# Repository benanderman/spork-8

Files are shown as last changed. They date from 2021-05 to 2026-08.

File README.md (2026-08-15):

# Spork-8

This is an 8-bit computer project, inspired by [Ben Eater's 8-bit breadboard computer](https://eater.net/8bit). It's made out of modular PCBs that plug into each other, and contain mostly 74HC-series chips (original 74LS). It runs code from an EEPROM (so it's only programmable from a computer), and has separate memory. It's meant to display what's happening, when running on a 555-timer or manually stepping, but also be capable enough to implement some sort of game, when using an oscillator as a clock.

## Status of project

The project was originally completed in 2021 and mostly worked with 74LS-series chips, but it had some issues (see [RevisionLog](RevisionLog.md)), and used way too much power.

In 2025, it was rebuilt with 74HC-series chips, and several improvements, an emulator, and peripheral boards. It had some issues, but mostly worked well.

In 2026, reliability was improved by adding ground planes to the bus boards and control board, the instruction set was improved, and much more complex programs were made.

## Modules
 * **Control module**: Coordinates everything else. Contains the micro-code EEPROMs, instruction register, micro-instruction counter, power input, reset button, and logic to interface with modules through bus boards.
 * **Bus**: Four of these interface between the control module and up to 16 other modules. These demux three signal lines each for in/out enable signals to the four modules connected to each bus board. One bus board plugs into the top of the control module, and one into the bottom. Two more bus boards plug into the first two. The first in/out signal line selects between the two boards on top / bottom, and the one connected to the control module inverts the signal before passing it onto the other bus board.
 * **Register**: Stores 8 bits, and can connect directly to an adjacent board above or below to expose its value (for use by the ALU and shift / rotate module). Has output headers, to interface with peripherals.
 * **ALU**: Performes calculations on values from register modules above and below it. Can output: add, subtract, bit-wise AND, or the carry-bit and zero-flag for any of those operations. Must be placed in the 1111 position (bottom right of top-most bus board), because the control module is hard-wired to input to the flags register when the read signal to that module position is enabled, which also enables flag output on the ALU.
 * **Clock**: Provides the clock pulse for the computer. Has three modes: manual with button to pulse, 555-timer with potentiometer to adjust timing, or crystal oscillator (2MHz seems to work).
 * **Counter**: Stores and counts 16-bit values. Uses two global signal lines to select which byte to read / write, and whether to enable counting. Used for both the RAM address register and program counter / program memory address register.
 * **RAM**: RAM or EEPROM (they have the same pinout). Used for the program memory EEPROM (not intended to be written to), and the static memory used for storing data. Up to 15-bits of address are taken from an adjacent counter module. Also has a cartridge slot, and switches between it and the EEPROM on the board using the 16th address bit. This allows swapping out programs much easier
 * **Input / Output**: Like a register module, except when outputting to the bus, outputs the value from input headers instead of the registers. The 8-bit value stored in the registers is accessible on output headers as well. The two headers are in parallel, making it sturdy to plug in a peripheral that uses both.
 * **Battery**: Has a battery, charging capability with USB-C, and a switch to output power to the CPU.

## Layout

In general, any of the 16 module slots can input from or output to the bus, so most modules could go in any position. However, some of them have to go in specific slots, because:

1. The 0th slot on the top and bottom aren't usable for in/out selection, because it's ambiguous whether that slot is selected or if no module on that side is selected. The battery and clock go in those slots, since they only output power and a clock signal, and don't use the bus.
1. The 8 "custom" signals (that mean something different for different modules) are split up into 4 for top, 4 for bottom. Those 4 are split into pairs; the top 2 modules on each bus board get one pair, and the bottom two get the second pair. The second pair of signals on the bottom is actually used by the control board.
1. Some modules (RAM / ROM, ALU, and Shift) get inputs from other modules, so their inputs have to be next to them.

**Top left**: The program counter goes in the top to use the first pair of custom signals (for count and byte select), plugging into the program memory below it. Below that is the clock (in the 0th position), and Register C.

**Top right**: The ALU goes one slot down from the top, to use the second pair of custom signals (for add/subtract and bit-wise AND), with register A and B as its operands above and below. Then the shift / rotate module goes at the bottom plugging into register B. These need to be on the right side to avoid the 0th position. The shift module shares custom signals with the ALU, which is okay because only one is used at a time, and the signals don't have an effect if that module isn't outputting.

**Bottom left**: The battery takes the top 0th slot, and then the stack and swap registers, and input / output A module after that. Other than the battery, the positions are arbitrary.

**Bottom right**: The output A register goes at the top and the RAM goes below it. The memory address register goes in the next position to get the first pair of custom signals (for count and byte select), and plugs into the RAM above it. The input / output B module goes at the bottom. The memory address could instead go where output A is, and RAM just needs to be next to it. The other two could go anywhere.

## Peripherals
* **Controller Connector**: Plugs into IO module, and has two RJ12 plugs on it, to connect to parallel-to-serial shift register-based controllers.
* **Screen**: An 10x20 595-shift register-based monochrome display. Plugs into output module (vertically), or IO module (horizontally).
* **Cartridge**: A small board with a surface-mount version of the same 28C256 EEPROM used as in the program memory module. Plugs into the program memory module with the smallest PCIe board edge connector.
* **Programmer**: Arduino-based board used to program and test the CPU in 3 ways:
    1. Separate from the CPU, read / write to EEPROMs (big ones, or cartridges).
    2. Plug into bus boards, to test all the modules plugged in (doesn't work, because the bus is needed to set the signals, but that could cause bus contention).
    3. Replace the program memory and clock, to have a very fast development cycle to write program code (not necessary now that there's an emulator), or to test the CPU.
 
## Layout, signals, and parts list
These images show the layout of the modules in the 16 slots, the functions of each of the signals, and a parts list.
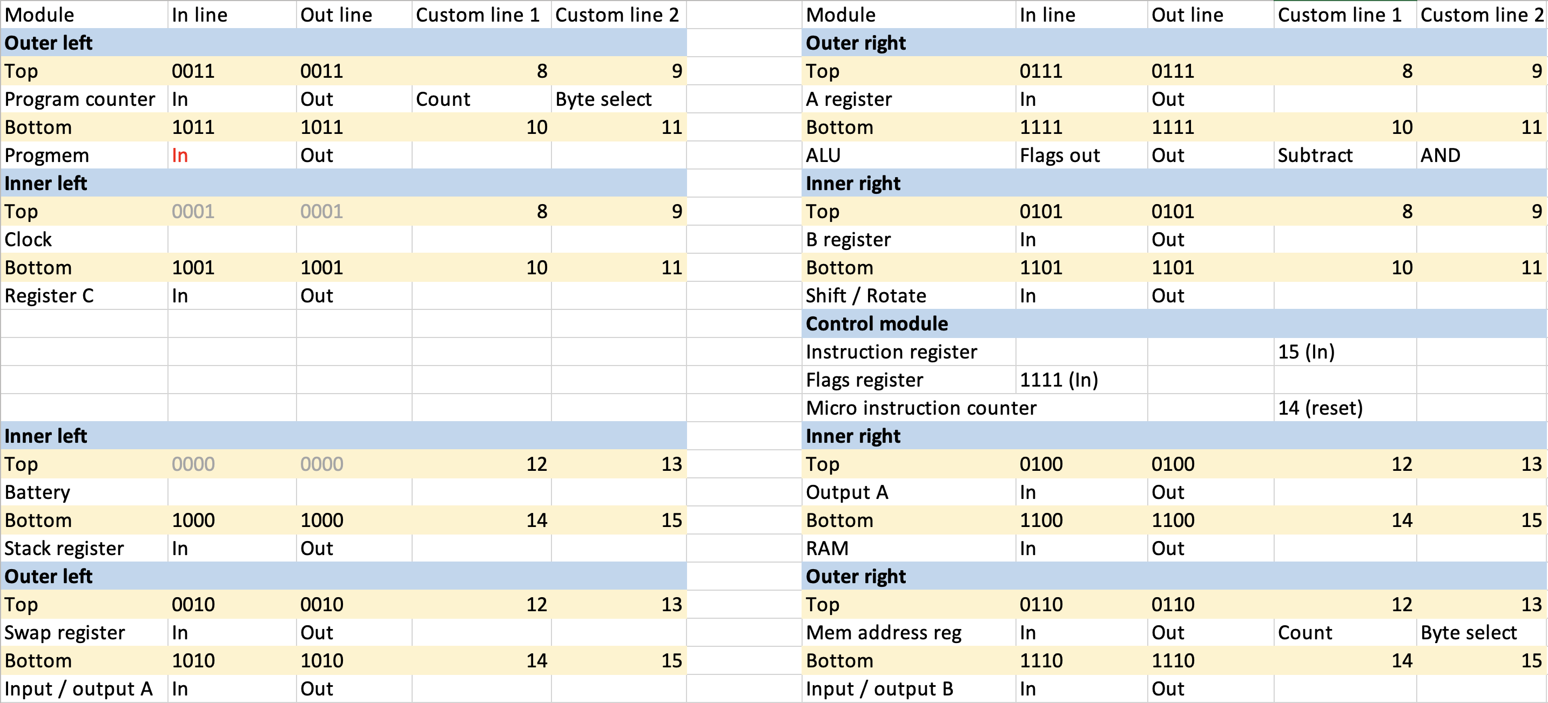
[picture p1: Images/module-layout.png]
Module layout

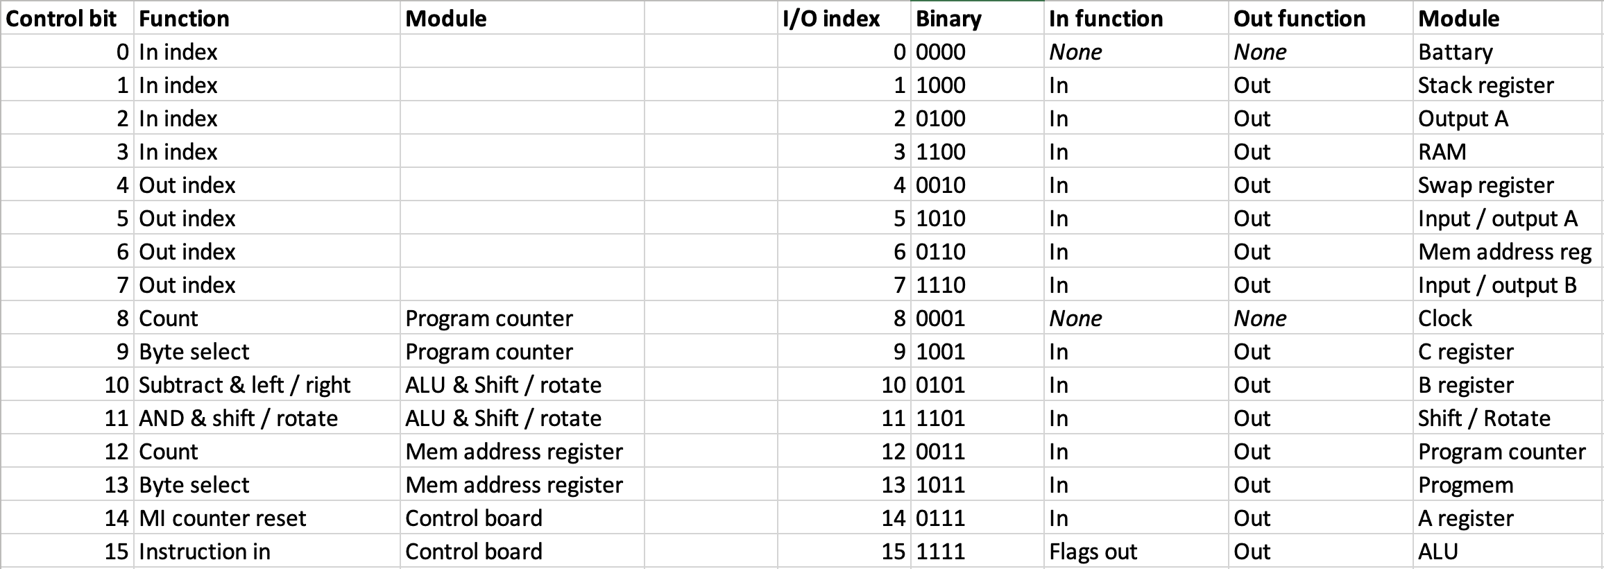
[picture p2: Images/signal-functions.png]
Signal functions

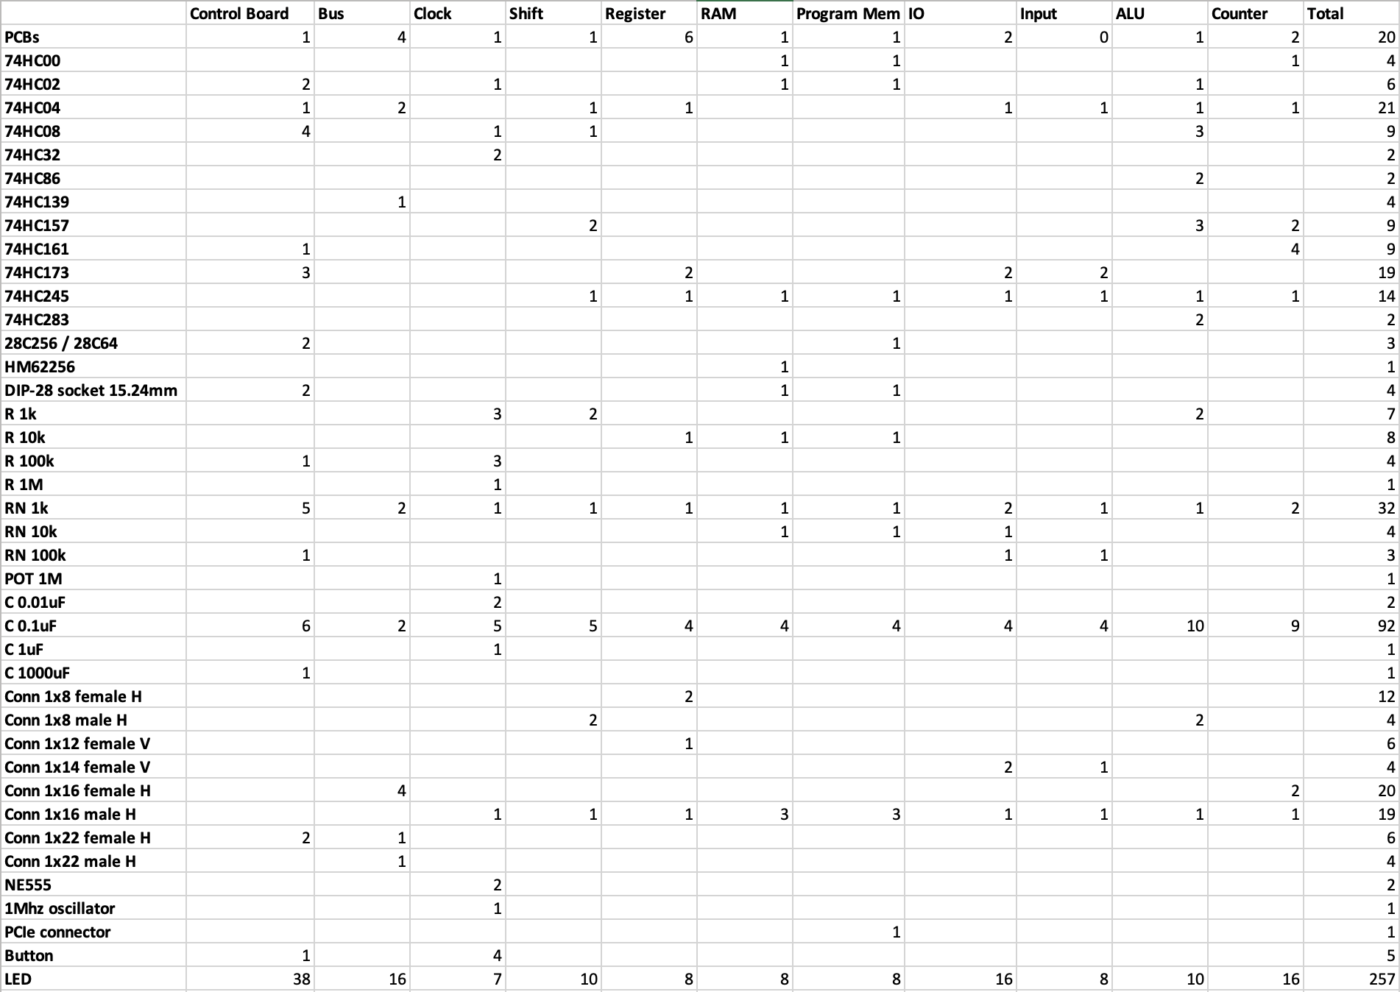
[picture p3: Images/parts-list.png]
Parts list


## Design images
### Overall layout
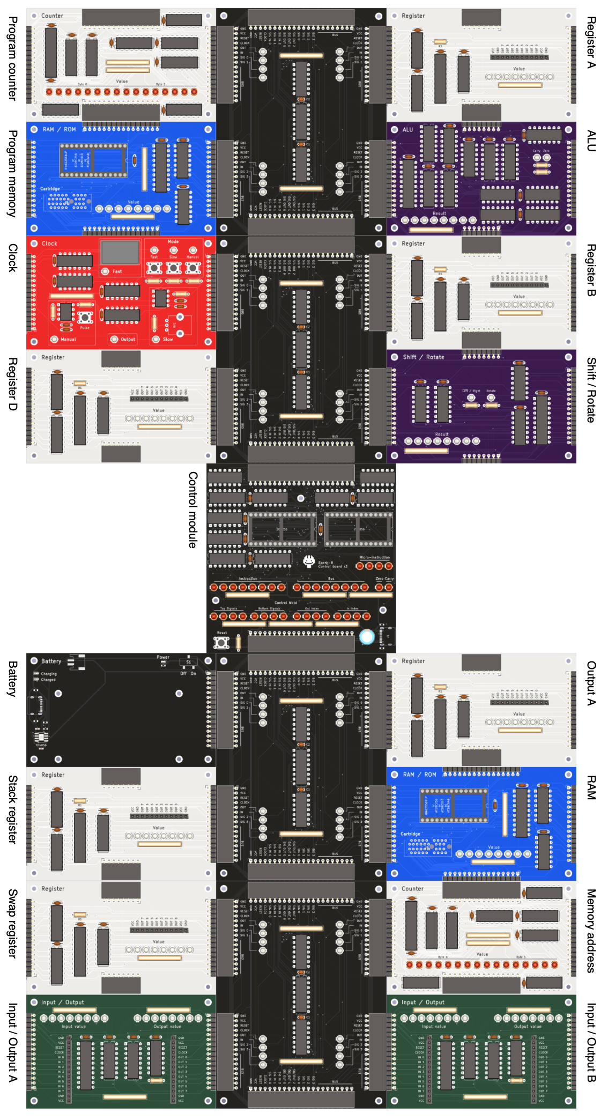
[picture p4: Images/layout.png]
Layout of the CPU


### Mounting board (laser cut acrylic)
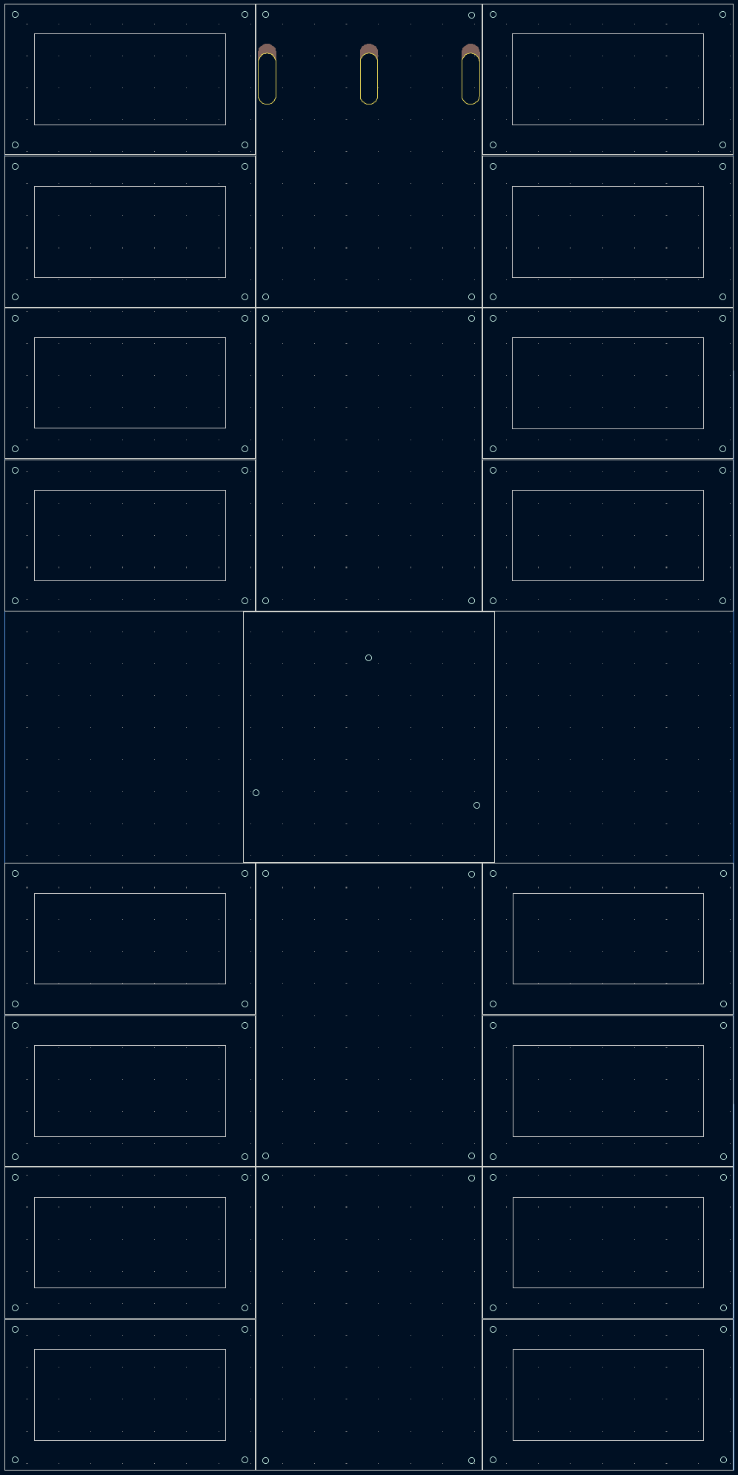
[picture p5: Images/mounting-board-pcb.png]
Mounting board design


### Schematics
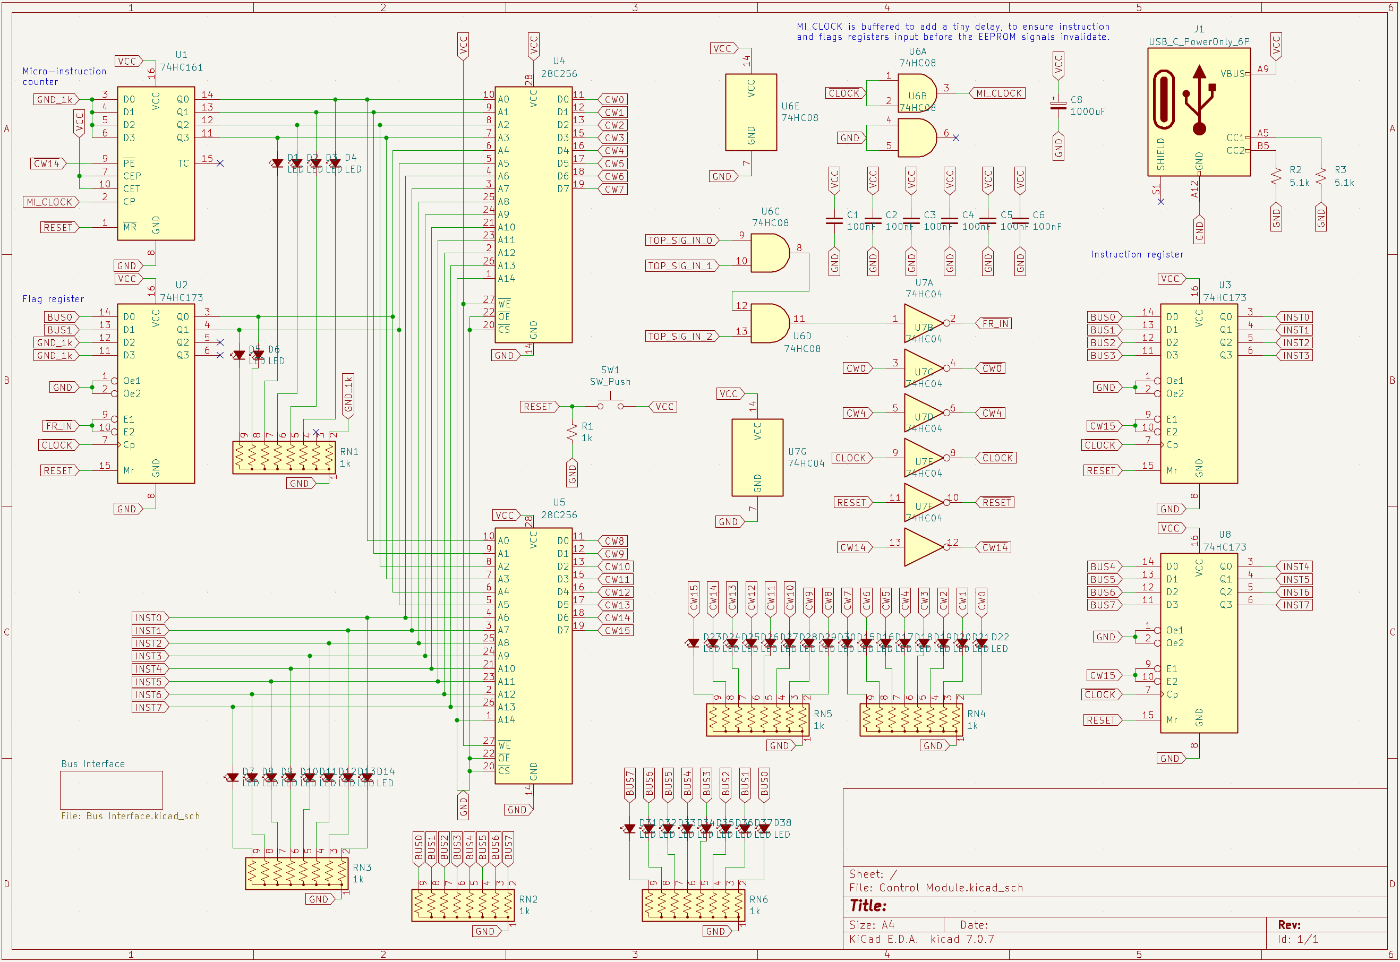
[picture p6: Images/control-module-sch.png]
Control Module schematic

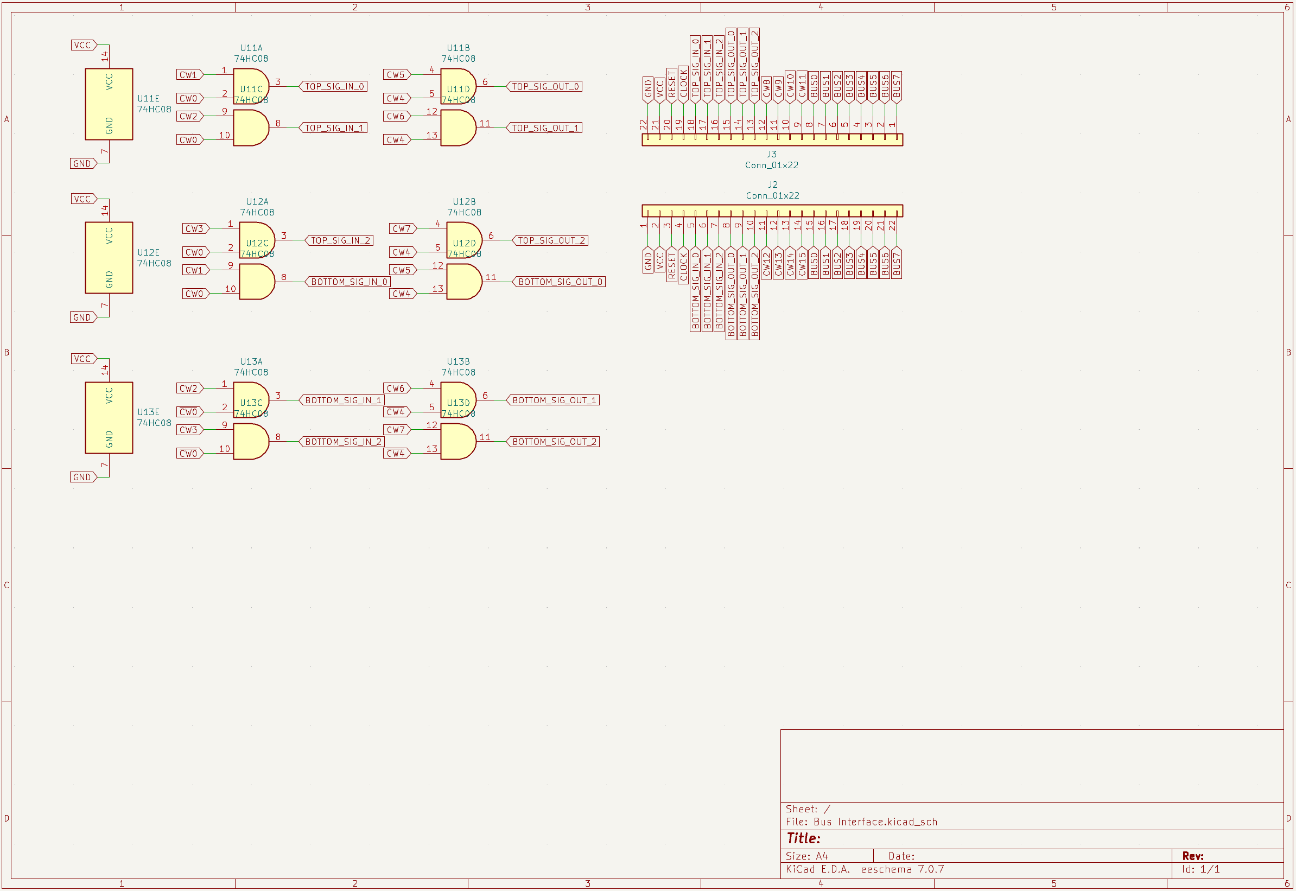
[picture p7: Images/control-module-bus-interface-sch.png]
Control Module bus interface schematic

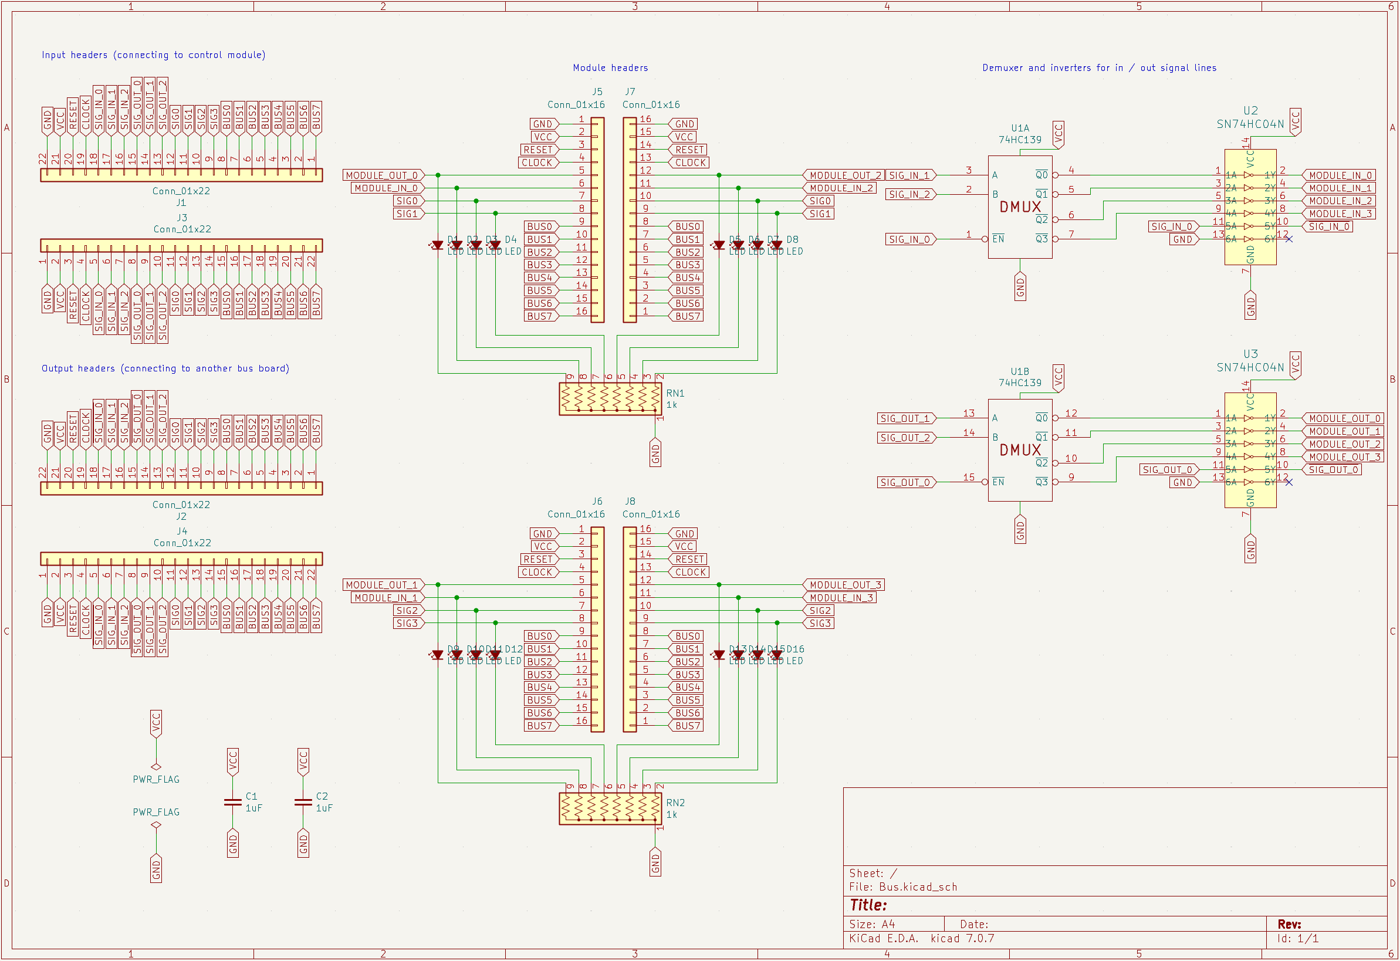
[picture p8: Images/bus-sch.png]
Bus schematic

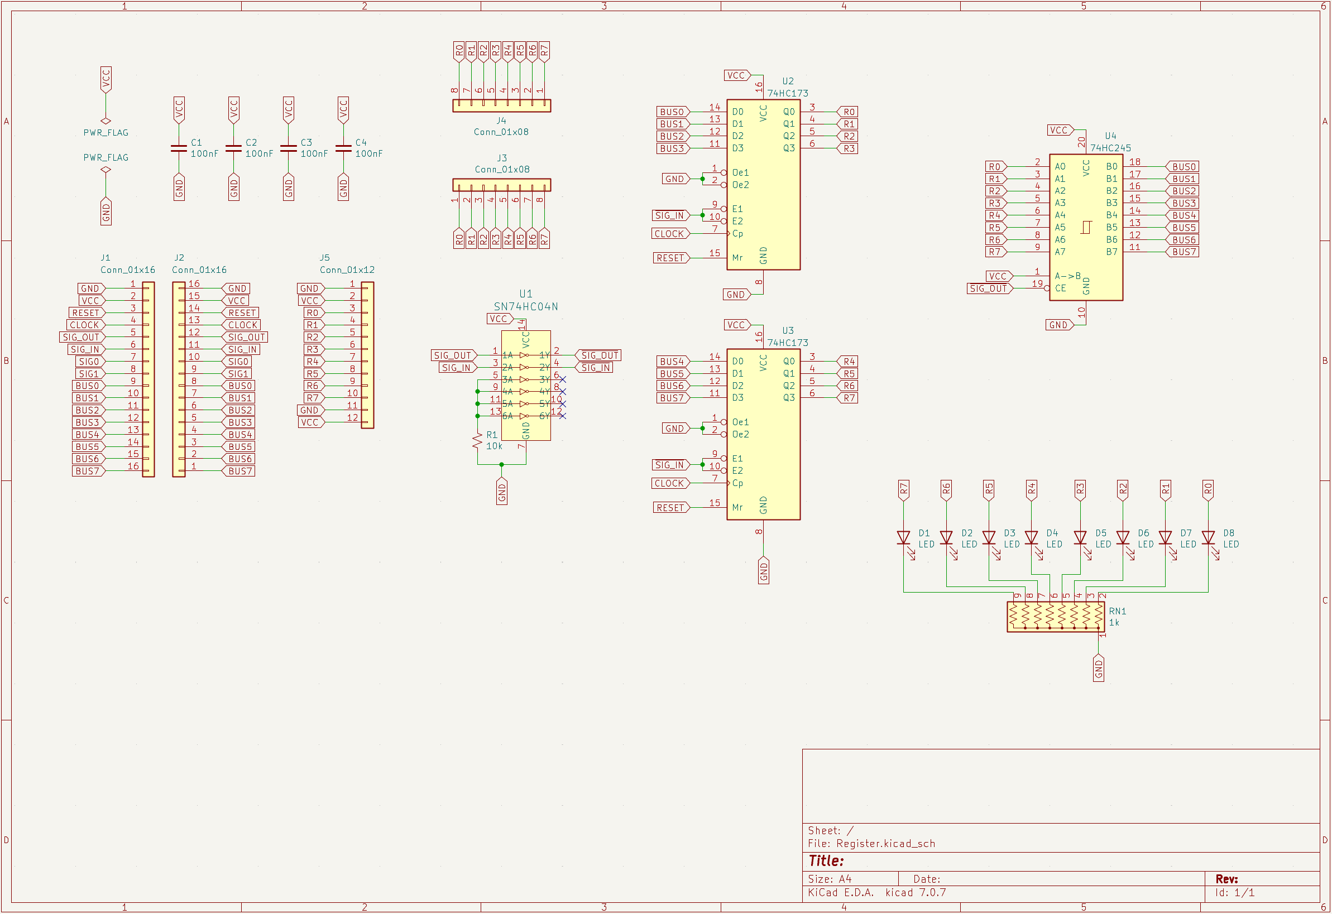
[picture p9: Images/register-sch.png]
Register schematic

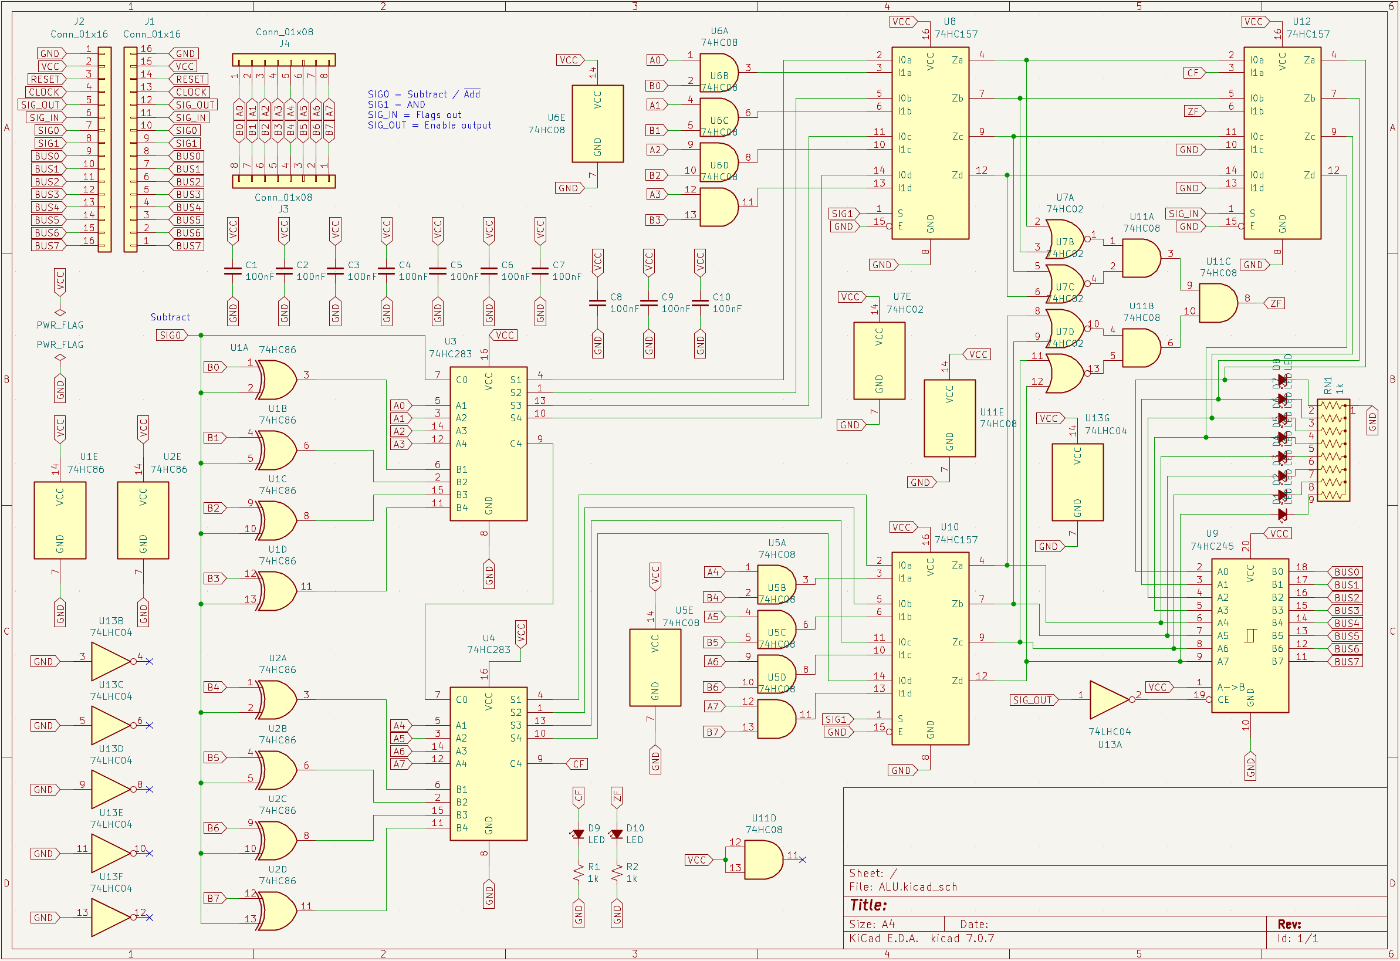
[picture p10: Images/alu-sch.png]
ALU schematic

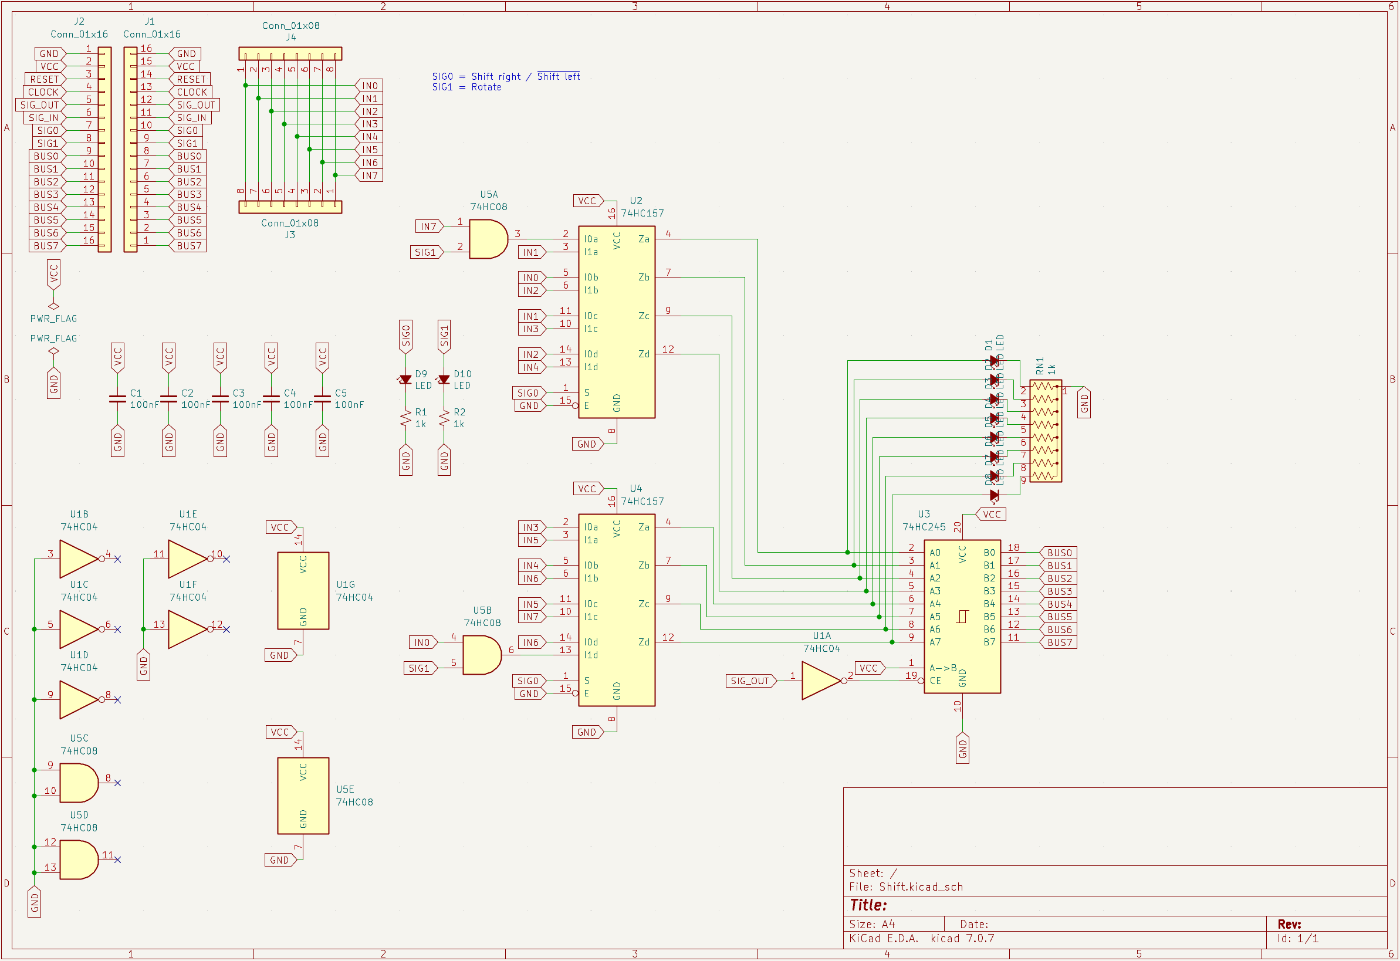
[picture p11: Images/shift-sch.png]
Shift / Rotate schematic

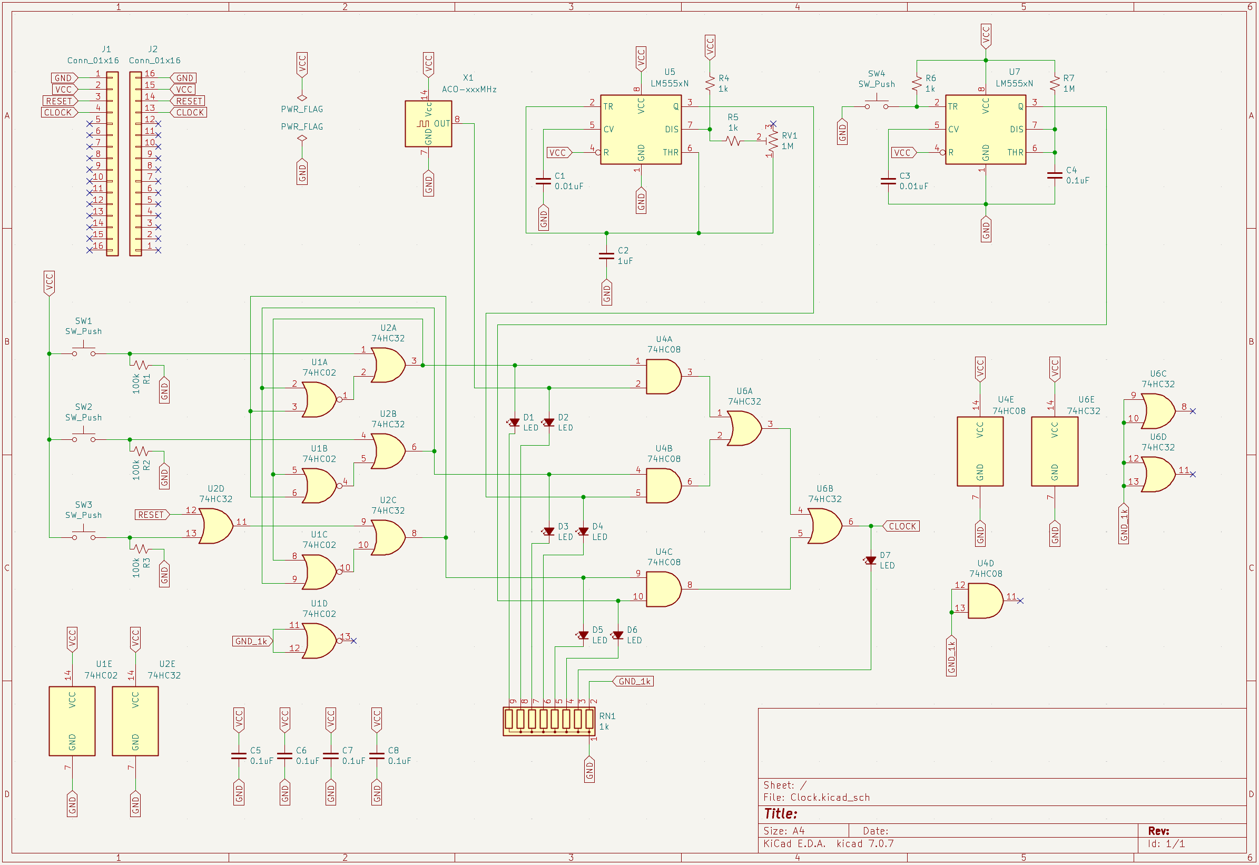
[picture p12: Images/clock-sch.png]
Clock schematic

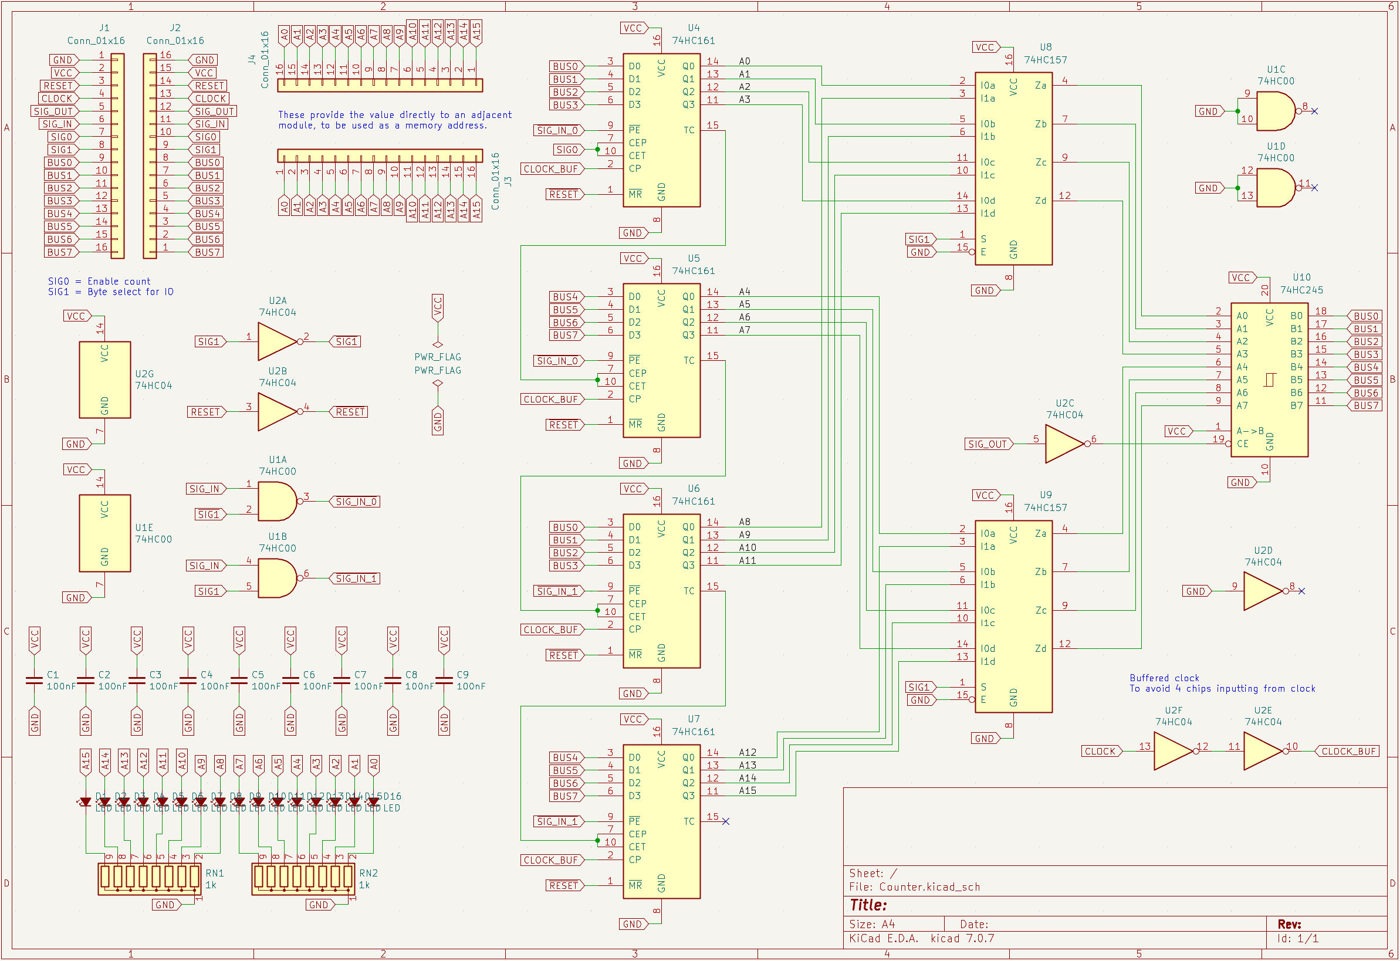
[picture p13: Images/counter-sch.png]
Counter schematic

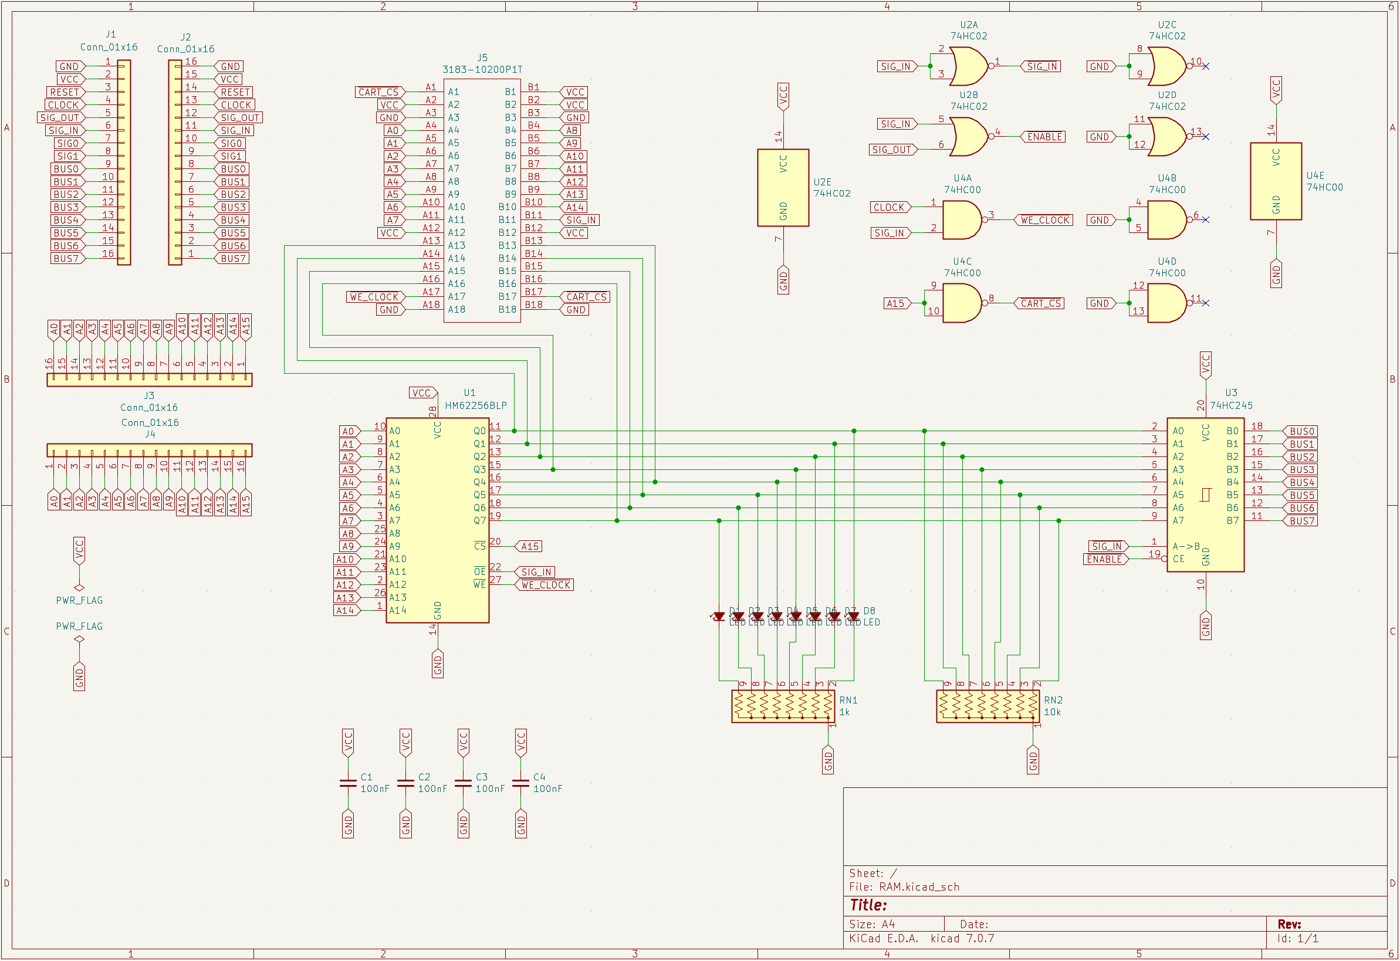
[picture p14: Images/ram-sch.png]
RAM schematic

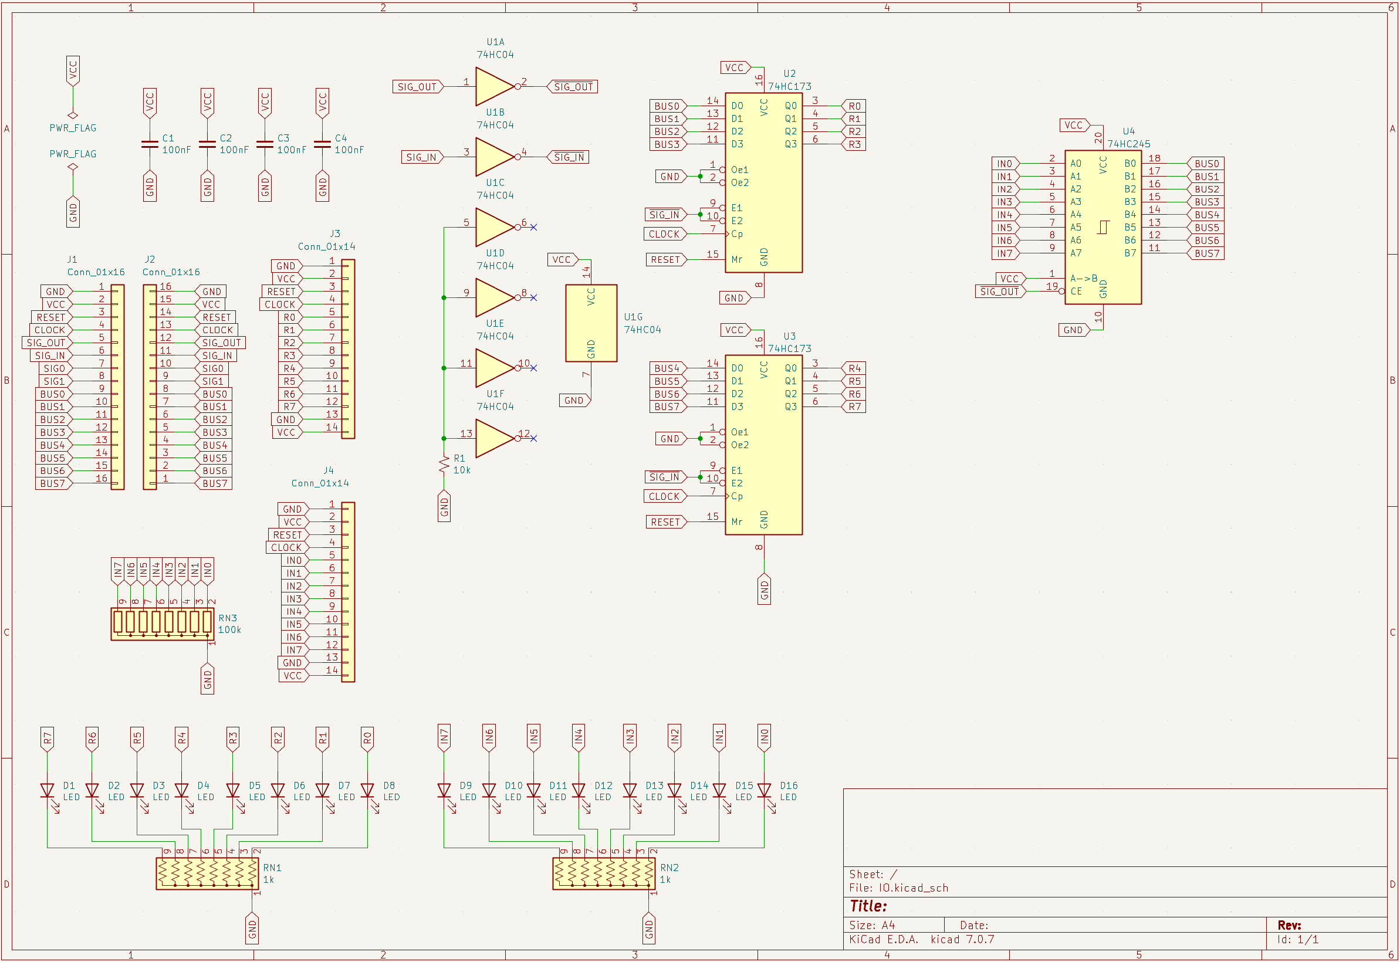
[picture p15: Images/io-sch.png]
Input / Output schematic

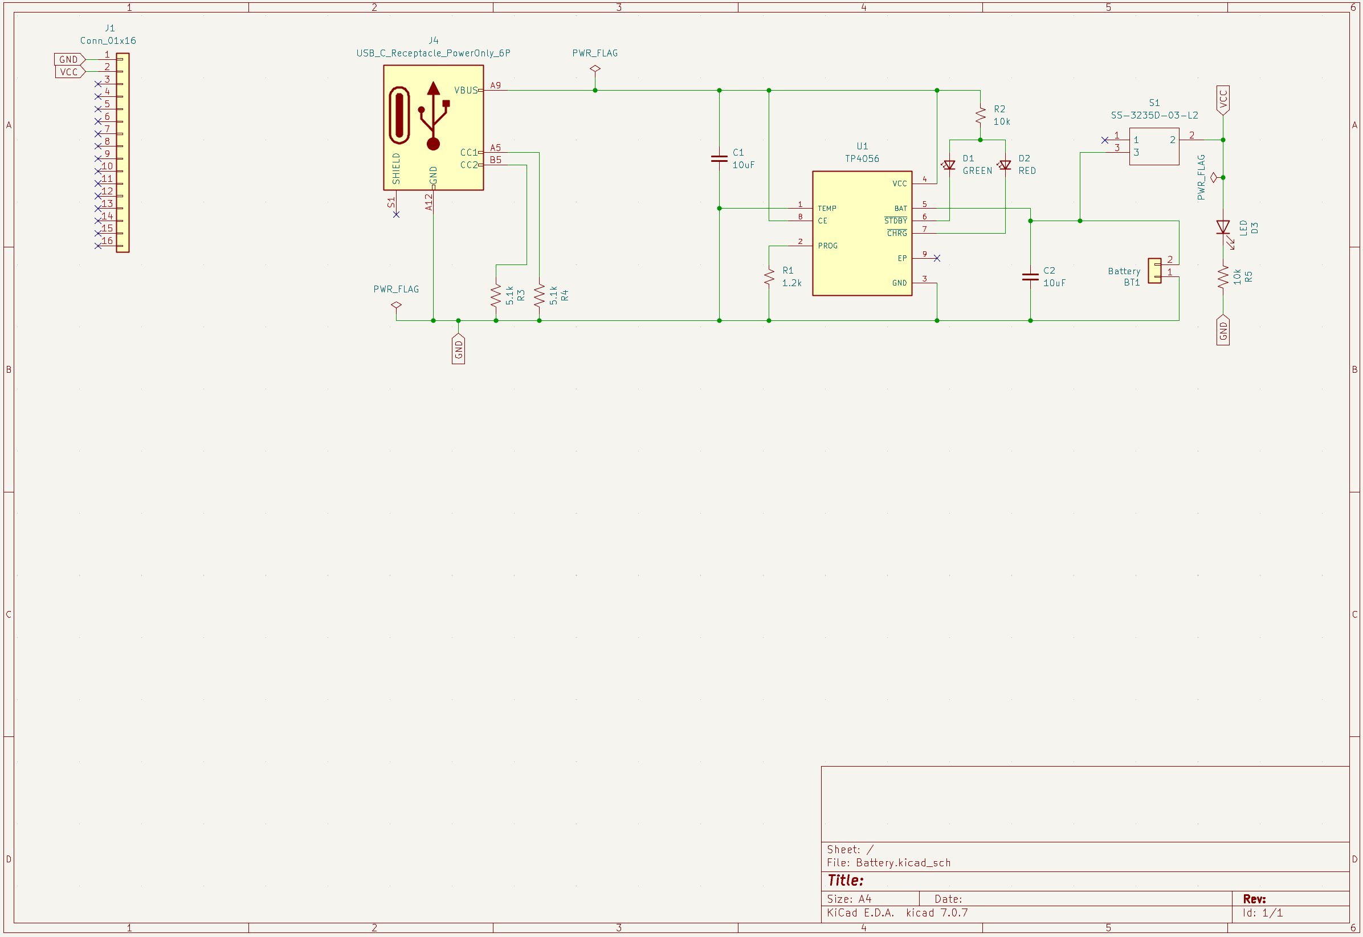
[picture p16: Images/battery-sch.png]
Battery schematic

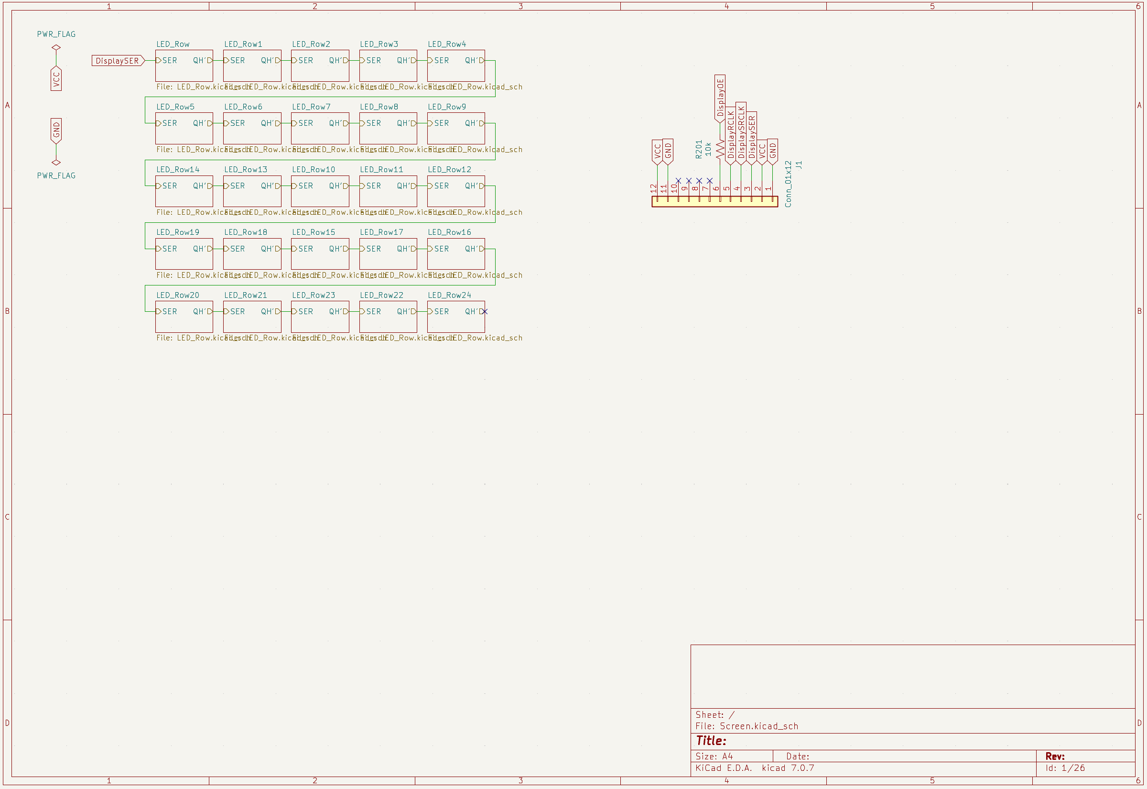
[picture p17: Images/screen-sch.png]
Screen schematic

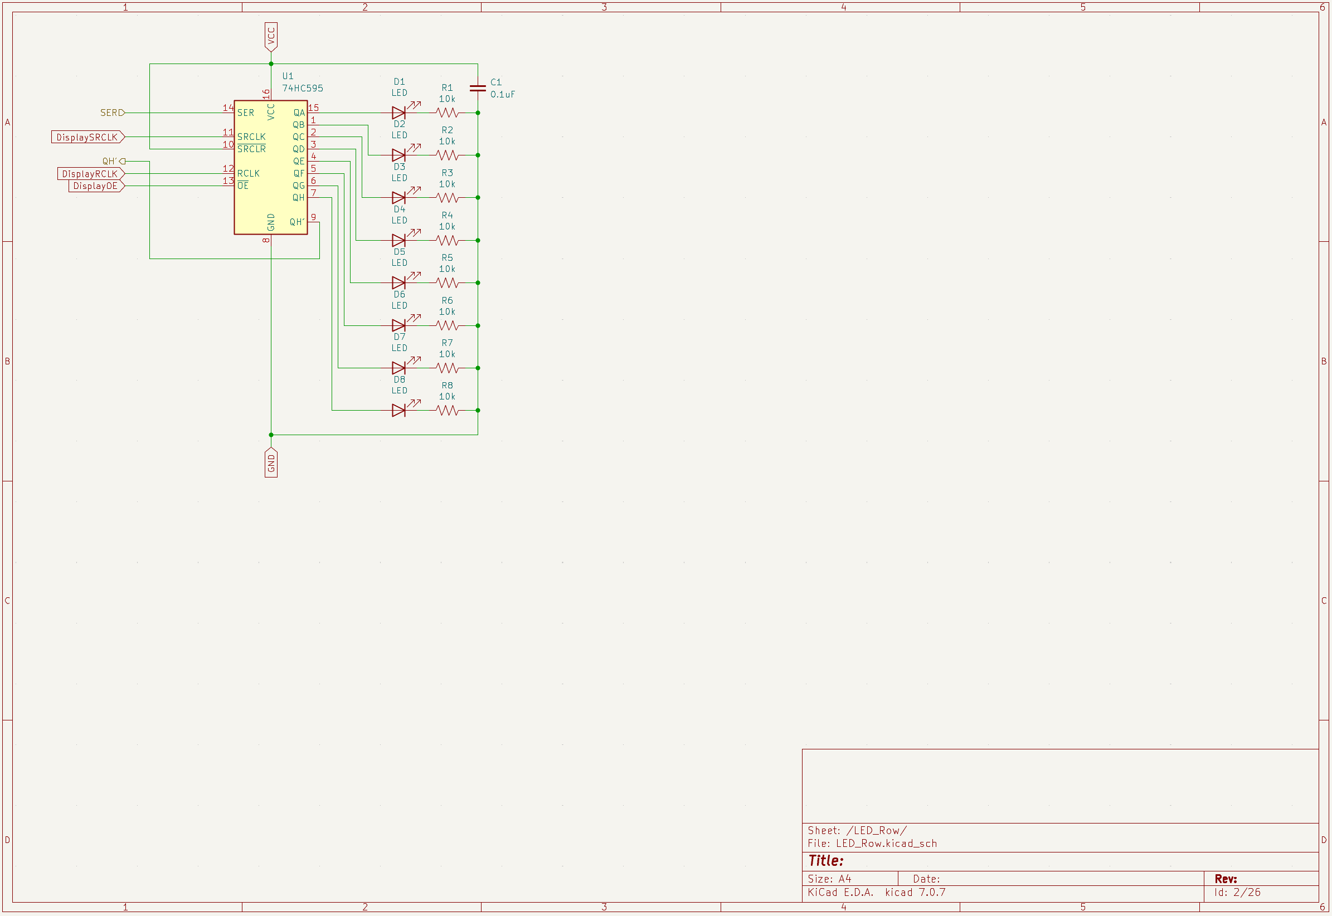
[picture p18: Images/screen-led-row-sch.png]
Screen schematic

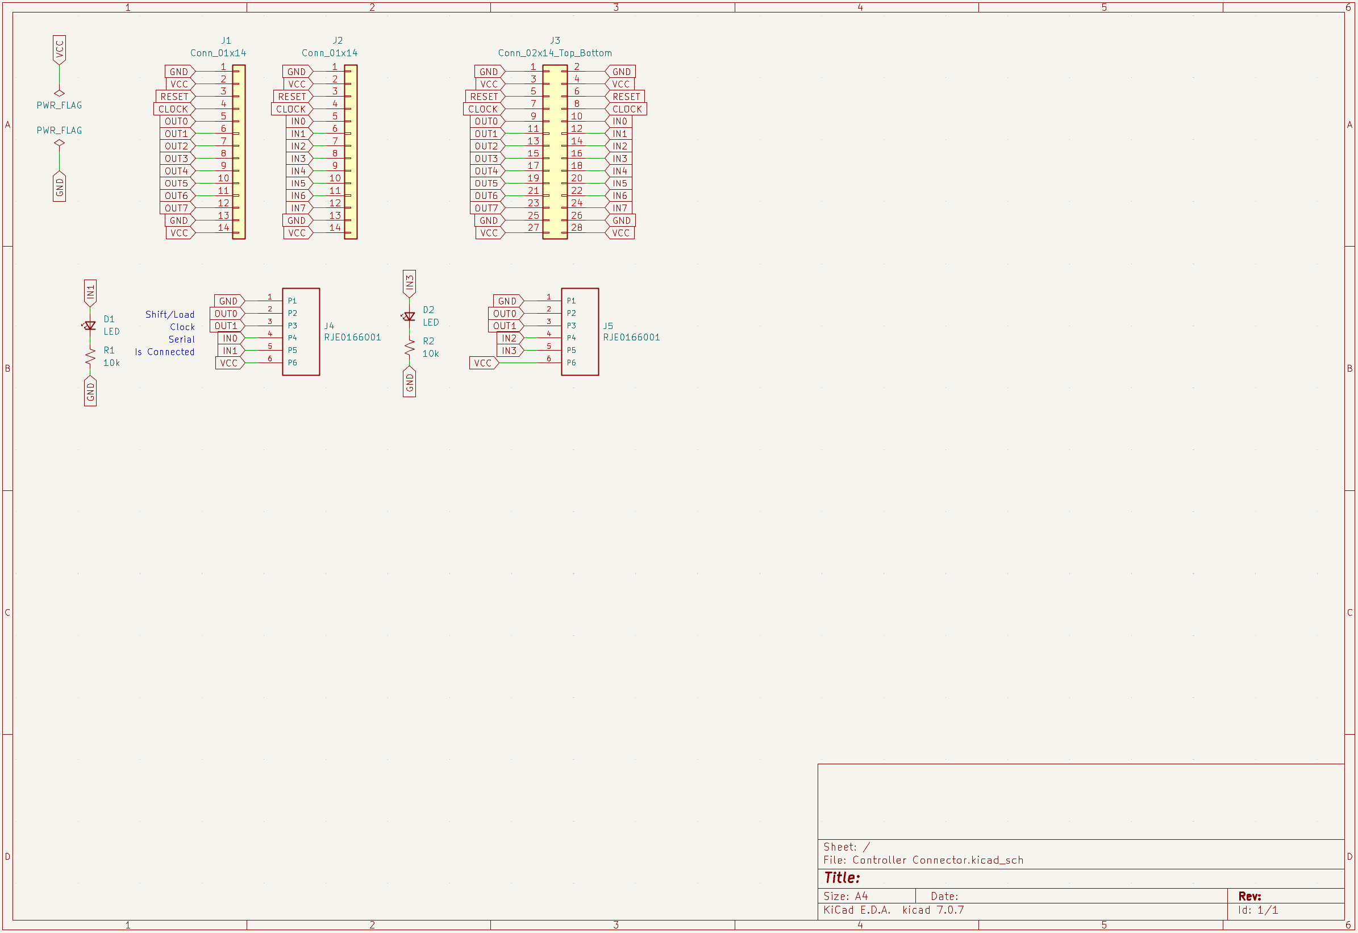
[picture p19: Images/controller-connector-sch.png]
Controller Connector schematic

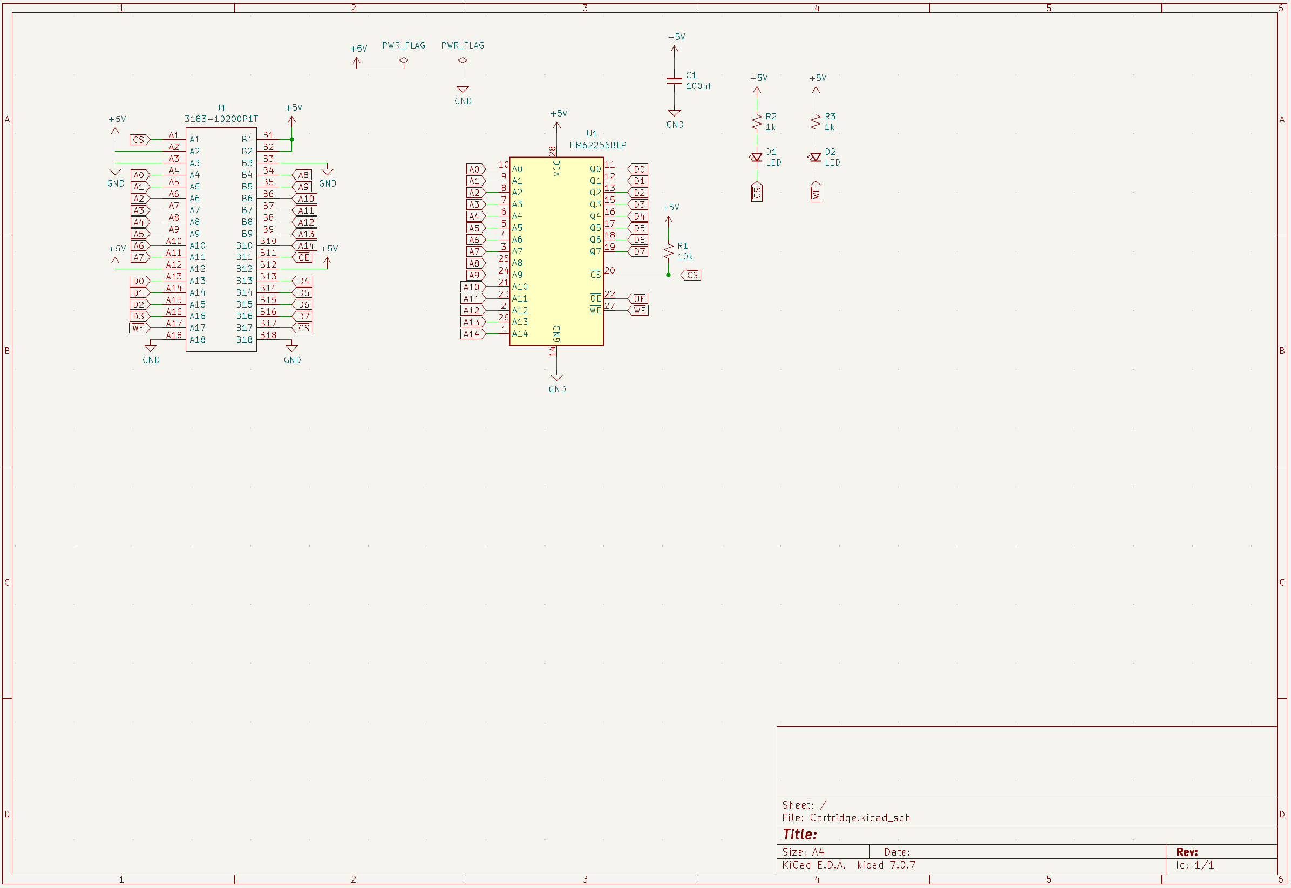
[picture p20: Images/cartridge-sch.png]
Cartridge schematic

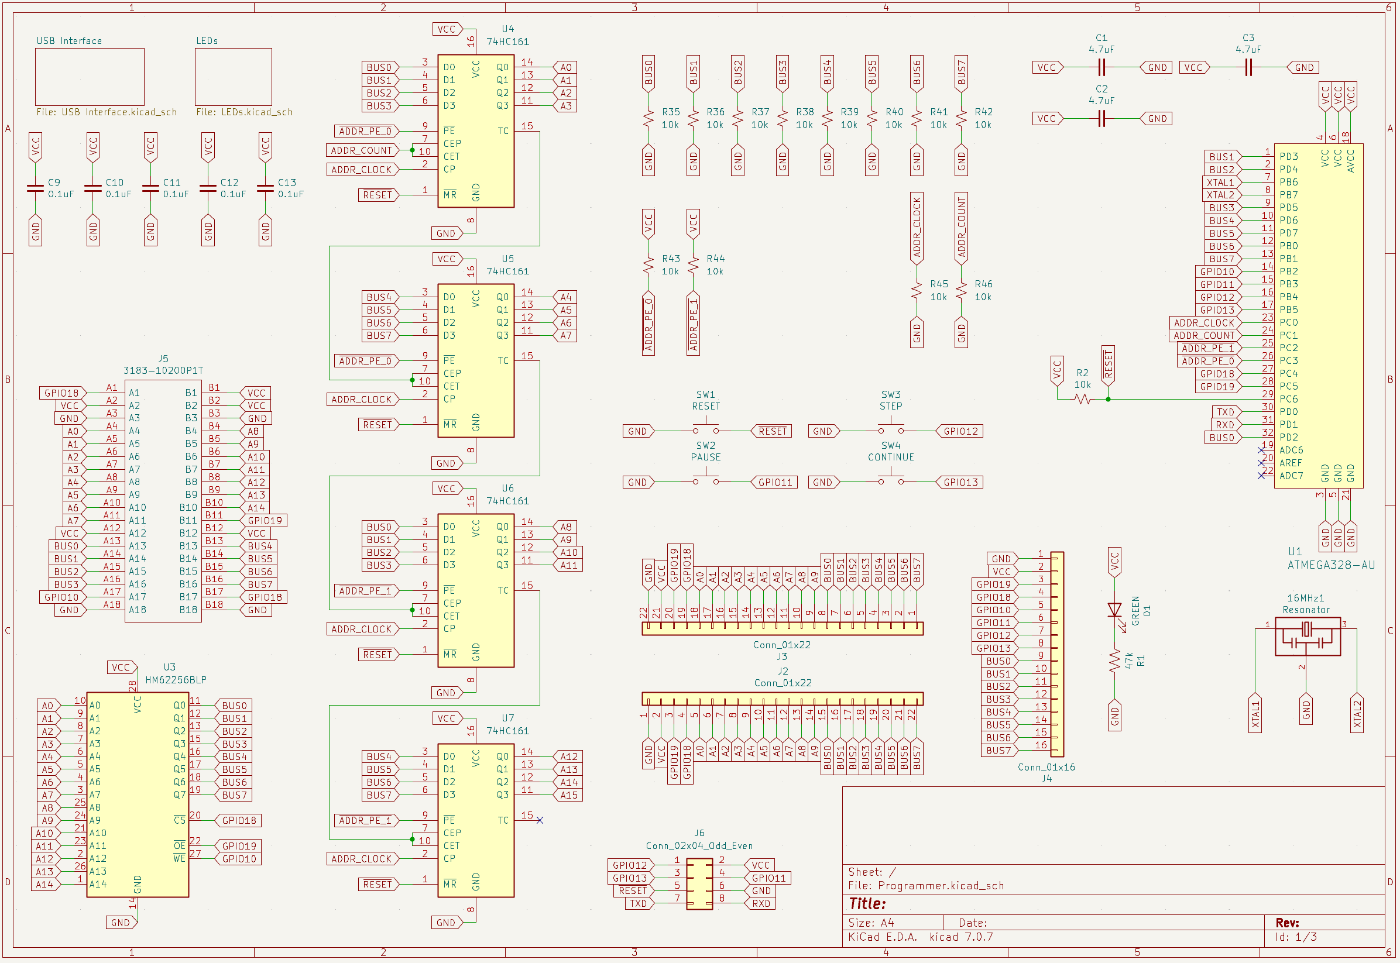
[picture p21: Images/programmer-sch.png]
Programmer schematic

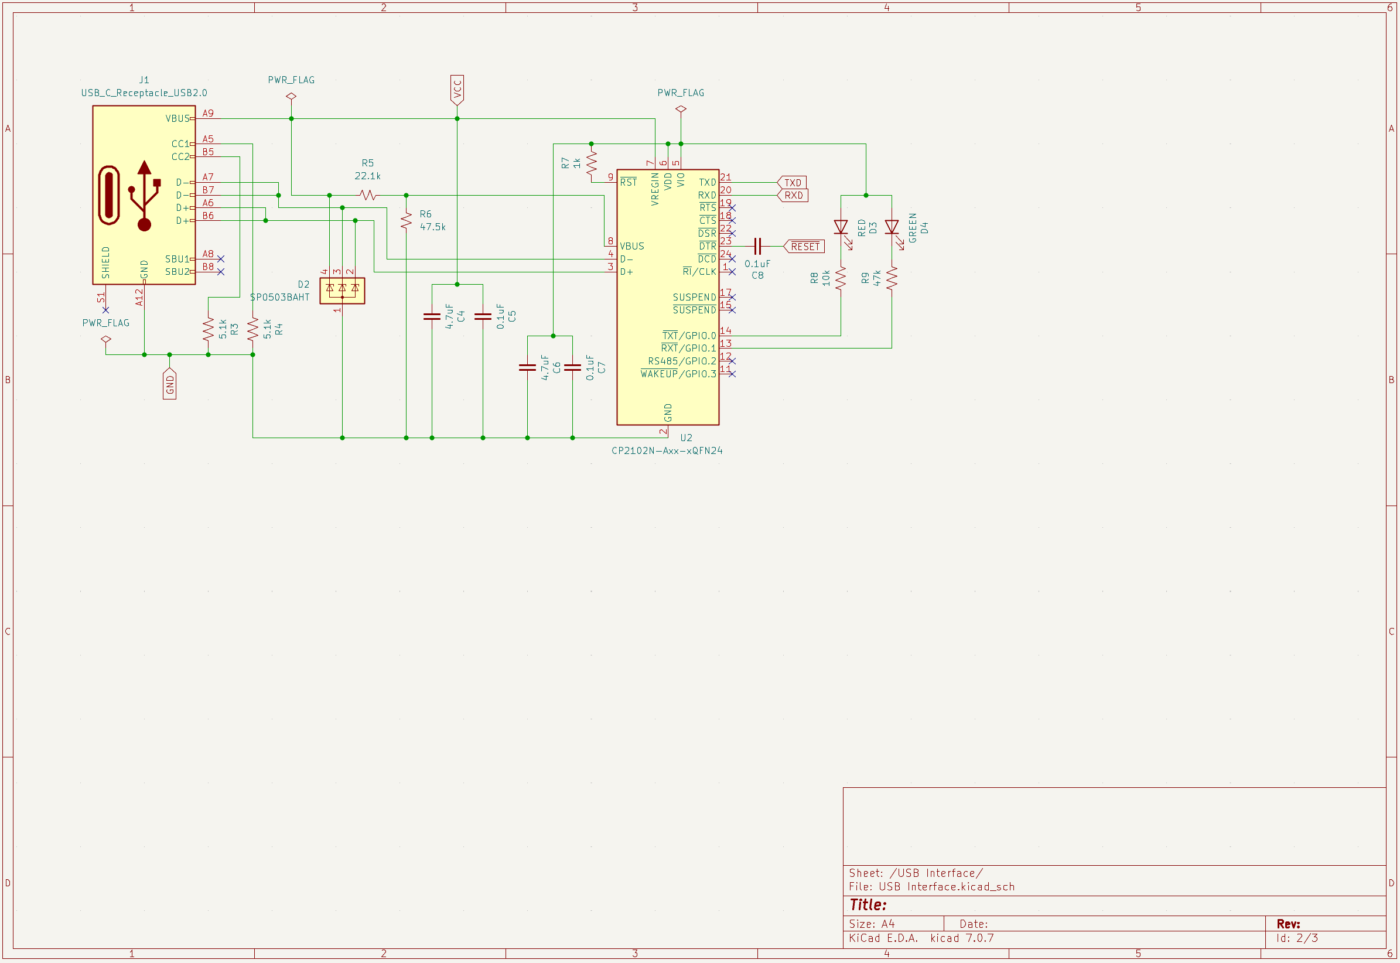
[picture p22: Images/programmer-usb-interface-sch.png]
Programmer USB Interface schematic

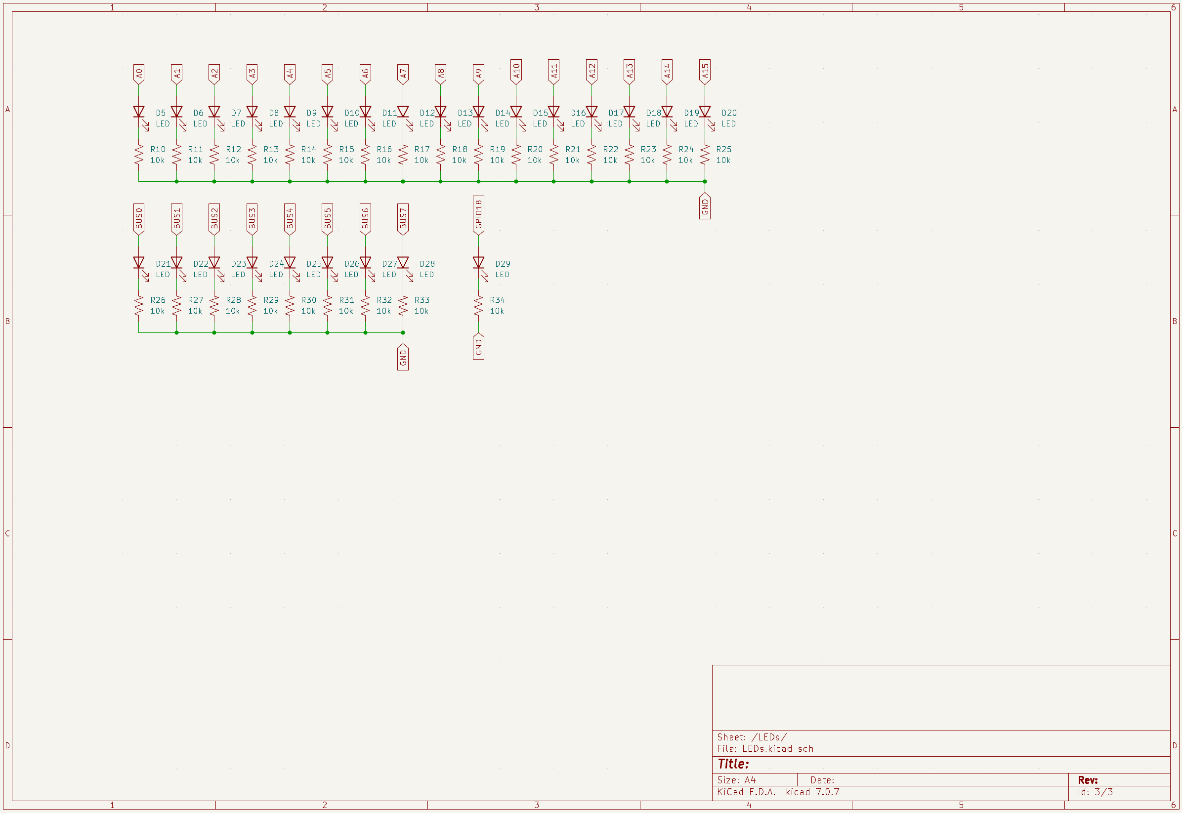
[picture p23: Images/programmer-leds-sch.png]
Programmer LEDs schematic


### PCB Layouts
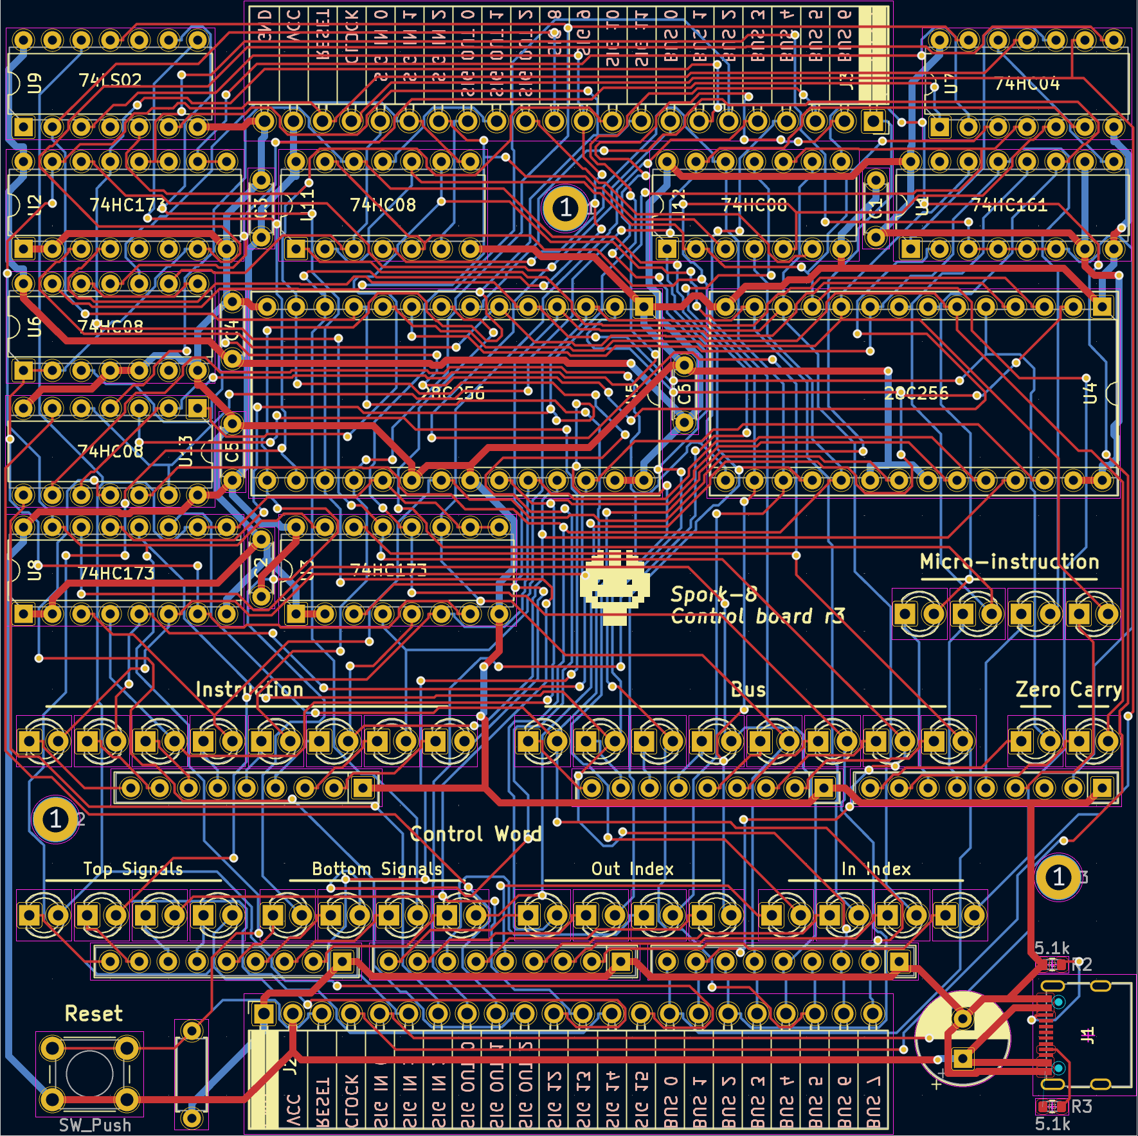
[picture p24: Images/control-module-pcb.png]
Control Module PCB layout

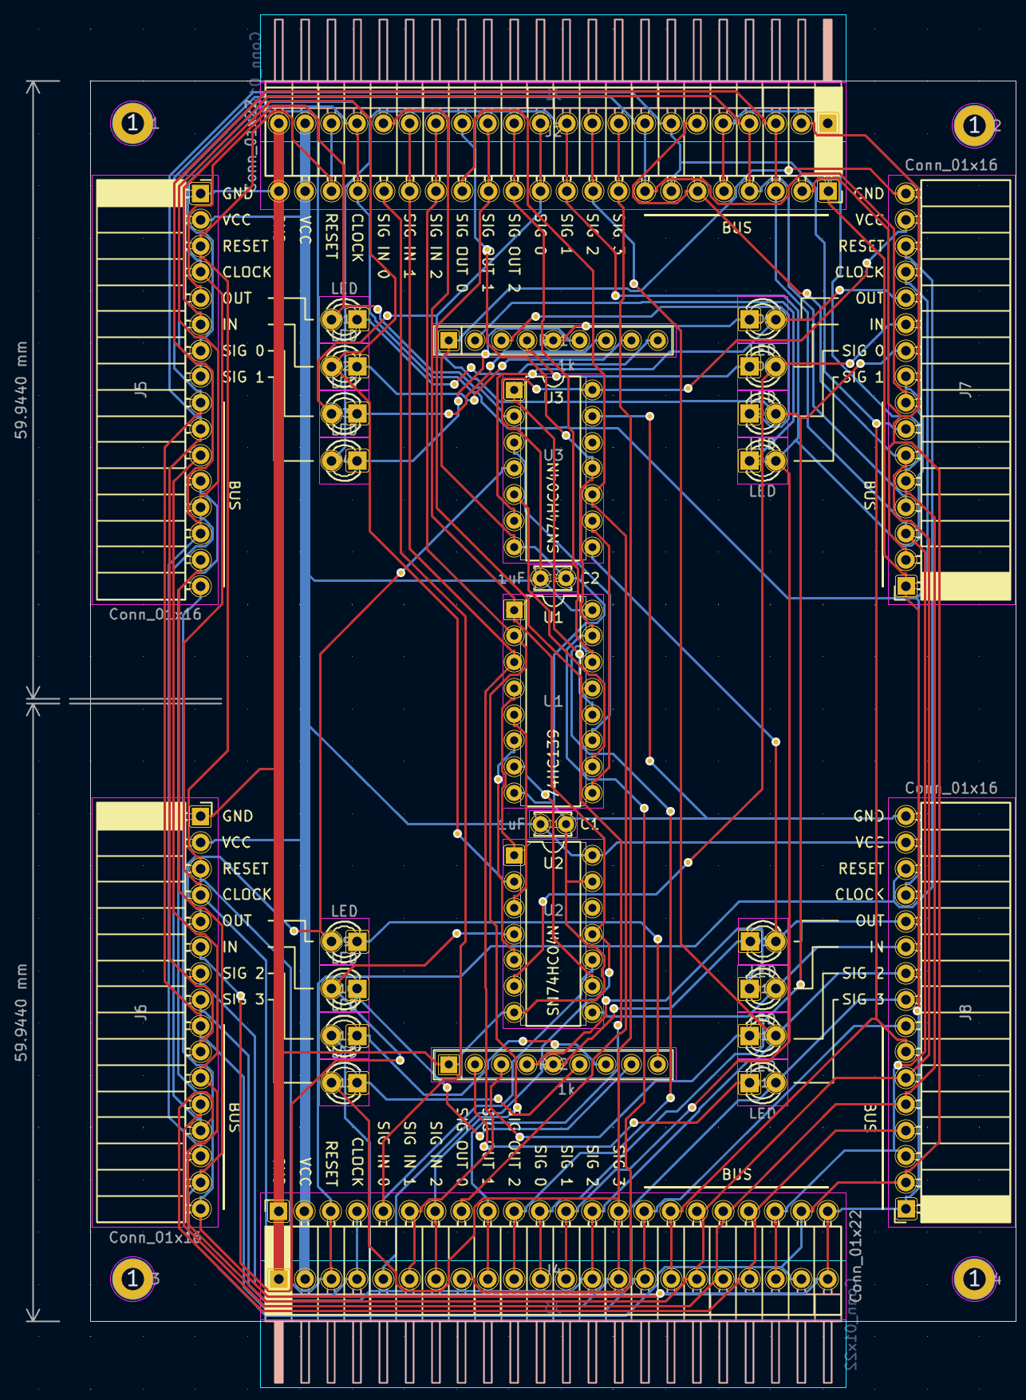
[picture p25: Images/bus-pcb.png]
Bus PCB layout

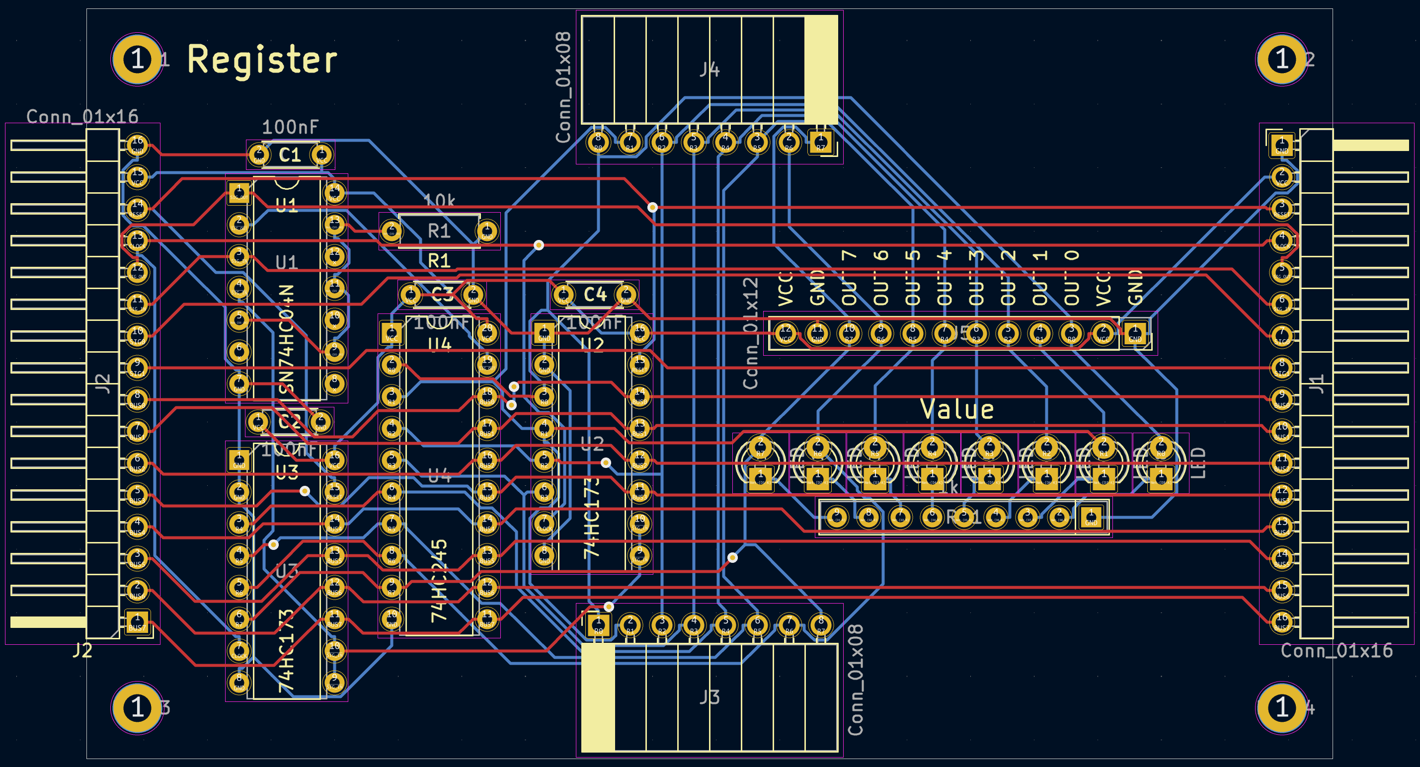
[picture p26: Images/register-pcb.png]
Register PCB layout

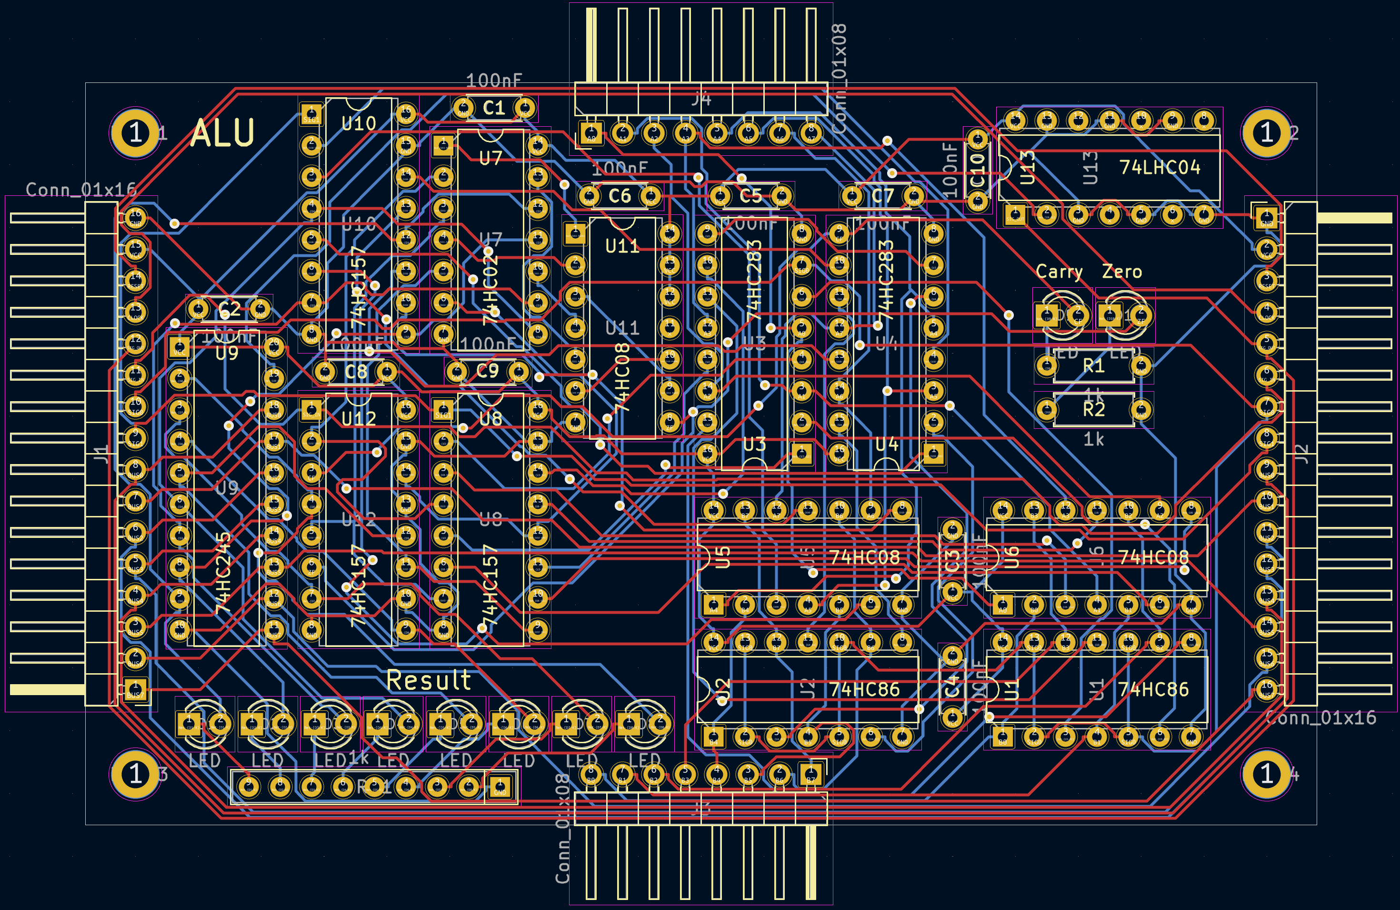
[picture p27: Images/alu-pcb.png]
ALU PCB layout

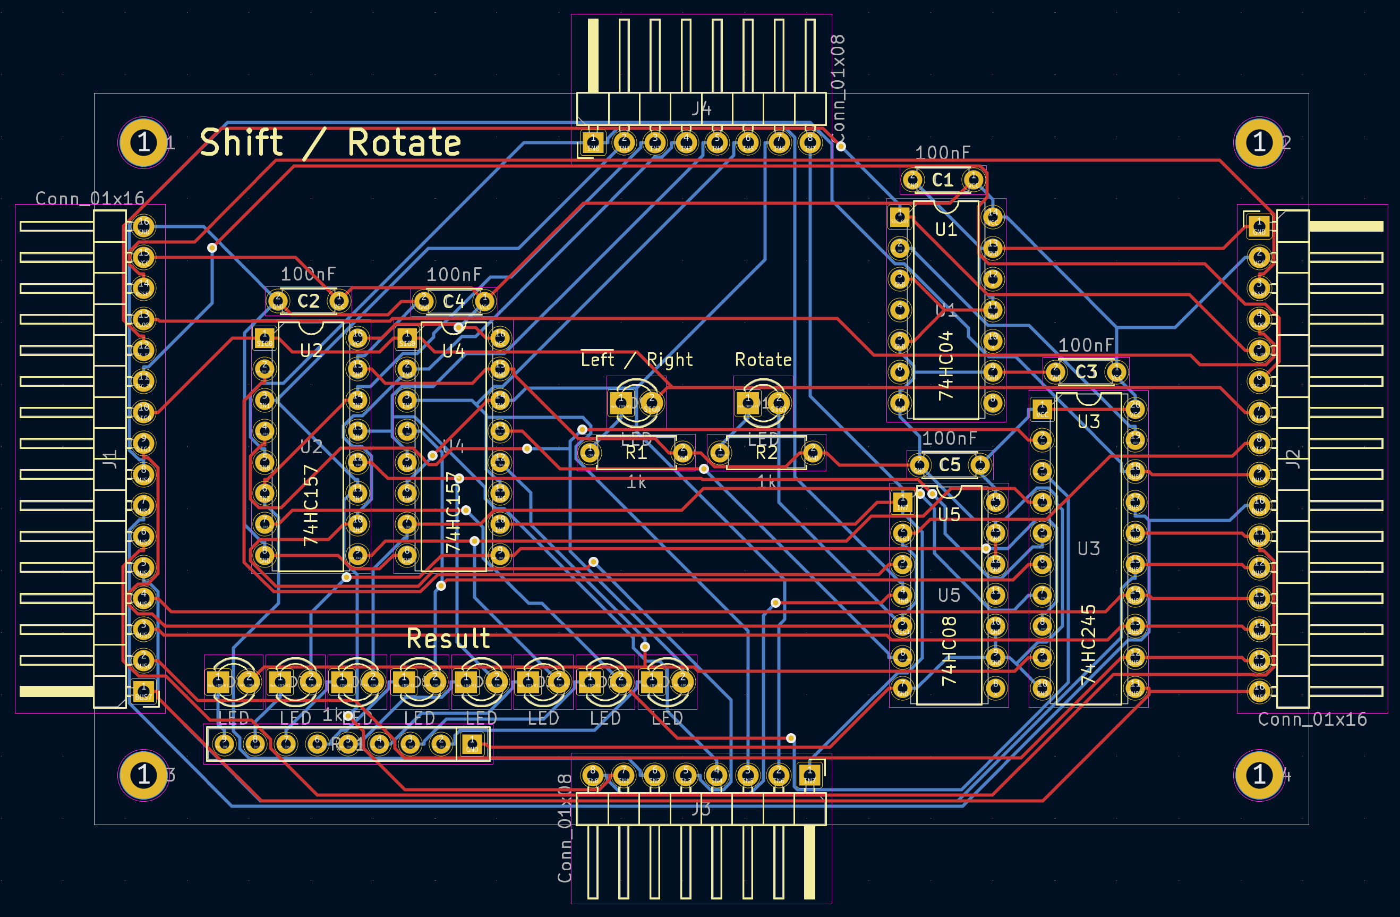
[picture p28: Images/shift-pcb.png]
Shift / Rotate PCB layout

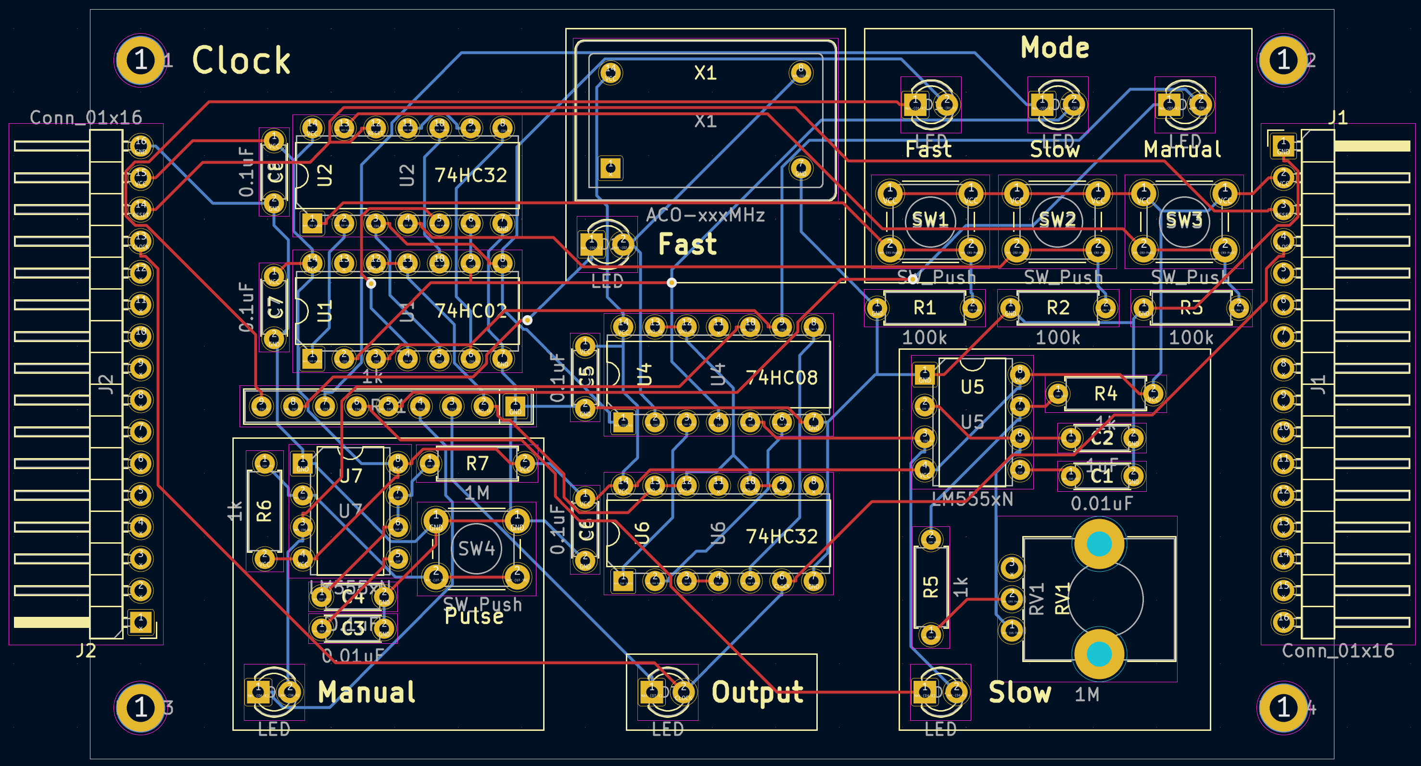
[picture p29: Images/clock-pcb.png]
Clock PCB layout

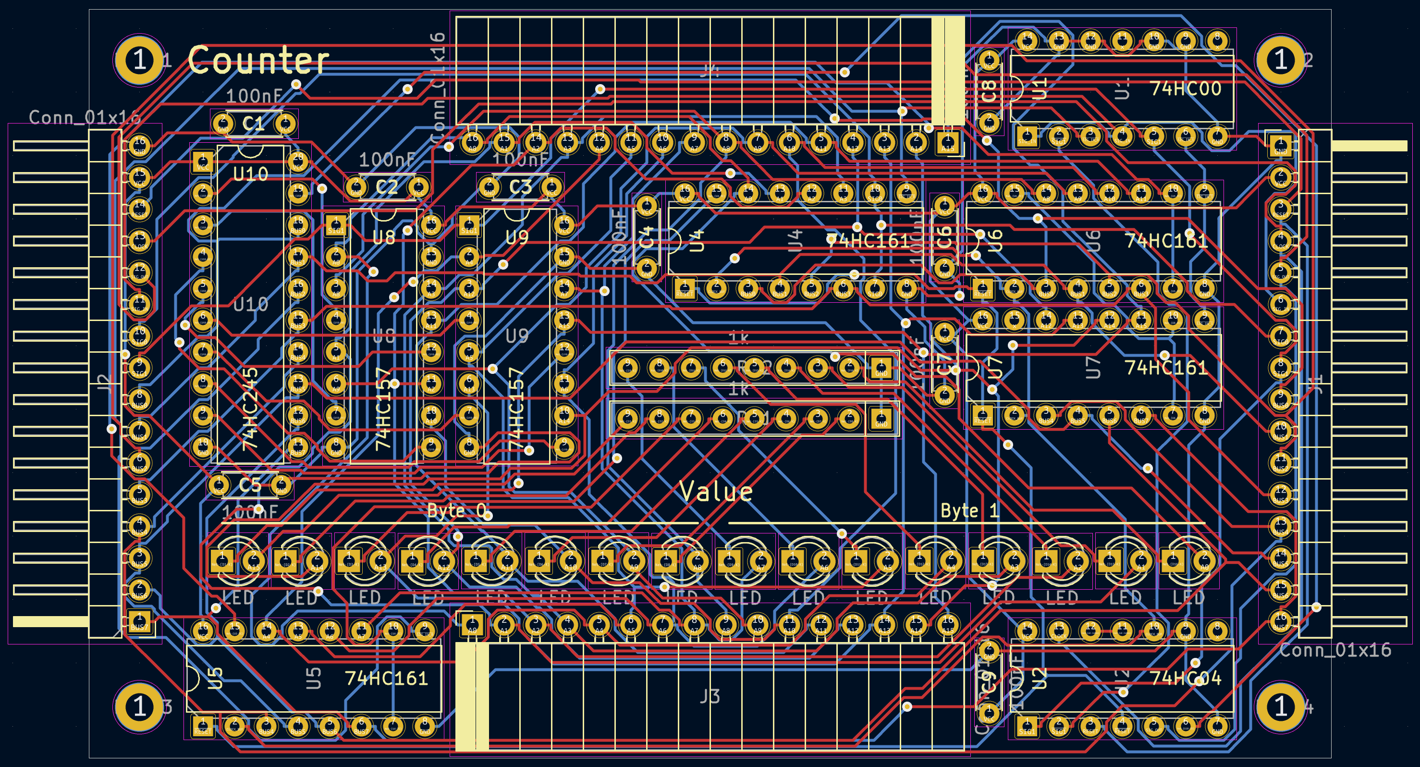
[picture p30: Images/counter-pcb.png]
Counter PCB layout

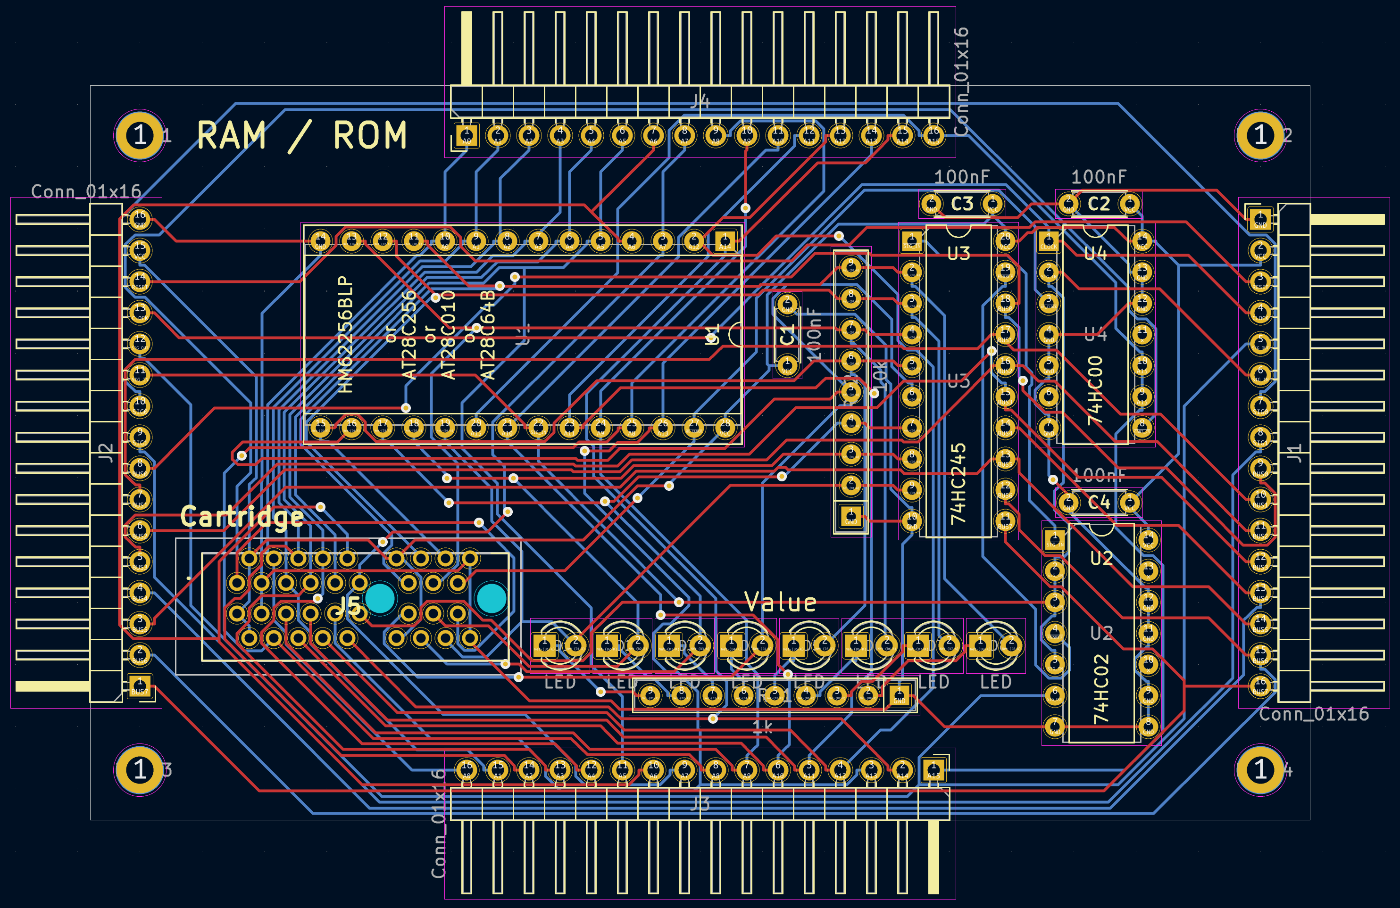
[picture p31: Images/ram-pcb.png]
RAM PCB layout

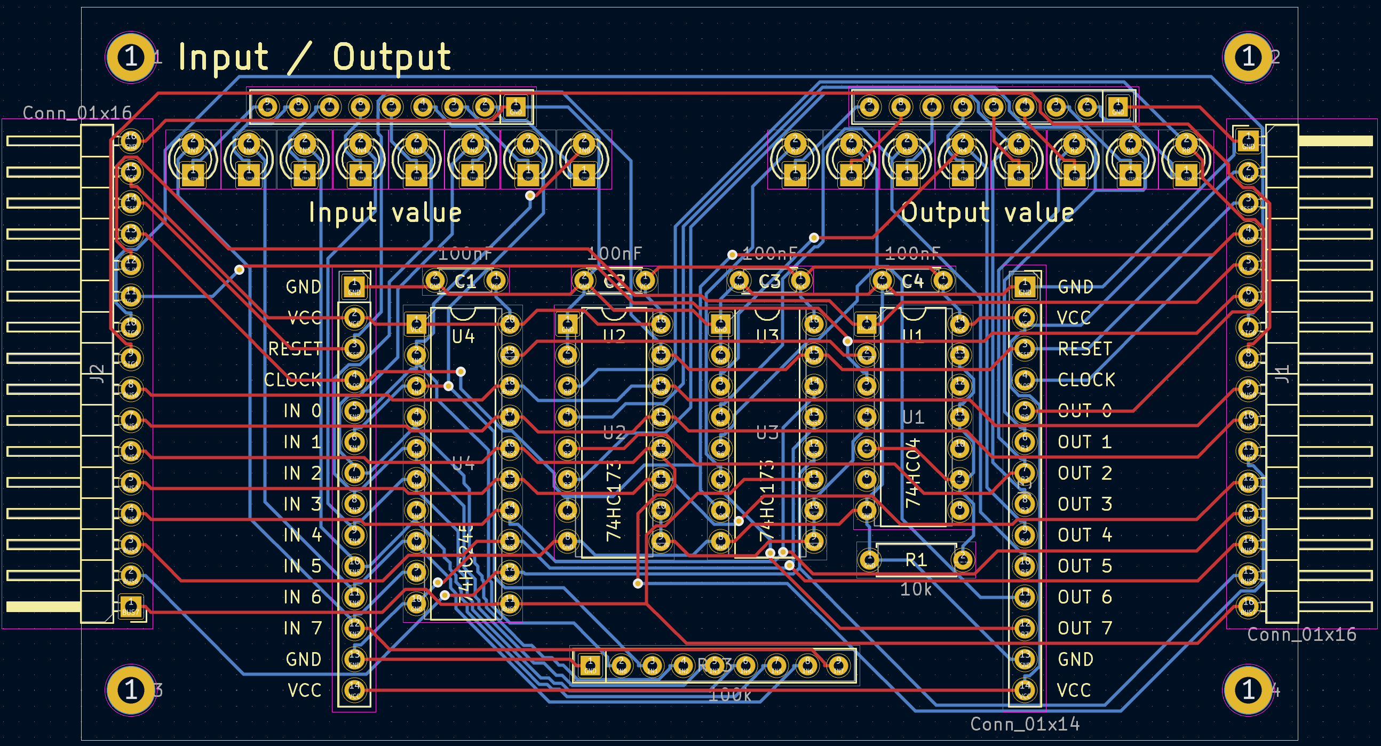
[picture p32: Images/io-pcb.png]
Input / Output PCB layout

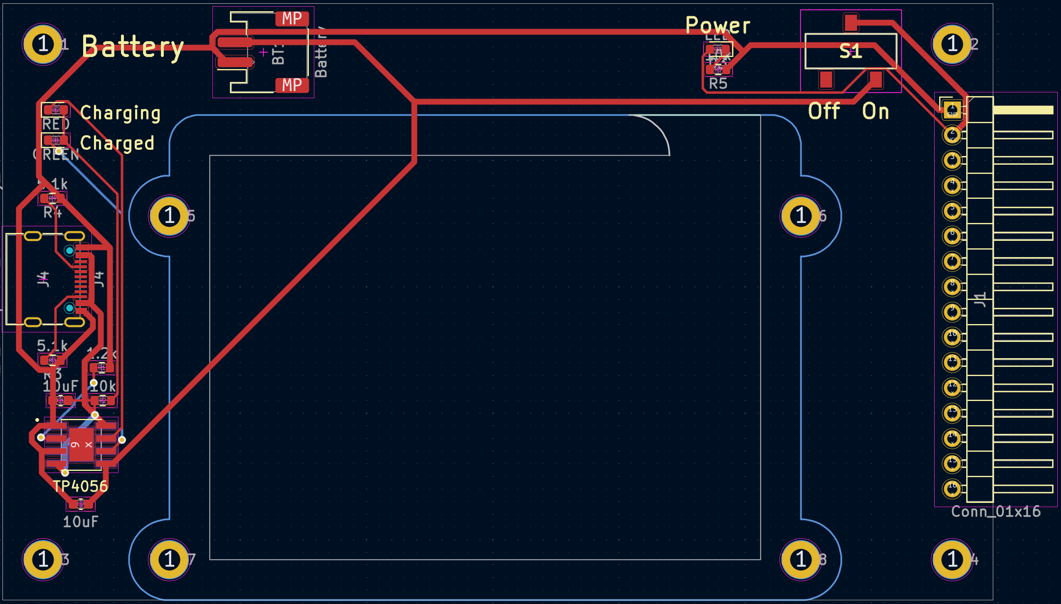
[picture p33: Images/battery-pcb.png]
Battery PCB layout

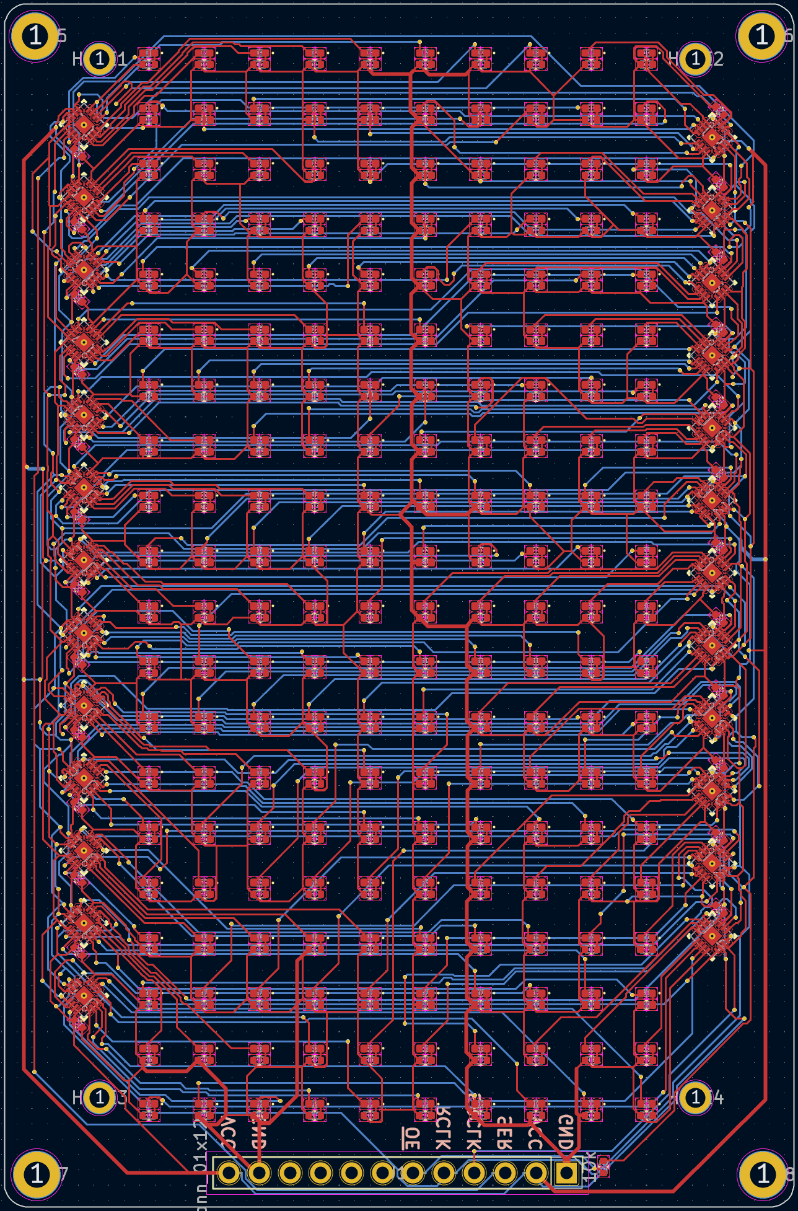
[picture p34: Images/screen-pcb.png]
Screen PCB layout

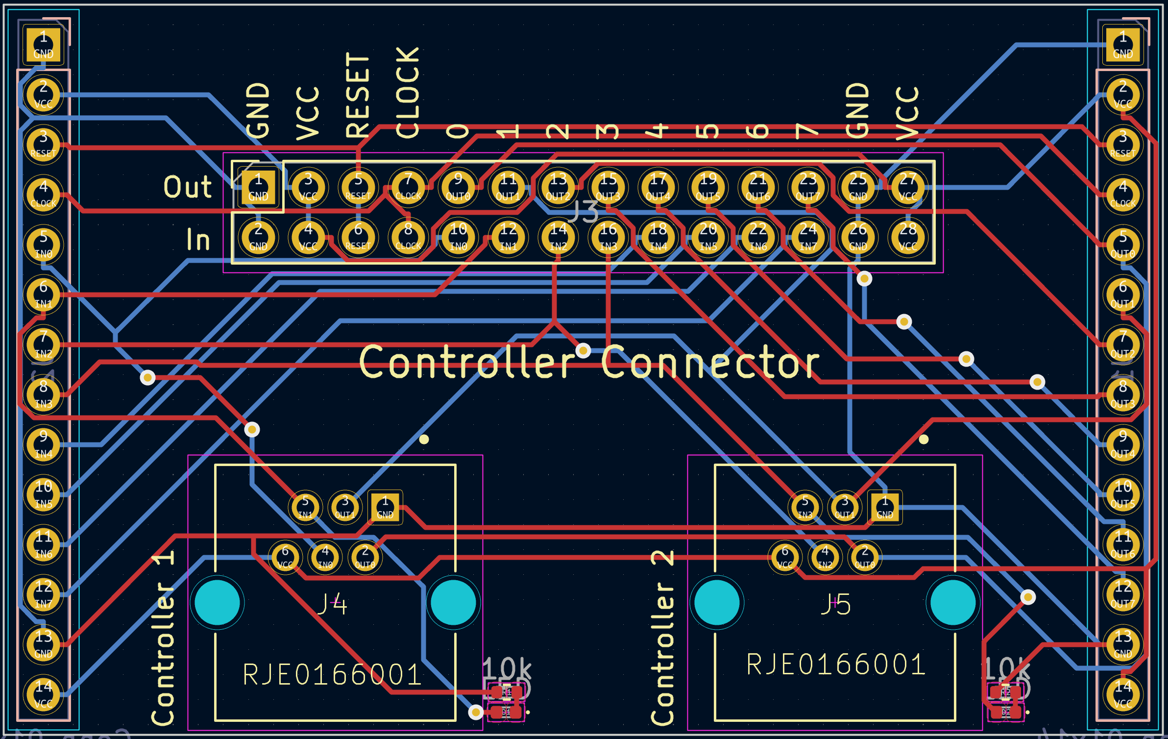
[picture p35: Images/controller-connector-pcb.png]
Controller Connector PCB layout

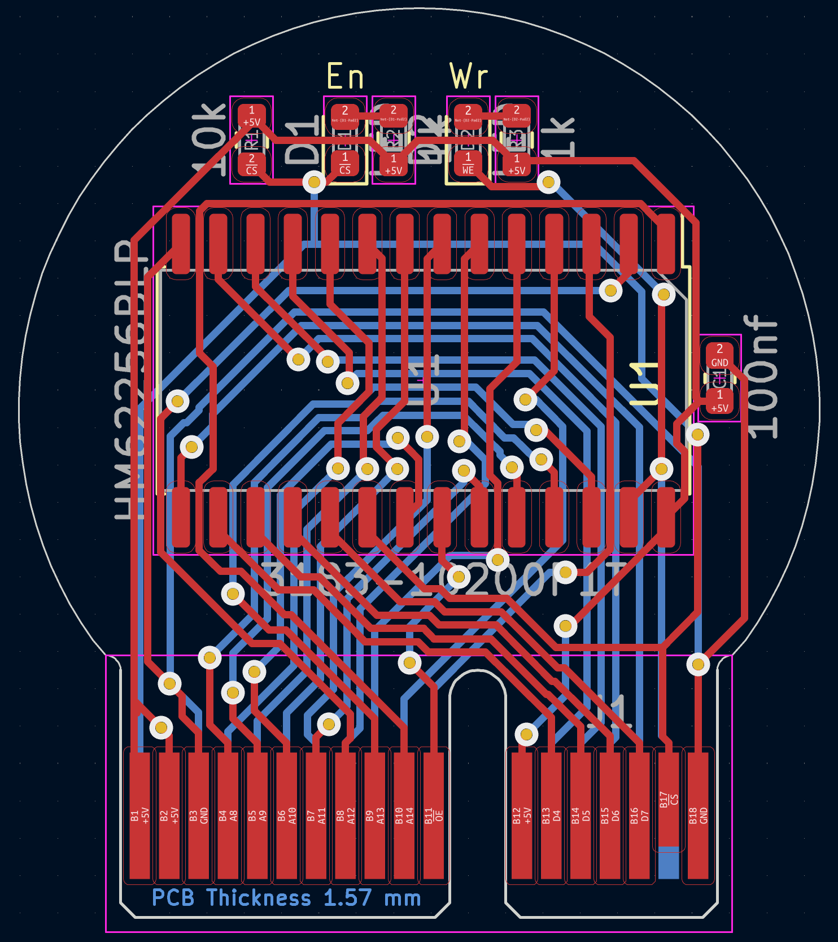
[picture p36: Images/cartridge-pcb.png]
Cartridge PCB layout

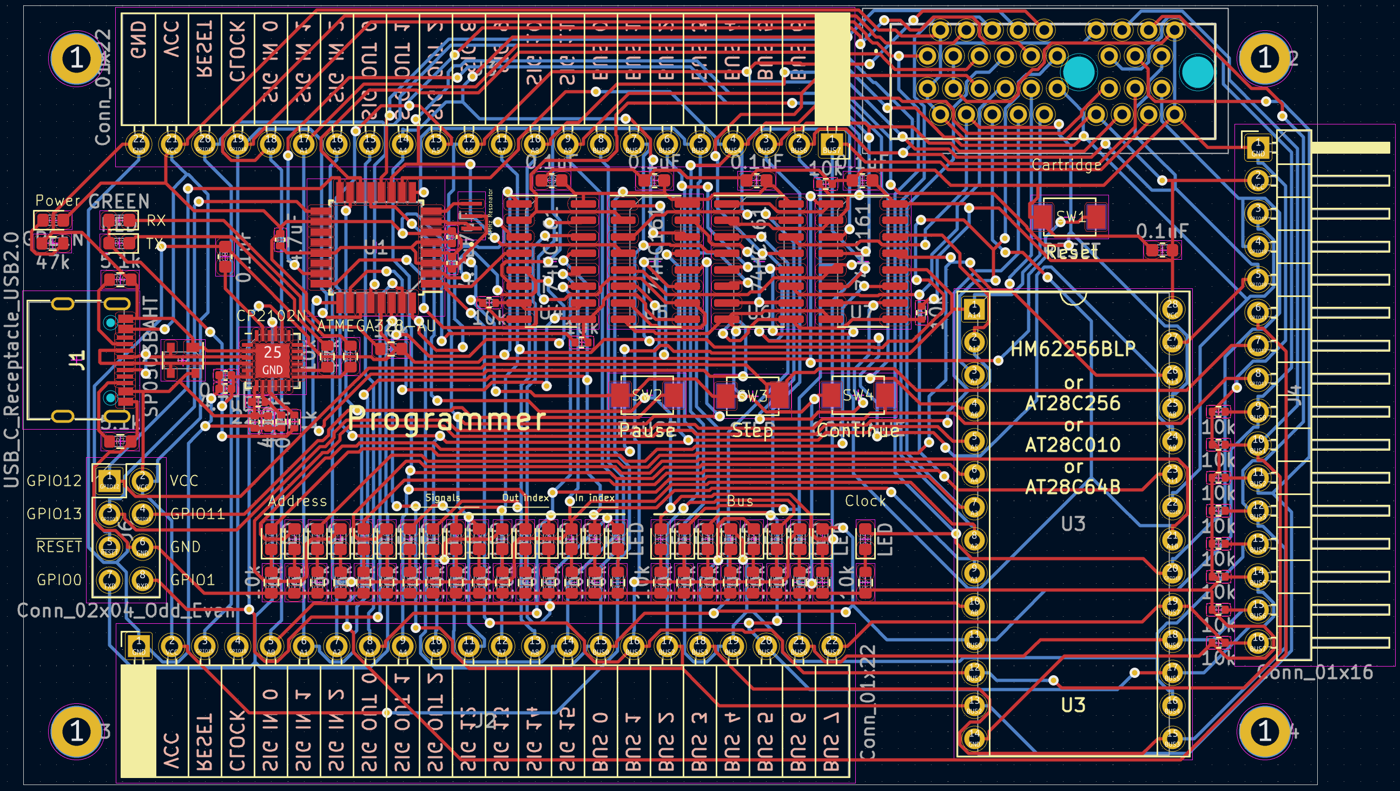
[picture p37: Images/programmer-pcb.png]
Programmer PCB layout


### 3D Renderings
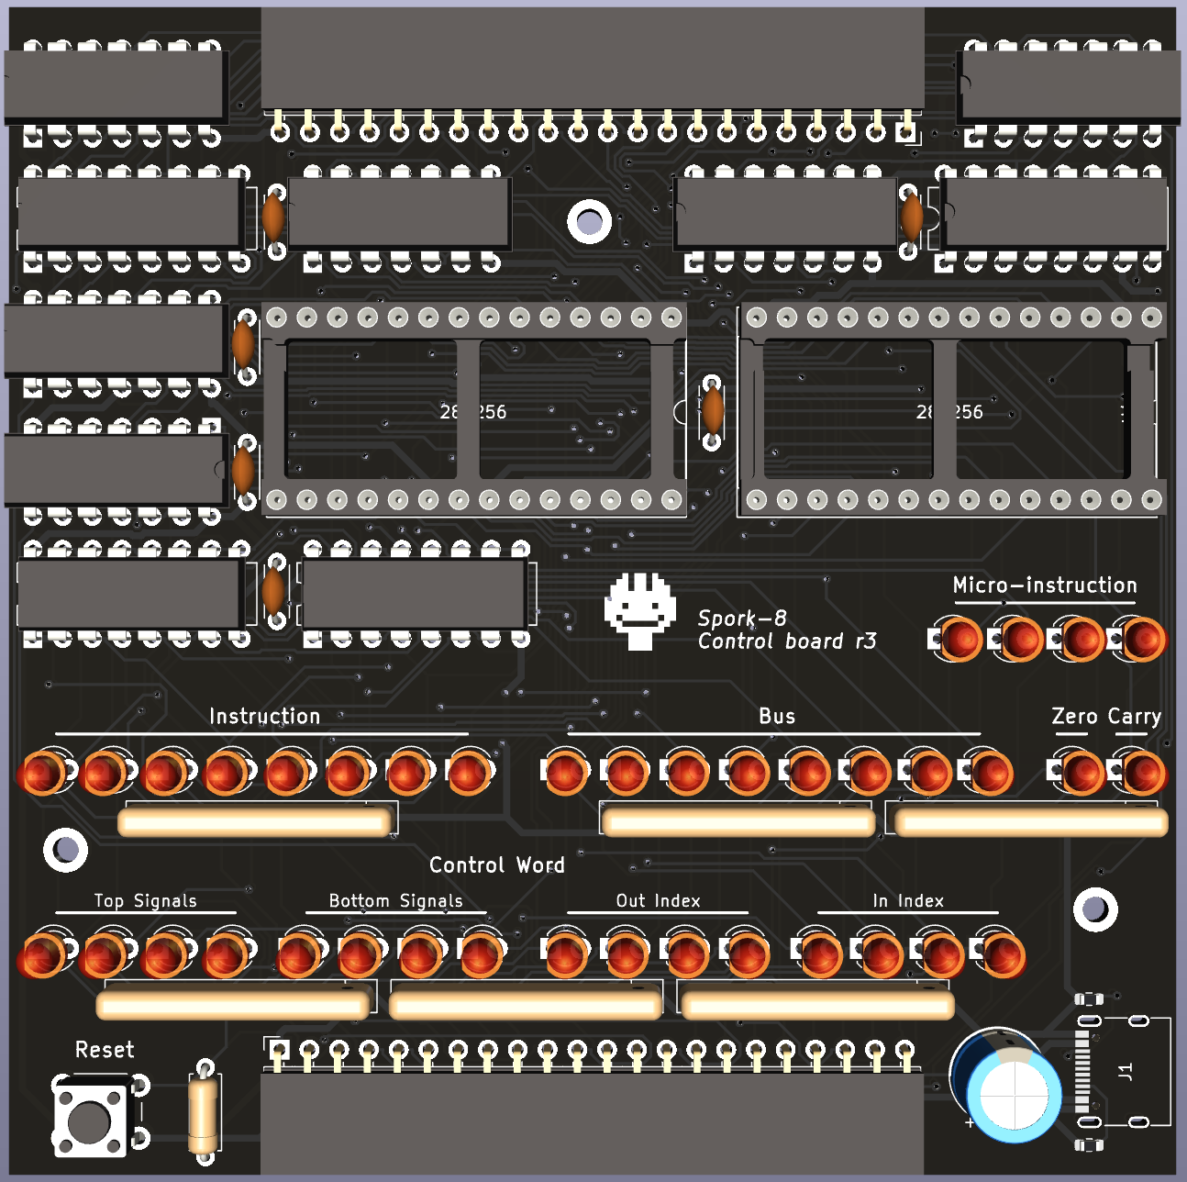
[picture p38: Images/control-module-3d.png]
Control Module 3D render

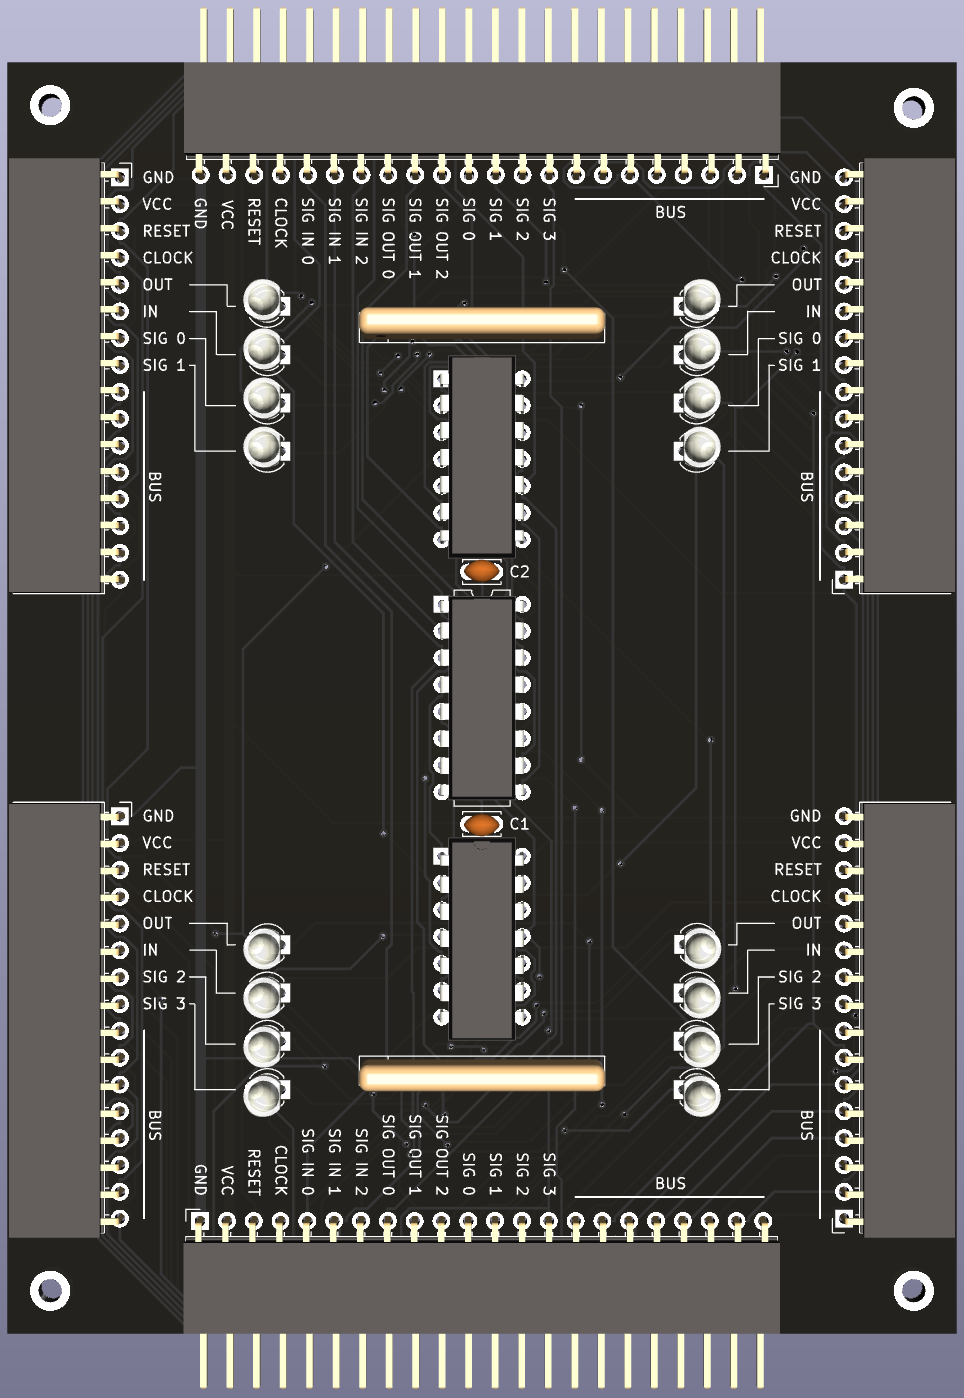
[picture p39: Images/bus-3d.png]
Bus 3D render

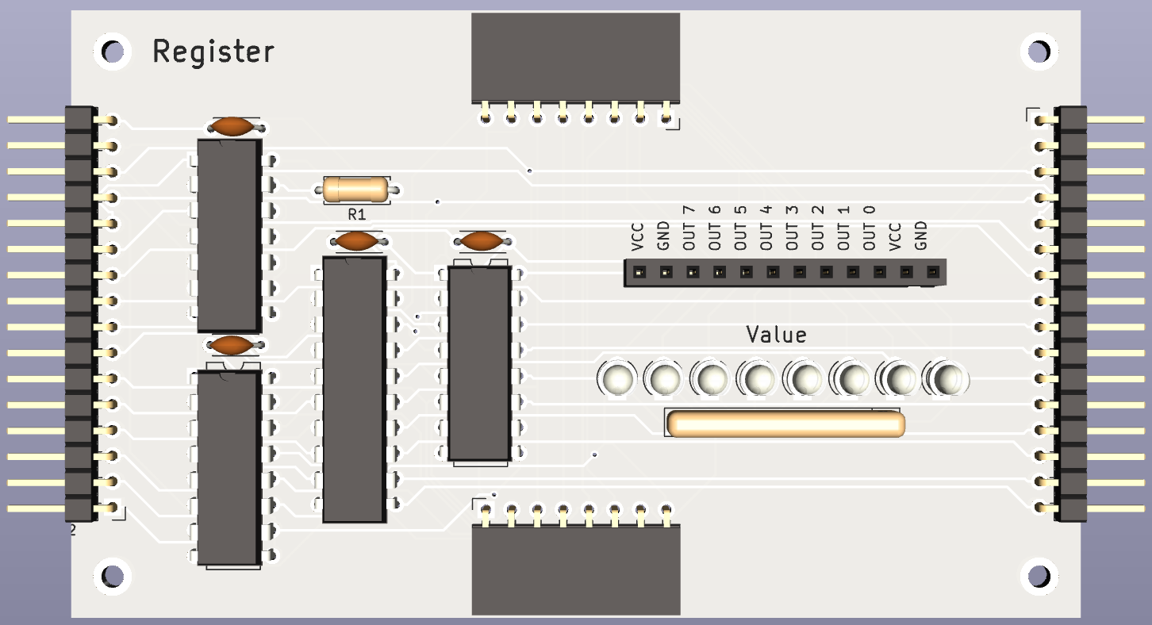
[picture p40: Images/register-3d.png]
Register 3D render

ALU 3D render
Shift / Rotate 3D render
Clock 3D render
Counter 3D render
RAM 3D render
Input / Output 3D render
Battery 3D render
Screen 3D render
Controller Connector 3D render
Cartridge 3D render
Programmer 3D render

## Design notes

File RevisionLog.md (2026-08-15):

# Revision Log

This is to document all the issues (and fixes to them) of each revision of boards.

## Revision 3.1
* **Control Module & Bus boards**:
  * Convert to 4 layer boards, with the middle 2 layers used as ground planes.
  * Add an extra ground pin on each side of the board connectors.
* **General fixes**:
  * The purpose of this update was to generally improve reliability. Some instructions (like Call and Return) didn't work reliably, and it was unclear exactly what was going on. This update may not have made it 100% reliable, but it helped a lot. The 2 player snake game that wouldn't run before, now does run reliably.
  * Fixed the labeling of top / bottom signals.

## Revision 3
* **Clock**:
  * Switched to a vertical potentiometer, to be more ergnomic. It's probably higher Ohms as well.
* **ALU** fully works.
* **Control Module**:
  * Switched instruction register to use 2x 173 4-bit registers, rather than 1x 273 8-bit register, which allows removing a gate chip. The 4-bit registers support separate clock-pulse and enable signals, which solves the random loading issue in revision 2.
  * Switched to using signal 14 for `reset micro-instruction counter`, since it was unused, and this enables getting rid of the only 30 chip (8-input AND).
  * The net removal of 1 chip also fixes the issue of the crowding of U11/U12, and U6/U7.
  * Switched to USB-C from USB-B.
  * Remove pull-down resistors for control lines, since the outputs from the EEPROMs never float.
  * Removed the inaccurate line over the Zero flag on the silk screen.
  * Signal 15 (`instruction register in`) is inverted accidentally. Easily worked around in the microcode. Seemingly impossible to fix in hardware without adding another chip.
* **Counter** fully works.
* **RAM / ROM**:
  * Added a cartridge slot, using the most significant bit of the address to select between the cartridge and on-board EEPROM.
* **General fixes, improvements, and issues**:
  * Binary display on all boards is corrected.
  * Switched to HC chips, which use MUCH less power (~3A vs. ~0.1A).
  * Added screw holes to all boards to be able to mount it.
  * While it generally works reliably at 2MHz, it only does so on battery at ~3.7V, and the Call / Return instructions don't work (but they work at slower speeds). It's still unclear what isn't working or why.
  * When assembled with 10kOhm pull down resistors on the bus, the voltage doesn't dissipate fast enough to read a constant 0 without outputting anything it at faster speeds. This is presumably because the bus wires are very long, and therefore have a high capacitance. The above issue could be related to this.
  * There's now an emulator, written in Zig, which supports controller input and screen display.
* **New boards**:
  * IO module: replaces Input, to have output and input next to each other. The trade-off is that for inputting, it doesn't hold the input value in a register, it just directly connects it to the bus, and for outputting, the outputted value (which is stored in a register) is write-only (it can't be copied back out). But it makes it much more convenient to interface with a shift register.
  * Battery module: holds a battery, can charge it, and has a switch to output power to the CPU. Plugs into the non-addressable module slot on the bottom bus boards.
  * Controller Connector peripheral board: plugs into IO module, and has two RJ12 plugs on it, to connect to parallel-to-serial shift register-based controllers.
  * Screen peripheral board: 10x20 595-shift register-based monochrome display. Plugs into output module.
  * Programming board: Arduino-based board used to program and test the CPU in 3 ways:
    1. Separate from the CPU, read / write to EEPROMs (big ones, or cartridges).
    2. Plug into bus boards, to test all the modules plugged in (doesn't work, because the bus is needed to set the signals, but that could cause bus contention).
    3. Replace the program memory and clock, to have a very fast development cycle to write program code (not necessary now that there's an emulator), or to test the CPU.

## Revision 2

* **RAM / ROM** fully works.
* **Control Module**:
  * Loads instructions from the bus randomly. It turns out that EEPROMs do not have floating outputs while new data is loaded after an address change, they have asserted random values, so pull-down resistors don't help. Since the instruction register inputs on `inverted clock & control word 15`, if `control word 15` fluctuates while the clock is low, it will trigger an erroneous read.
  * Has a (silkscreen) line above Zero flag, but it's not inverted.
  * Reset seems to be pulled high, despite the 1k resistor pulling it low; particularly register modules will reset when they shouldn't, and it gets worse the more there are (that is, a second 1k resistor fixes it with some modules, but if more are added it's not enough).
  * Two pairs of chips don't fully fit next to each other: U11/U12, and U6/U7. They're close enough that they could still be soldered though, and the Xinluda chips fit much better than the (I think) Texas Instruments chips.
* **General issues**:
  * All binary values are represented in reverse, since pins 0-8 are displayed left to right, which puts the least significant bit on the left. This is done consistently, so it all works, but is confusing, especially for programming.
  * Power: the whole thing uses around 3A or more of current, which is beyond the USB spec, and too much for even fast chargers. It works to connect a second power supply (2.4A + 1A), but obviously isn't ideal.

## Revision 1

* **Input** fully works.
* **Register** fully works.
* **Clock** mostly works, but:
    * Initial mode is either random, or continuously cycles.
    * Manual pulse sometimes double-pulses.
    * "Slow" mode doesn't go very slow (100k Ohm isn't a big enough range), and the variable resistor UX isn't ideal.
* **ALU** works, but has connections on all headers backwards, meaning it must be installed rotated 180º.
* **Control Module** was not assembled, because I realized issues before assembly:
    * Instruction register, and flags register would change while clock was high, causing control lines to float. Fixed by changing them to use inverted clock.
    * Micro-instruction counter would reset on clock going high rather than low. Fixed by using Parallel Load on inverted clock instead. Also buffered the inverted clock, to try to synchronize it with the instruction and flag register loading.
    * Control lines could be floating while EEPROMs load after address change. Fixed with 1k pull-down resistors. (Or so I thought; turns out they don't float, they assert random values).
* **Counter**:
  * Didn't count correctly past 8 bits, but was fixable by cutting 4 traces, and adding 4 connections. It turns out CEP and CET are different, and for my purposes, I need them both to be connected to the previous counter's TC.
  * Uses the clock as an input for 4 chips; this hasn't caused an issue, but could hit the fan-out limit. Easy to fix by buffering the clock through an unused gate.
* **RAM / ROM** was not assembled, because I realized issues before assembly:
    * It would write even while the clock was low. This would mean if control lines randomly selected it for writing while floating, it would write when not desired (hopefully also fixed by Control Module changes). It also means it may start a write cycle before the correct data was on the bus. Fixed by `AND`ing the clock with the write signal, and turning off output and switching bus transceiver to input mode when write signal is high (even while clock is low). The latter should ensure the EEPROM or RAM chip has valid data inputs before the write cycle is started.

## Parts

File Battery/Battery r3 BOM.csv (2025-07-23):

Designator | Comment | Footprint | LCSC Part Number
BT1 | Battery | JST_PH_S2B-PH-SM4-TB_1x02-1MP_P2.00mm_Horizontal | C295747
C1, C2 | 10uF | 0603 | C19702
D1 | GREEN | 0603 | C965804
D2 | RED | 0603 | C2286
D3 | LED | 0603 | C72041
J1 | Conn_01x16 | PinHeader_1x16_P2.54mm_Horizontal
J4 | USB_C_Receptacle_PowerOnly_6P | USB_C_Receptacle_G-Switch_GT-USB-7010ASV | C2988369
R1 | 1.2k | 0603 | C22765
R2 | 10k | 0603 | C25804
R3, R4 | 5.1k | 0603 | C23186
R5 | 10k | 0603 | C25804
S1 | SS-3235D-03-L2 | SS3235D03L2 | C381097
U1 | TP4056 | SOP127P600X175-9N | C16581

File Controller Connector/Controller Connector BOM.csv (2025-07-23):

Designator | Comment | Footprint | LCSC Part Number
D1, D2 | LED | LED_0402_1005Metric | C965793
J1, J2 | Conn_01x14 | Connector_Generic:Conn_01x14
J3 | Conn_02x14_Top_Bottom | Connector_Generic:Conn_02x14_Odd_Even
J4, J5 | RJE0166001 | RJE0166001-RJE0166001 | C77859
R1, R2 | 10k | R_0402_1005Metric | C25744

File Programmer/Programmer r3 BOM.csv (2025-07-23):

Designator | Comment | Footprint | LCSC Part Number
16MHz1 | Resonator | OSC_CSTCE16M0V53-R0 | C32180
C1, C2, C3, C4, C6 | 4.7uF | 402 | C23733
C5, C7 | 0.1uF | 402 | C307331
C8, C9, C10, C11, C12, C13 | 0.1uF | 603 | C14663
D1, D4 | GREEN | 603 | C965804
D2 | SP0503BAHT | SOT-143 | C3040626
D3 | RED | 603 | C2286
D5, D6, D7, D8, D9, D10, D11, D12, D13, D14, D15, D16, D17, D18, D19, D20, D21, D22, D23, D24, D25, D26, D27, D28, D29 | LED | 603 | C2290
J1 | USB_C_Receptacle_USB2.0 | USB_C_Receptacle_G-Switch_GT-USB-7010ASV | C2988369
J2, J3 | Conn_01x22 | PinSocket_1x22_P2.54mm_Horizontal
J4 | Conn_01x16 | PinHeader_1x16_P2.54mm_Horizontal
J5 | 3183-10200P1T | 318310200P1T
J6 | Conn_02x04_Odd_Even | PinHeader_2x04_P2.54mm_Vertical
R1, R9 | 47k | 603 | C25819
R2 | 10k | 603 | C25804
R3, R4 | 5.1k | 603 | C23186
R5 | 22.1k | 402 | C25768
R6 | 47.5k | 402 | C25792
R7 | 1k | 402 | C11702
R8, R10, R11, R12, R13, R14, R15, R16, R17, R18, R19, R20, R21, R22, R23, R24, R25, R26, R27, R28, R29, R30, R31, R32, R33, R34 | 10k | 603 | C25804
R35, R36, R37, R38, R39, R40, R41, R42, R43, R44, R45, R46 | 10k | 402 | C25744
SW1 | RESET | SW_TS-1088-AR02016 | C720477
SW2 | PAUSE | SW_TS-1088-AR02016 | C720477
SW3 | STEP | SW_TS-1088-AR02016 | C720477
SW4 | CONTINUE | SW_TS-1088-AR02016 | C720477
U1 | ATMEGA328-AU | TQFP-32_7x7mm_P0.8mm | C14877
U2 | CP2102N-Axx-xQFN24 | QFN-24-1EP_4x4mm_P0.5mm_EP2.6x2.6mm | C969151
U3 | HM62256BLP | DIP-28_W15.24mm_Socket
U4, U5, U6, U7 | 74HC161 | SOIC-16_3.9x9.9mm_P1.27mm | C5310798

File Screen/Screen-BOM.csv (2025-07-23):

Comment | Designator | Footprint | LCSC Part Number
0.1uF | C1, C2, C3, C4, C5, C6, C7, C8, C9, C10, C11, C12, C13, C14, C15, C16, C17, C18, C19, C20, C21, C22, C23, C24, C25 | C_0402_1005Metric | C307331
LED | D1, D2, D3, D4, D5, D6, D7, D8, D9, D10, D11, D12, D13, D14, D15, D16, D17, D18, D19, D20, D21, D22, D23, D24, D25, D26, D27, D28, D29, D30, D31, D32, D33, D34, D35, D36, D37, D38, D39, D40, D41, D42, D43, D44, D45, D46, D47, D48, D49, D50, D51, D52, D53, D54, D55, D56, D57, D58, D59, D60, D61, D62, D63, D64, D65, D66, D67, D68, D69, D70, D71, D72, D73, D74, D75, D76, D77, D78, D79, D80, D81, D82, D83, D84, D85, D86, D87, D88, D89, D90, D91, D92, D93, D94, D95, D96, D97, D98, D99, D100, D101, D102, D103, D104, D105, D106, D107, D108, D109, D110, D111, D112, D113, D114, D115, D116, D117, D118, D119, D120, D121, D122, D123, D124, D125, D126, D127, D128, D129, D130, D131, D132, D133, D134, D135, D136, D137, D138, D139, D140, D141, D142, D143, D144, D145, D146, D147, D148, D149, D150, D151, D152, D153, D154, D155, D156, D157, D158, D159, D160, D161, D162, D163, D164, D165, D166, D167, D168, D169, D170, D171, D172, D173, D174, D175, D176, D177, D178, D179, D180, D181, D182, D183, D184, D185, D186, D187, D188, D189, D190, D191, D192, D193, D194, D195, D196, D197, D198, D199, D200 | LED_0402_1005Metric | C965793
Conn_01x12 | J1 | PinHeader_1x12_P2.54mm_Vertical
10k | R1, R2, R3, R4, R5, R6, R7, R8, R9, R10, R11, R12, R13, R14, R15, R16, R17, R18, R19, R20, R21, R22, R23, R24, R25, R26, R27, R28, R29, R30, R31, R32, R33, R34, R35, R36, R37, R38, R39, R40, R41, R42, R43, R44, R45, R46, R47, R48, R49, R50, R51, R52, R53, R54, R55, R56, R57, R58, R59, R60, R61, R62, R63, R64, R65, R66, R67, R68, R69, R70, R71, R72, R73, R74, R75, R76, R77, R78, R79, R80, R81, R82, R83, R84, R85, R86, R87, R88, R89, R90, R91, R92, R93, R94, R95, R96, R97, R98, R99, R100, R101, R102, R103, R104, R105, R106, R107, R108, R109, R110, R111, R112, R113, R114, R115, R116, R117, R118, R119, R120, R121, R122, R123, R124, R125, R126, R127, R128, R129, R130, R131, R132, R133, R134, R135, R136, R137, R138, R139, R140, R141, R142, R143, R144, R145, R146, R147, R148, R149, R150, R151, R152, R153, R154, R155, R156, R157, R158, R159, R160, R161, R162, R163, R164, R165, R166, R167, R168, R169, R170, R171, R172, R173, R174, R175, R176, R177, R178, R179, R180, R181, R182, R183, R184, R185, R186, R187, R188, R189, R190, R191, R192, R193, R194, R195, R196, R197, R198, R199, R200, R201 | R_0402_1005Metric | C25744
74HC595 | U1, U2, U3, U4, U5, U6, U7, U8, U9, U10, U11, U12, U13, U14, U15, U16, U17, U18, U19, U20, U21, U22, U23, U24, U25 | RWN0016A | C2682068

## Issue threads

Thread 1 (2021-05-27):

Can't find the potentiometer for Clock Module

brandonbronisz, 2021-05-27:
Looking at the BOM, Potentiometer Alps RK09Y11 is hard to find. I've looked at various providers and can't find it. Do you have a link to where I could find that or an alternative that would work?

benanderman, 2025-01-03:
Sorry, I never saw this! I got mine here: https://www.lcsc.com/product-detail/Variable-Resistors-Potentiometers_ALPSALPINE-RK09Y11L0001_C470717.html

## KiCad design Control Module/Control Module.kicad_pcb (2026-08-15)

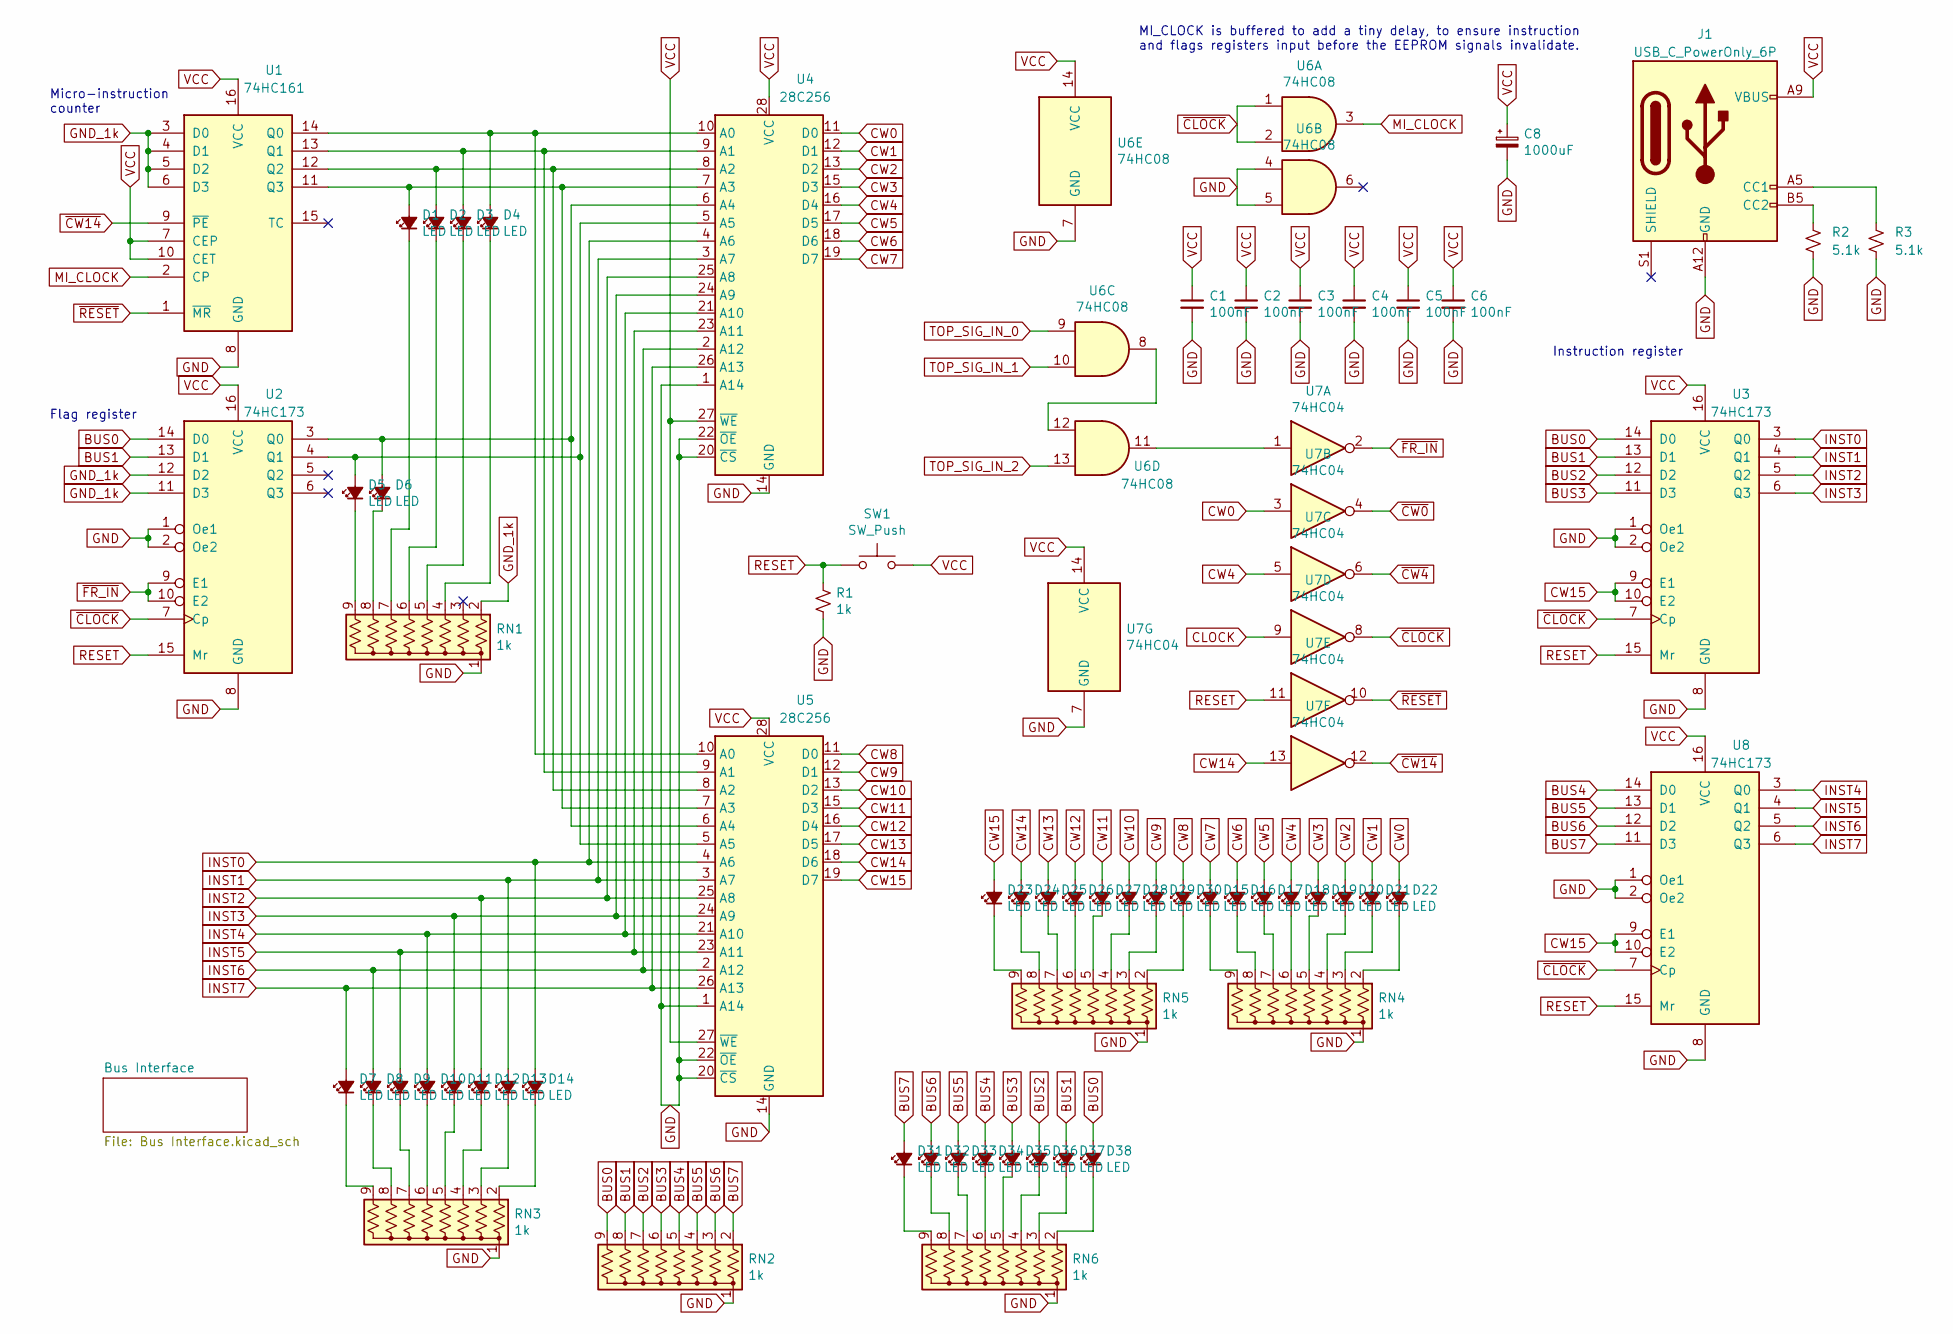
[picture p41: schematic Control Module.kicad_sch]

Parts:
C1, C2, C3, C4, C5, C6: 100nF; C_Disc_D4.3mm_W1.9mm_P5.00mm
C8: 1000uF; CP_Radial_D8.0mm_P3.50mm
D1, D2, D3, D4, D5, D6, D7, D8, D9, D10, D11, D12, D13, D14, D15, D16, D17, D18, D19, D20, D21, D22, D23, D24, D25, D26, D27, D28, D29, D30, D31, D32, D33, D34, D35, D36, D37, D38: LED; LED_D3.0mm
J1: USB_C_PowerOnly_6P; USB_C_Receptacle_G-Switch_GT-USB-7010ASV; LCSC C2988369
R1: 1k; R_Axial_DIN0207_L6.3mm_D2.5mm_P7.62mm_Horizontal
R2, R3: 5.1k; R_0603_1608Metric
RN1, RN2, RN3, RN4, RN5, RN6: 1k; R_Array_SIP9
SW1: SW_Push; SW_PUSH_6mm
U1: 74HC161; DIP-16_W7.62mm
U2, U3, U8: 74HC173; DIP-16_W7.62mm
U4, U5: 28C256; DIP-28_W15.24mm_Socket
U6: 74HC08; DIP-14_W7.62mm
U7: 74HC04; DIP-14_W7.62mm

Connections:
BUS0: D38.2 (A), RN2.9 (R8), U2.14 (D0), U3.14 (D0); also elsewhere on the board
BUS1: D37.2 (A), RN2.8 (R7), U2.13 (D1), U3.13 (D1); also elsewhere on the board
BUS2: D36.2 (A), RN2.7 (R6), U3.12 (D2); also elsewhere on the board
BUS3: D35.2 (A), RN2.6 (R5), U3.11 (D3); also elsewhere on the board
BUS4: D34.2 (A), RN2.5 (R4), U8.14 (D0); also elsewhere on the board
BUS5: D33.2 (A), RN2.4 (R3), U8.13 (D1); also elsewhere on the board
BUS6: D32.2 (A), RN2.3 (R2), U8.12 (D2); also elsewhere on the board
BUS7: D31.2 (A), RN2.2 (R1), U8.11 (D3); also elsewhere on the board
CLOCK: U7.9; also elsewhere on the board
CW0: D22.2 (A), U4.11 (D0), U7.3; also elsewhere on the board
CW1: D21.2 (A), U4.12 (D1); also elsewhere on the board
CW2: D20.2 (A), U4.13 (D2); also elsewhere on the board
CW3: D19.2 (A), U4.15 (D3); also elsewhere on the board
CW4: D18.2 (A), U4.16 (D4), U7.5; also elsewhere on the board
CW5: D17.2 (A), U4.17 (D5); also elsewhere on the board
CW6: D16.2 (A), U4.18 (D6); also elsewhere on the board
CW7: D15.2 (A), U4.19 (D7); also elsewhere on the board
CW8: D30.2 (A), U5.11 (D0); also elsewhere on the board
CW9: D29.2 (A), U5.12 (D1); also elsewhere on the board
CW10: D28.2 (A), U5.13 (D2); also elsewhere on the board
CW11: D27.2 (A), U5.15 (D3); also elsewhere on the board
CW12: D26.2 (A), U5.16 (D4); also elsewhere on the board
CW13: D25.2 (A), U5.17 (D5); also elsewhere on the board
CW14: D24.2 (A), U5.18 (D6), U7.13; also elsewhere on the board
CW15: D23.2 (A), U3.9 (E1), U3.10 (E2), U5.19 (D7), U8.9 (E1), U8.10 (E2); also elsewhere on the board
GND: C1.2, C2.2, C3.2, C4.2, C5.2, C6.2, C8.2, J1.A12 (GND), J1.B12 (GND), R1.2, R2.2, R3.2, RN1.1 (common), RN2.1 (common), RN3.1 (common), RN4.1 (common), RN5.1 (common), RN6.1 (common), U1.8 (GND), U2.1 (Oe1), U2.2 (Oe2), U2.8 (GND), U3.1 (Oe1), U3.2 (Oe2), U3.8 (GND), U4.1 (A14), U4.14 (GND), U4.20 (~CS), U4.22 (~OE), U5.1 (A14), U5.14 (GND), U5.20 (~CS), U5.22 (~OE), U6.4, U6.5, U6.7 (GND), U7.7 (GND), U8.1 (Oe1), U8.2 (Oe2), U8.8 (GND); also elsewhere on the board
GND_1k: RN1.2 (R1), U1.3 (D0), U1.4 (D1), U1.5 (D2), U1.6 (D3), U2.11 (D3), U2.12 (D2)
INST0: D14.2 (A), U3.3 (Q0), U4.4 (A6), U5.4 (A6)
INST1: D13.2 (A), U3.4 (Q1), U4.3 (A7), U5.3 (A7)
INST2: D12.2 (A), U3.5 (Q2), U4.25 (A8), U5.25 (A8)
INST3: D11.2 (A), U3.6 (Q3), U4.24 (A9), U5.24 (A9)
INST4: D10.2 (A), U4.21 (A10), U5.21 (A10), U8.3 (Q0)
INST5: D9.2 (A), U4.23 (A11), U5.23 (A11), U8.4 (Q1)
INST6: D8.2 (A), U4.2 (A12), U5.2 (A12), U8.5 (Q2)
INST7: D7.2 (A), U4.26 (A13), U5.26 (A13), U8.6 (Q3)
MI_CLOCK: U1.2 (CP), U6.3
unnamed: D1.2 (A), U1.11 (Q3), U4.7 (A3), U5.7 (A3)
unnamed: D1.1 (K), RN1.7 (R6)
unnamed: D2.2 (A), U1.12 (Q2), U4.8 (A2), U5.8 (A2)
unnamed: D2.1 (K), RN1.6 (R5)
unnamed: D3.2 (A), U1.13 (Q1), U4.9 (A1), U5.9 (A1)
unnamed: D3.1 (K), RN1.5 (R4)
unnamed: D4.2 (A), U1.14 (Q0), U4.10 (A0), U5.10 (A0)
unnamed: D4.1 (K), RN1.4 (R3)
unnamed: D5.2 (A), U2.4 (Q1), U4.5 (A5), U5.5 (A5)
unnamed: D5.1 (K), RN1.9 (R8)
unnamed: D6.2 (A), U2.3 (Q0), U4.6 (A4), U5.6 (A4)
unnamed: D6.1 (K), RN1.8 (R7)
unnamed: D7.1 (K), RN3.9 (R8)
unnamed: D8.1 (K), RN3.8 (R7)
unnamed: D9.1 (K), RN3.7 (R6)
unnamed: D10.1 (K), RN3.6 (R5)
unnamed: D11.1 (K), RN3.5 (R4)
unnamed: D12.1 (K), RN3.4 (R3)
unnamed: D13.1 (K), RN3.3 (R2)
unnamed: D14.1 (K), RN3.2 (R1)
unnamed: D15.1 (K), RN4.9 (R8)
unnamed: D16.1 (K), RN4.8 (R7)
unnamed: D17.1 (K), RN4.7 (R6)
unnamed: D18.1 (K), RN4.6 (R5)
unnamed: D19.1 (K), RN4.5 (R4)
unnamed: D20.1 (K), RN4.4 (R3)
unnamed: D21.1 (K), RN4.3 (R2)
unnamed: D22.1 (K), RN4.2 (R1)
unnamed: D23.1 (K), RN5.9 (R8)
unnamed: D24.1 (K), RN5.8 (R7)
unnamed: D25.1 (K), RN5.7 (R6)
unnamed: D26.1 (K), RN5.6 (R5)
unnamed: D27.1 (K), RN5.5 (R4)
unnamed: D28.1 (K), RN5.4 (R3)
unnamed: D29.1 (K), RN5.3 (R2)
unnamed: D30.1 (K), RN5.2 (R1)
unnamed: D31.1 (K), RN6.9 (R8)
unnamed: D32.1 (K), RN6.8 (R7)
unnamed: D33.1 (K), RN6.7 (R6)
unnamed: D34.1 (K), RN6.6 (R5)
unnamed: D35.1 (K), RN6.5 (R4)
unnamed: D36.1 (K), RN6.4 (R3)
unnamed: D37.1 (K), RN6.3 (R2)
unnamed: D38.1 (K), RN6.2 (R1)
unnamed: J1.A5 (CC1), R3.1
unnamed: J1.B5 (CC2), R2.1
unnamed: U6.11, U7.1
unnamed: U6.8, U6.12
RESET: R1.1, SW1.1, U2.15 (Mr), U3.15 (Mr), U7.11, U8.15 (Mr); also elsewhere on the board
TOP_SIG_IN_0: U6.9; also elsewhere on the board
TOP_SIG_IN_1: U6.10; also elsewhere on the board
TOP_SIG_IN_2: U6.13; also elsewhere on the board
VCC: C1.1, C2.1, C3.1, C4.1, C5.1, C6.1, C8.1, J1.A9 (VBUS), J1.B9 (VBUS), SW1.2, U1.7 (CEP), U1.10 (CET), U1.16 (VCC), U2.16 (VCC), U3.16 (VCC), U4.27 (~WE), U4.28 (VCC), U5.27 (~WE), U5.28 (VCC), U6.14 (VCC), U7.14 (VCC), U8.16 (VCC); also elsewhere on the board
~CLOCK: U2.7 (Cp), U3.7 (Cp), U6.1, U6.2, U7.8, U8.7 (Cp)
~CW0: U7.4; also elsewhere on the board
~CW4: U7.6; also elsewhere on the board
~CW14: U1.9 (~PE), U7.12
~FR_IN: U2.9 (E1), U2.10 (E2), U7.2
~RESET: U1.1 (~MR), U7.10

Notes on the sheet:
Micro-instruction counter
MI_CLOCK is buffered to add a tiny delay, to ensure instruction and flags registers input before the EEPROM signals invalidate.
Flag register
Instruction register

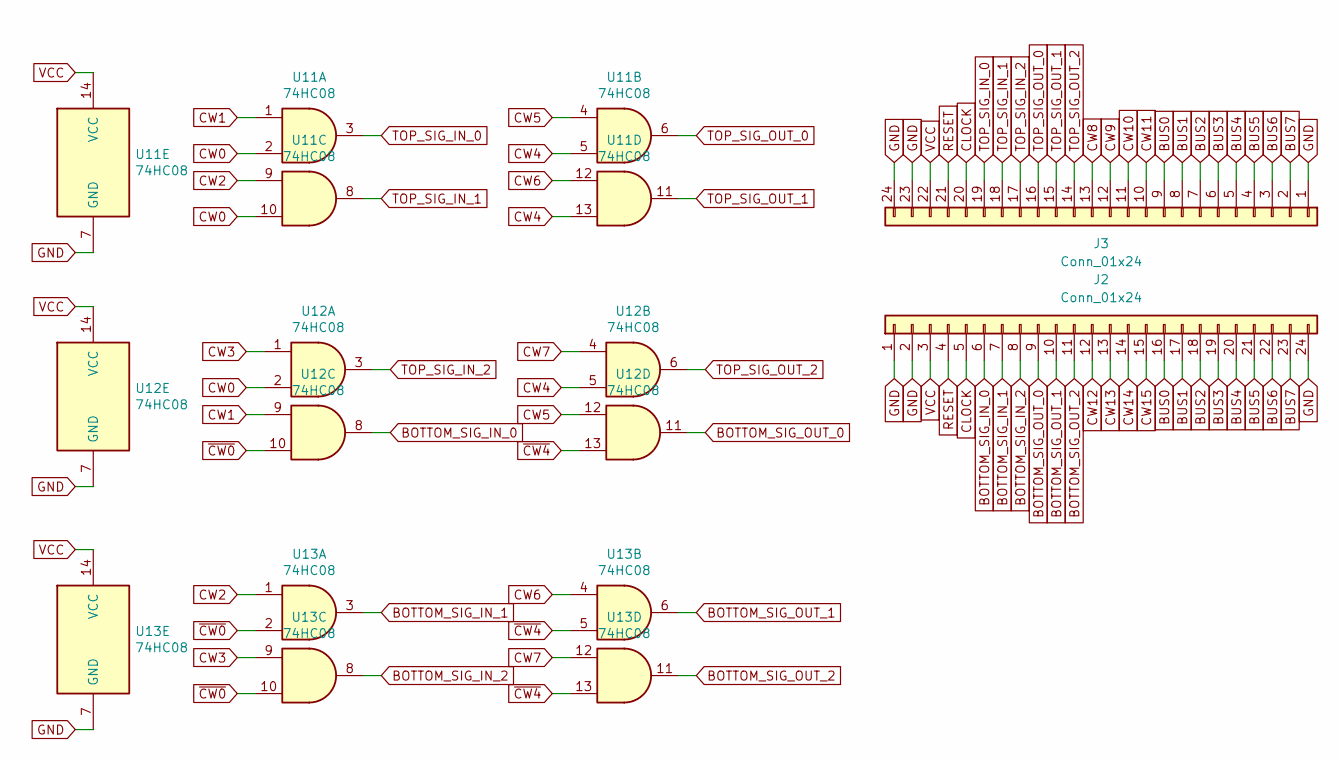
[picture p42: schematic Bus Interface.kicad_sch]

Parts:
J2, J3: Conn_01x24; PinSocket_1x24_P2.54mm_Horizontal
U11, U12, U13: 74HC08; DIP-14_W7.62mm

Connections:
BOTTOM_SIG_IN_0: J2.6, U12.8
BOTTOM_SIG_IN_1: J2.7, U13.3
BOTTOM_SIG_IN_2: J2.8, U13.8
BOTTOM_SIG_OUT_0: J2.9, U12.11
BOTTOM_SIG_OUT_1: J2.10, U13.6
BOTTOM_SIG_OUT_2: J2.11, U13.11
BUS0: J2.16, J3.9; also elsewhere on the board
BUS1: J2.17, J3.8; also elsewhere on the board
BUS2: J2.18, J3.7; also elsewhere on the board
BUS3: J2.19, J3.6; also elsewhere on the board
BUS4: J2.20, J3.5; also elsewhere on the board
BUS5: J2.21, J3.4; also elsewhere on the board
BUS6: J2.22, J3.3; also elsewhere on the board
BUS7: J2.23, J3.2; also elsewhere on the board
CLOCK: J2.5, J3.20; also elsewhere on the board
CW0: U11.2, U11.10, U12.2; also elsewhere on the board
CW1: U11.1, U12.9; also elsewhere on the board
CW2: U11.9, U13.1; also elsewhere on the board
CW3: U12.1, U13.9; also elsewhere on the board
CW4: U11.5, U11.13, U12.5; also elsewhere on the board
CW5: U11.4, U12.12; also elsewhere on the board
CW6: U11.12, U13.4; also elsewhere on the board
CW7: U12.4, U13.12; also elsewhere on the board
CW8: J3.13; also elsewhere on the board
CW9: J3.12; also elsewhere on the board
CW10: J3.11; also elsewhere on the board
CW11: J3.10; also elsewhere on the board
CW12: J2.12; also elsewhere on the board
CW13: J2.13; also elsewhere on the board
CW14: J2.14; also elsewhere on the board
CW15: J2.15; also elsewhere on the board
GND: J2.1, J2.2, J2.24, J3.1, J3.23, J3.24, U11.7 (GND), U12.7 (GND), U13.7 (GND); also elsewhere on the board
RESET: J2.4, J3.21; also elsewhere on the board
TOP_SIG_IN_0: J3.19, U11.3; also elsewhere on the board
TOP_SIG_IN_1: J3.18, U11.8; also elsewhere on the board
TOP_SIG_IN_2: J3.17, U12.3; also elsewhere on the board
TOP_SIG_OUT_0: J3.16, U11.6
TOP_SIG_OUT_1: J3.15, U11.11
TOP_SIG_OUT_2: J3.14, U12.6
VCC: J2.3, J3.22, U11.14 (VCC), U12.14 (VCC), U13.14 (VCC); also elsewhere on the board
~CW0: U12.10, U13.2, U13.10; also elsewhere on the board
~CW4: U12.13, U13.5, U13.13; also elsewhere on the board

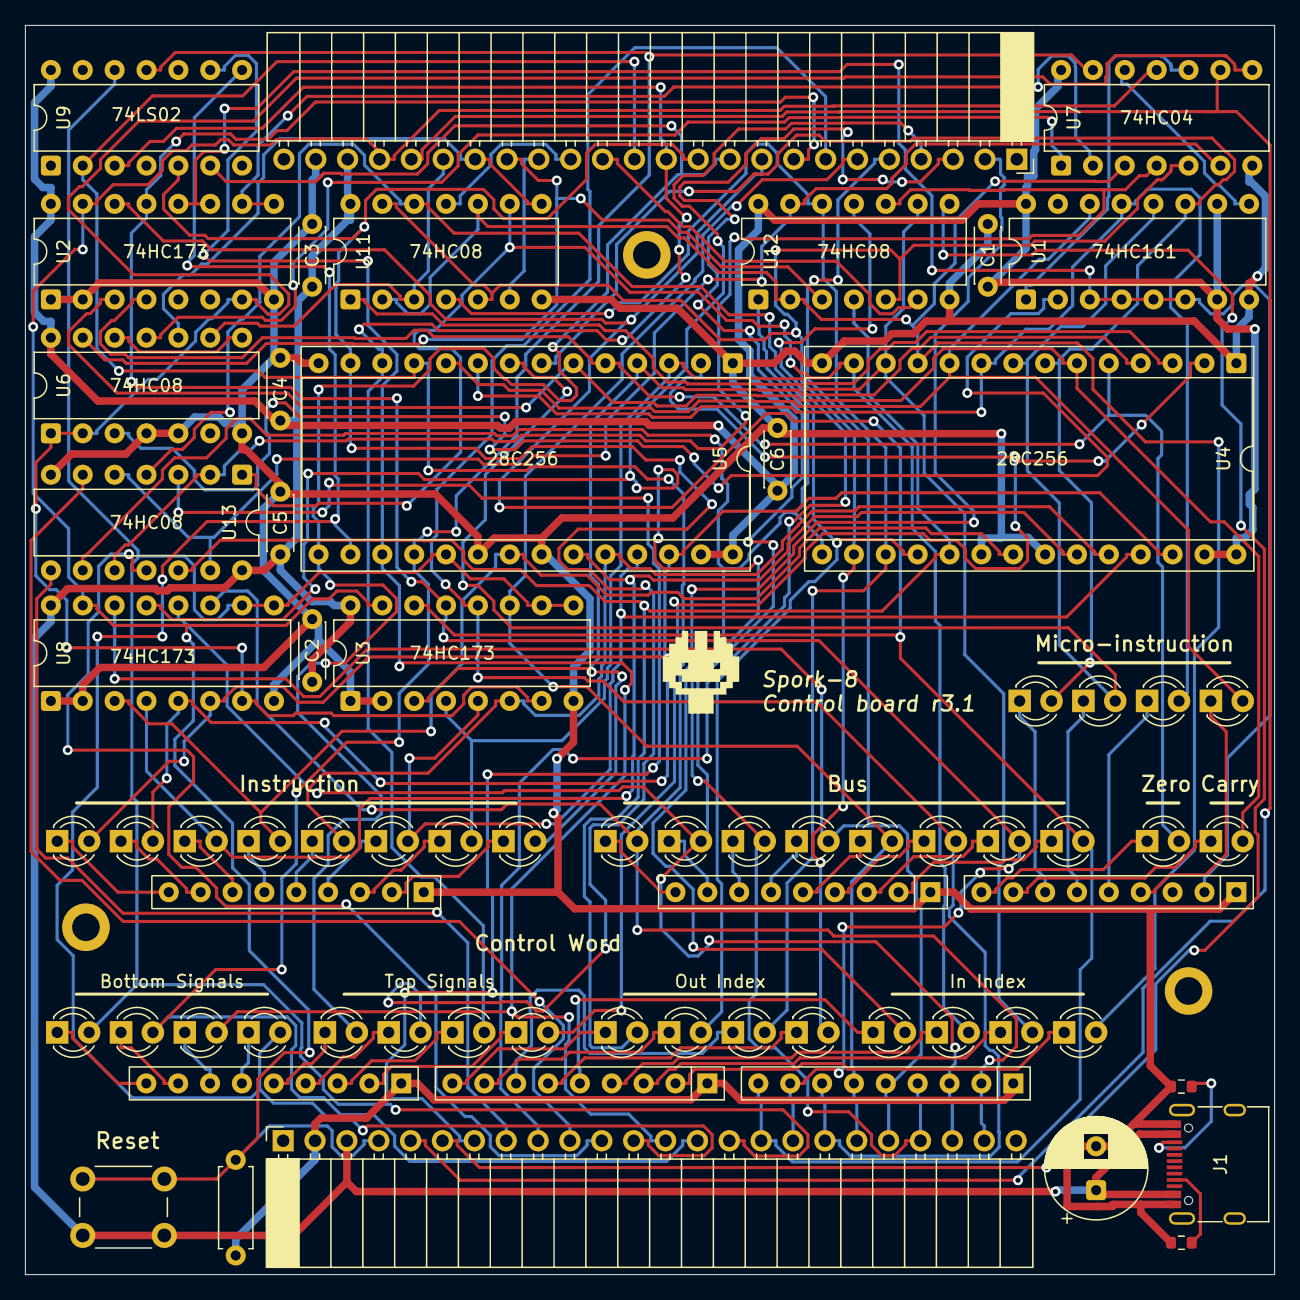
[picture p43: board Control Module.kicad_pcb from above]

Board: 4 copper layers, 99.6 x 99.6 mm, 73 parts (0 on the bottom side), 104 nets.

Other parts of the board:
HOLE1, HOLE2, HOLE3: MountingHole_2.2mm_M2_DIN965_Pad
U9: 74LS02; DIP-14_W7.62mm

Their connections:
CW8: U9.2; also elsewhere on the board
CW9: U9.3; also elsewhere on the board
CW10: U9.5; also elsewhere on the board
CW11: U9.6; also elsewhere on the board
CW12: U9.8; also elsewhere on the board
CW13: U9.9; also elsewhere on the board
CW14: U9.11; also elsewhere on the board
CW15: U9.12; also elsewhere on the board
GND: U9.7; also elsewhere on the board
VCC: U9.14; also elsewhere on the board

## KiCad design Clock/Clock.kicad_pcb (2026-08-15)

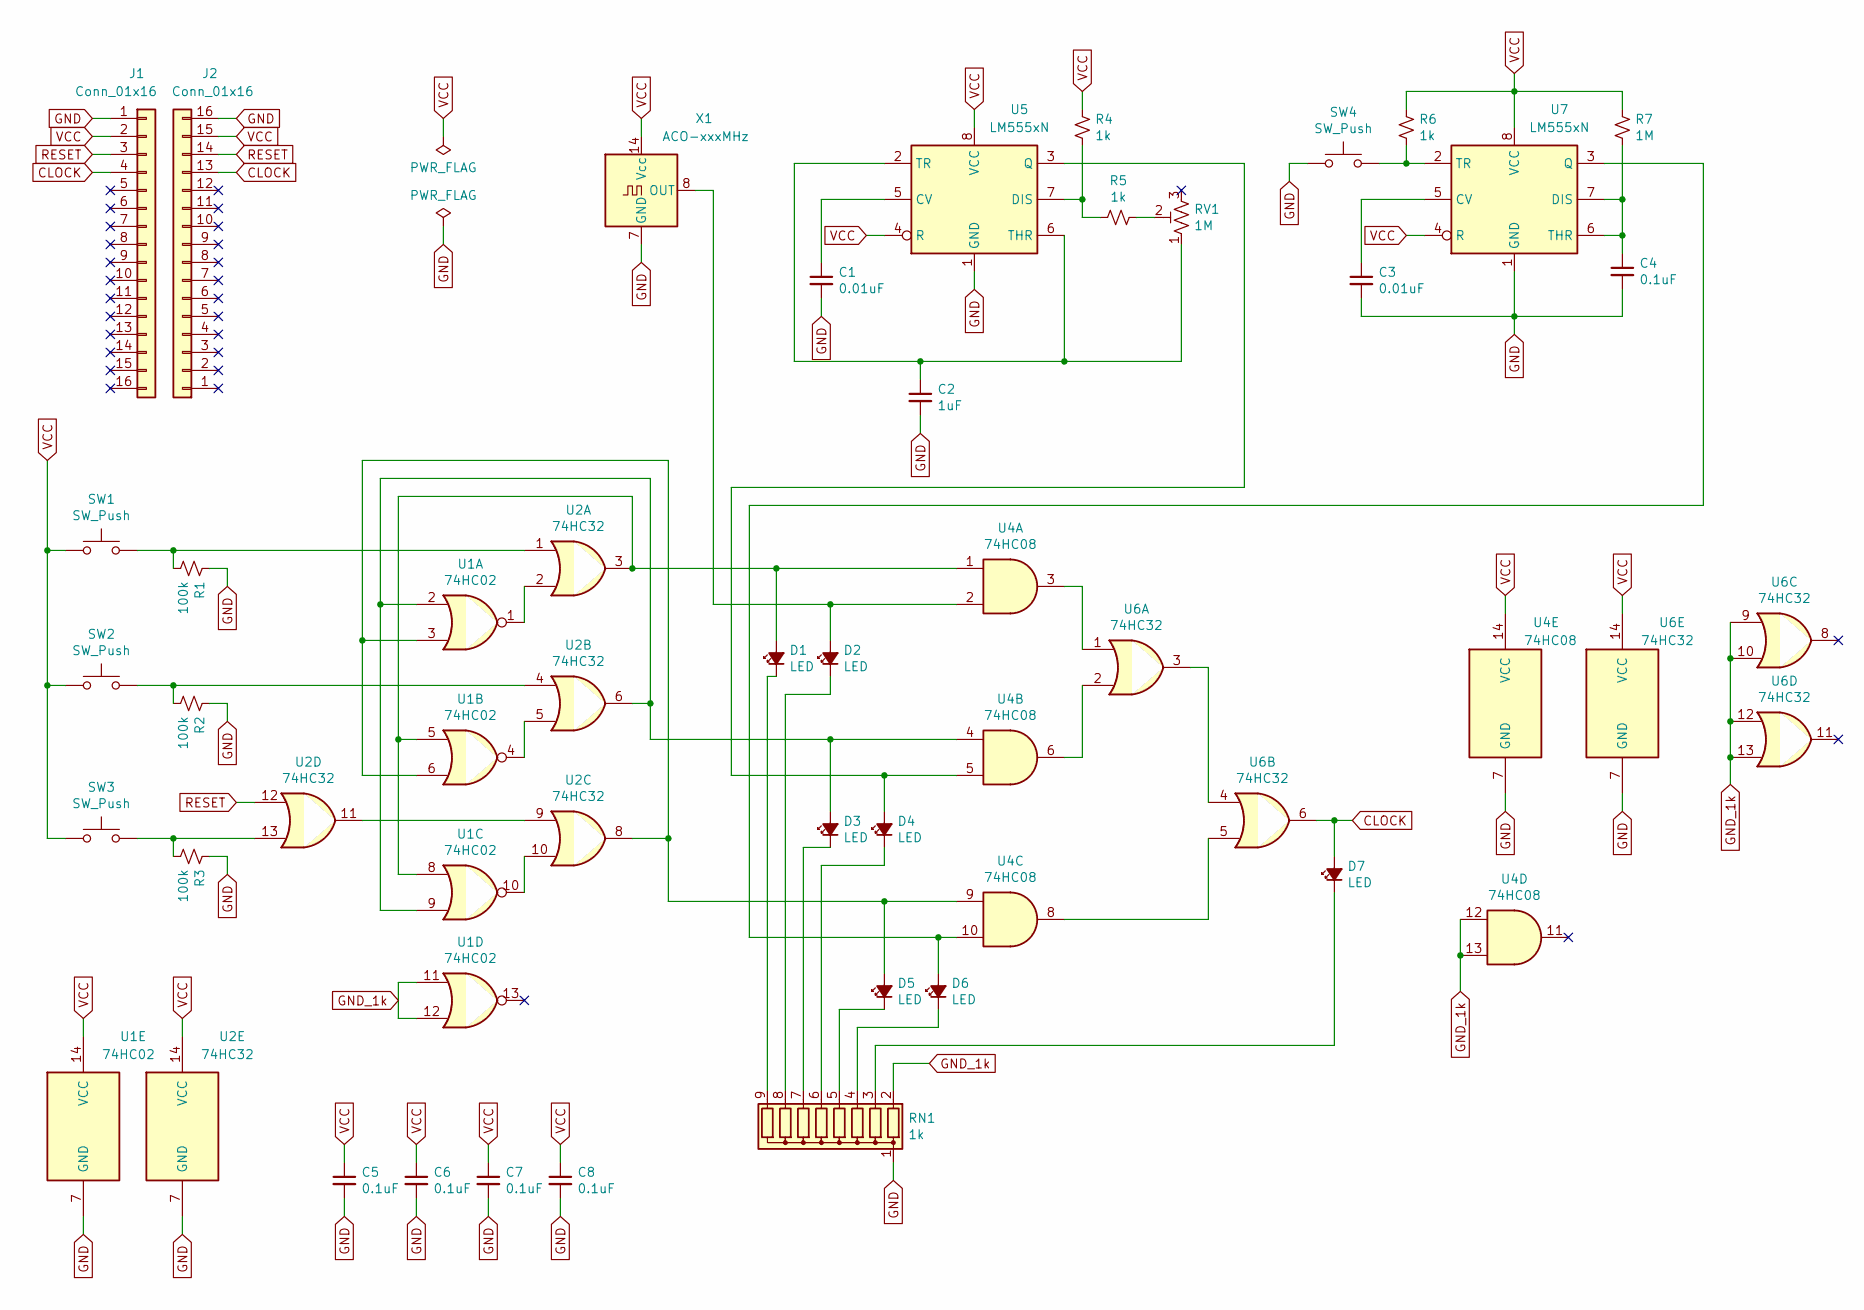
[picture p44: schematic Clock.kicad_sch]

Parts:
C1, C3: 0.01uF; C_Disc_D4.3mm_W1.9mm_P5.00mm
C2: 1uF; C_Disc_D4.3mm_W1.9mm_P5.00mm
C4, C5, C6, C7, C8: 0.1uF; C_Disc_D4.3mm_W1.9mm_P5.00mm
D1, D2, D3, D4, D5, D6, D7: LED; LED_D3.0mm_Clear
J1, J2: Conn_01x16; PinHeader_1x16_P2.54mm_Horizontal
R1, R2, R3: 100k; R_Axial_DIN0207_L6.3mm_D2.5mm_P7.62mm_Horizontal
R4, R5, R6: 1k; R_Axial_DIN0207_L6.3mm_D2.5mm_P7.62mm_Horizontal
R7: 1M; R_Axial_DIN0207_L6.3mm_D2.5mm_P7.62mm_Horizontal
RN1: 1k; R_Array_SIP9
RV1: 1M; Potentiometer_Bourns_PTV09A-1_Single_Vertical
SW1, SW2, SW3, SW4: SW_Push; SW_PUSH_6mm
U1: 74HC02; DIP-14_W7.62mm
U2, U6: 74HC32; DIP-14_W7.62mm
U4: 74HC08; DIP-14_W7.62mm
U5, U7: LM555xN; DIP-8_W7.62mm
X1: ACO-xxxMHz; Oscillator_DIP-14

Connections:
CLOCK: D7.2 (A), J1.4, J2.13, U6.6
GND: C1.2, C2.2, C3.2, C4.2, C5.2, C6.2, C7.2, C8.2, J1.1, J2.16, R1.1, R2.1, R3.1, RN1.1 (common), SW4.1, U1.7 (GND), U2.7 (GND), U4.7 (GND), U5.1 (GND), U6.7 (GND), U7.1 (GND), X1.7 (GND)
GND_1k: RN1.2 (R1), U1.11, U1.12, U4.12, U4.13, U6.9, U6.10, U6.12, U6.13
unnamed: D1.2 (A), U1.5, U1.8, U2.3, U4.1
unnamed: D1.1 (K), RN1.9 (R8)
unnamed: D2.2 (A), U4.2, X1.8 (OUT)
unnamed: D2.1 (K), RN1.8 (R7)
unnamed: D3.2 (A), U1.2, U1.9, U2.6, U4.4
unnamed: D3.1 (K), RN1.7 (R6)
unnamed: D4.2 (A), U4.5, U5.3 (Q)
unnamed: D4.1 (K), RN1.6 (R5)
unnamed: D5.2 (A), U1.3, U1.6, U2.8, U4.9
unnamed: D5.1 (K), RN1.5 (R4)
unnamed: D6.2 (A), U4.10, U7.3 (Q)
unnamed: D6.1 (K), RN1.4 (R3)
unnamed: D7.1 (K), RN1.3 (R2)
unnamed: R1.2, SW1.2, U2.1
unnamed: R2.2, SW2.2, U2.4
unnamed: R3.2, SW3.2, U2.13
unnamed: R5.1, RV1.2
unnamed: U1.1, U2.2
unnamed: U1.4, U2.5
unnamed: U1.10, U2.10
unnamed: U2.9, U2.11
unnamed: U4.3, U6.1
unnamed: U4.6, U6.2
unnamed: U4.8, U6.5
unnamed: C1.1, U5.5 (CV)
unnamed: R4.1, R5.2, U5.7 (DIS)
unnamed: C2.1, RV1.1, U5.2 (TR), U5.6 (THR)
unnamed: U6.3, U6.4
unnamed: C3.1, U7.5 (CV)
unnamed: C4.1, R7.1, U7.6 (THR), U7.7 (DIS)
unnamed: R6.1, SW4.2, U7.2 (TR)
RESET: J1.3, J2.14, U2.12
VCC: C5.1, C6.1, C7.1, C8.1, J1.2, J2.15, R4.2, R6.2, R7.2, SW1.1, SW2.1, SW3.1, U1.14 (VCC), U2.14 (VCC), U4.14 (VCC), U5.4 (R), U5.8 (VCC), U6.14 (VCC), U7.4 (R), U7.8 (VCC), X1.14 (Vcc)

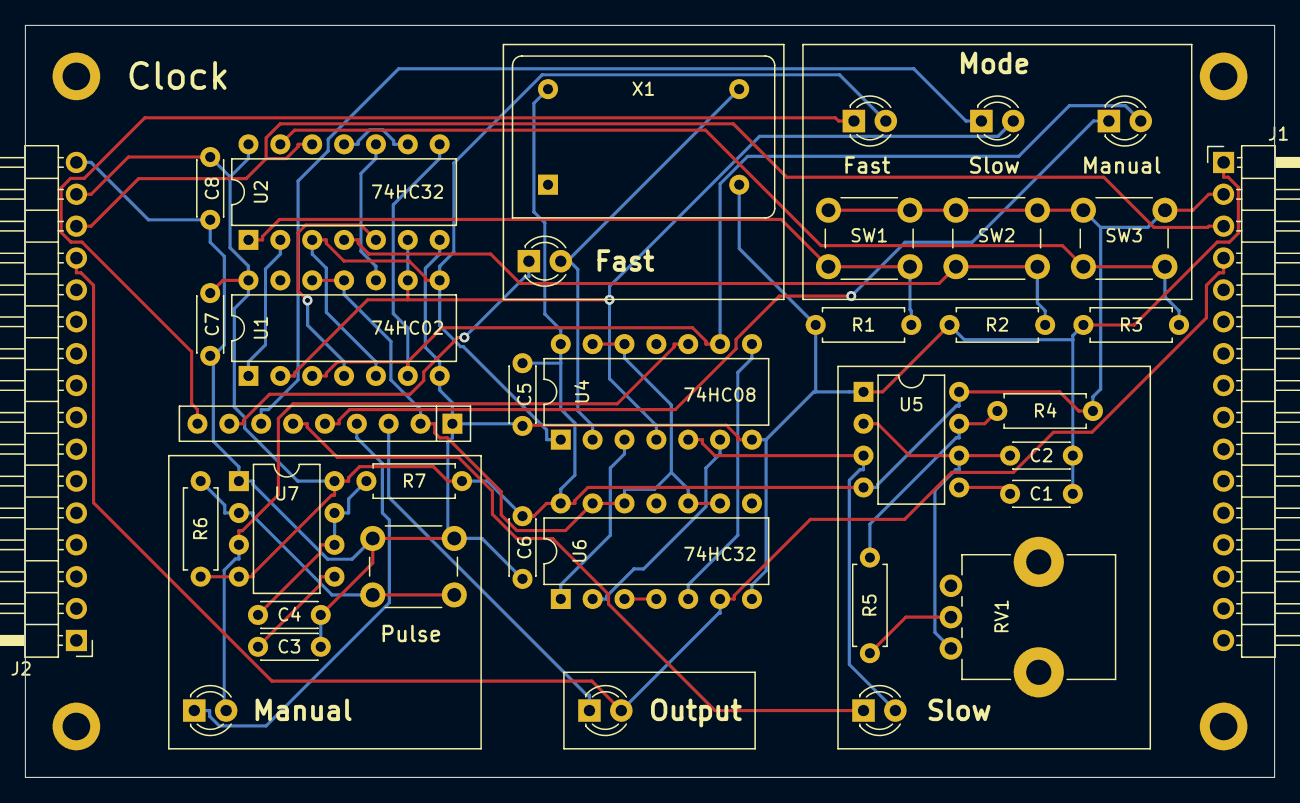
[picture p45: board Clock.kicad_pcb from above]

Board: 2 copper layers, 99.6 x 59.9 mm, 41 parts (0 on the bottom side), 36 nets.

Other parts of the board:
HOLE1, HOLE2, HOLE3, HOLE4: MountingHole_2.2mm_M2_DIN965_Pad

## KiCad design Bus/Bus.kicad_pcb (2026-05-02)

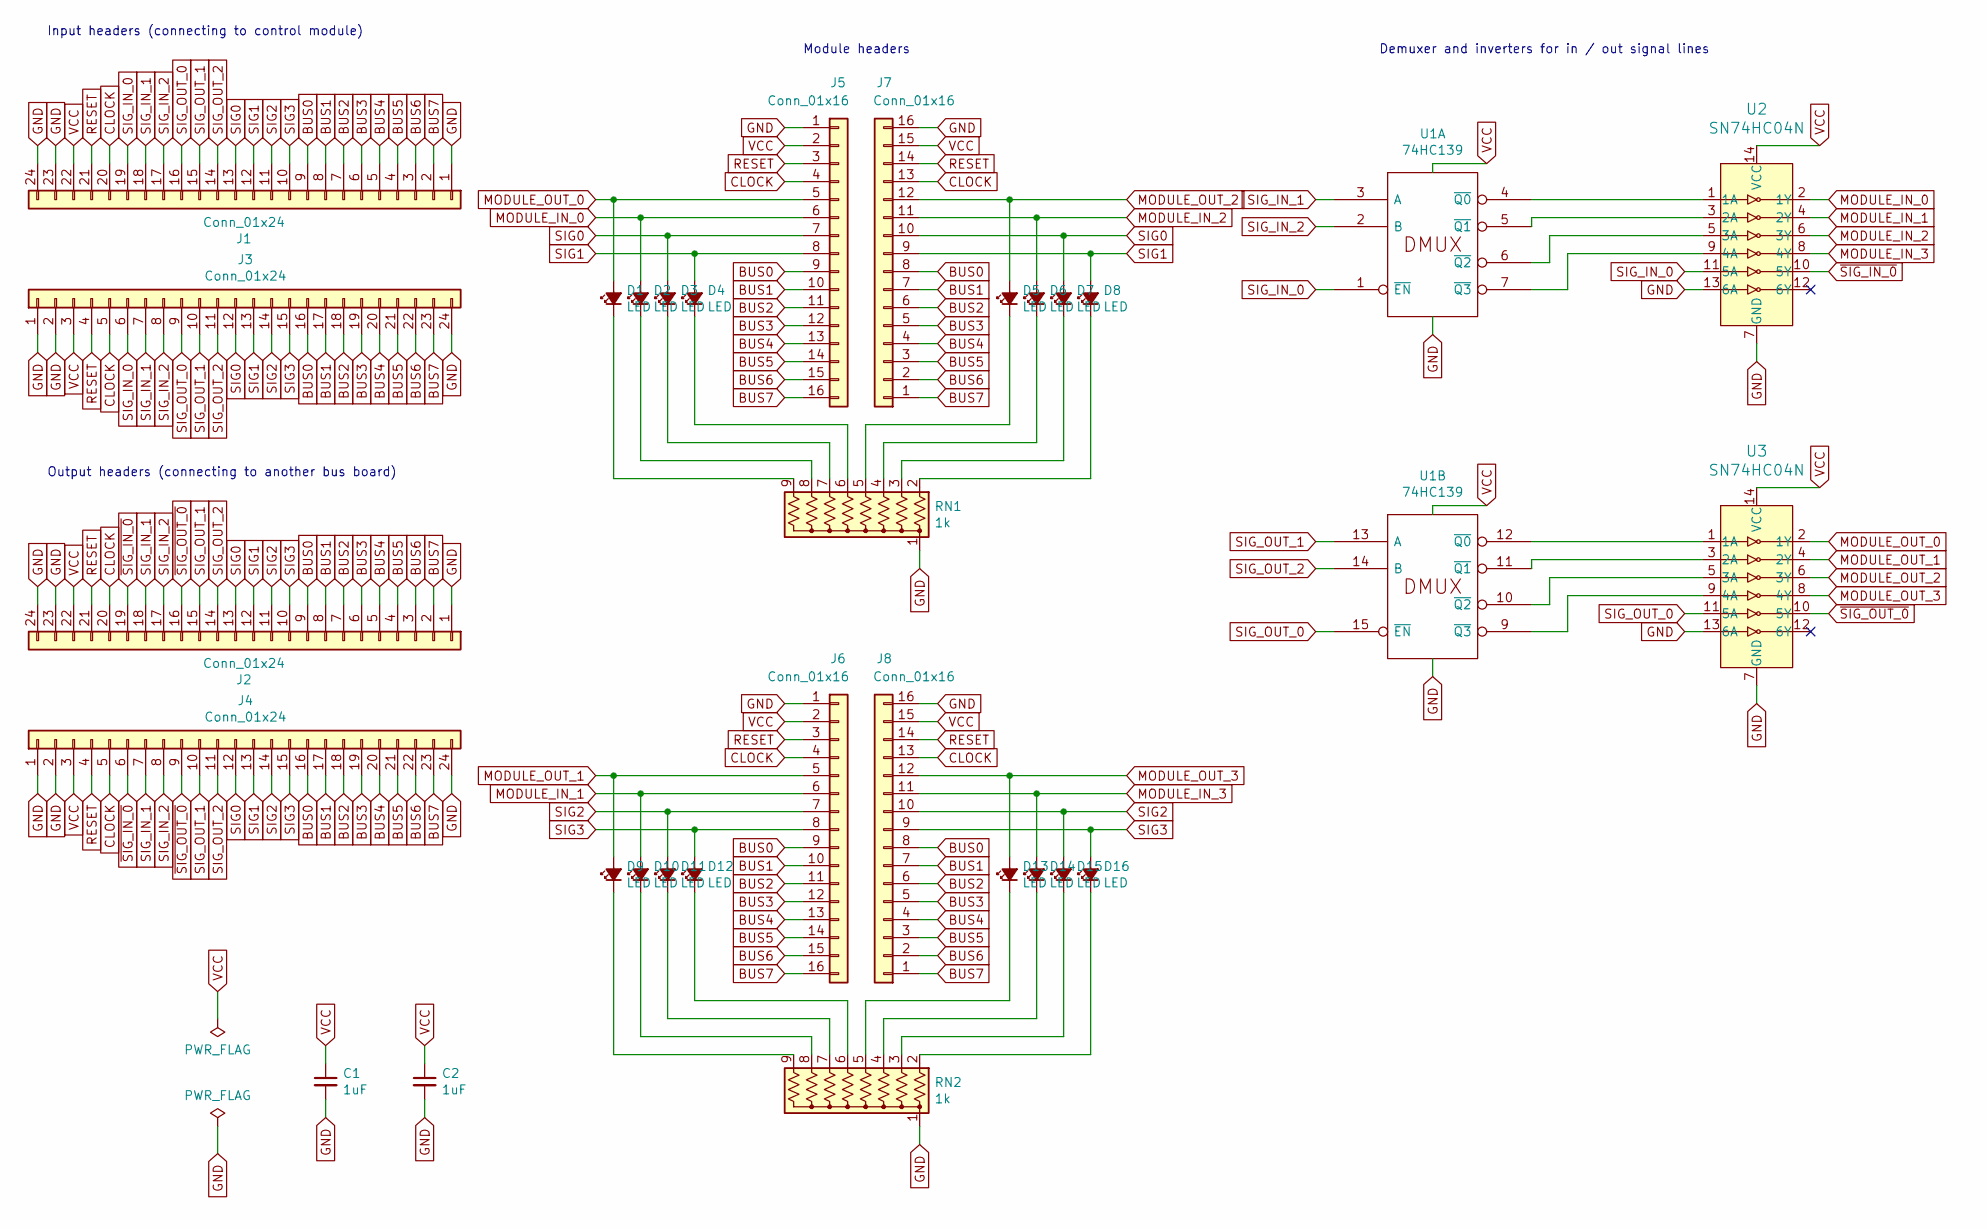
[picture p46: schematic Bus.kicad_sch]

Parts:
C1, C2: 1uF; C_Disc_D3.4mm_W2.1mm_P2.50mm
D1, D2, D3, D4, D5, D6, D7, D8, D9, D10, D11, D12, D13, D14, D15, D16: LED; LED_D3.0mm_Clear
J1, J3: Conn_01x24; PinHeader_1x24_P2.54mm_Horizontal
J2, J4: Conn_01x24; PinSocket_1x24_P2.54mm_Horizontal
J5, J6, J7, J8: Conn_01x16; PinSocket_1x16_P2.54mm_Horizontal
RN1, RN2: 1k; R_Array_SIP9
U1: 74HC139; DIP-16_W7.62mm
U2, U3: SN74HC04N; DIP-14_W7.62mm; MPN SN74LS04N; Digi-Key_PN 296-1629-5-ND

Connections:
BUS0: J1.9, J2.9, J3.16, J4.16, J5.9, J6.9, J7.8, J8.8
BUS1: J1.8, J2.8, J3.17, J4.17, J5.10, J6.10, J7.7, J8.7
BUS2: J1.7, J2.7, J3.18, J4.18, J5.11, J6.11, J7.6, J8.6
BUS3: J1.6, J2.6, J3.19, J4.19, J5.12, J6.12, J7.5, J8.5
BUS4: J1.5, J2.5, J3.20, J4.20, J5.13, J6.13, J7.4, J8.4
BUS5: J1.4, J2.4, J3.21, J4.21, J5.14, J6.14, J7.3, J8.3
BUS6: J1.3, J2.3, J3.22, J4.22, J5.15, J6.15, J7.2, J8.2
BUS7: J1.2, J2.2, J3.23, J4.23, J5.16, J6.16, J7.1, J8.1
CLOCK: J1.20, J2.20, J3.5, J4.5, J5.4, J6.4, J7.13, J8.13
GND: C1.2, C2.2, J1.1, J1.23, J1.24, J2.1, J2.23, J2.24, J3.1, J3.2, J3.24, J4.1, J4.2, J4.24, J5.1, J6.1, J7.16, J8.16, RN1.1 (common), RN2.1 (common), U1.8 (GND), U2.7 (GND), U2.13 (6A), U3.7 (GND), U3.13 (6A)
MODULE_IN_0: D2.2 (A), J5.6, U2.2 (1Y)
MODULE_IN_1: D10.2 (A), J6.6, U2.4 (2Y)
MODULE_IN_2: D6.2 (A), J7.11, U2.6 (3Y)
MODULE_IN_3: D14.2 (A), J8.11, U2.8 (4Y)
MODULE_OUT_0: D1.2 (A), J5.5, U3.2 (1Y)
MODULE_OUT_1: D9.2 (A), J6.5, U3.4 (2Y)
MODULE_OUT_2: D5.2 (A), J7.12, U3.6 (3Y)
MODULE_OUT_3: D13.2 (A), J8.12, U3.8 (4Y)
unnamed: D1.1 (K), RN1.9 (R8)
unnamed: D2.1 (K), RN1.8 (R7)
unnamed: D3.1 (K), RN1.7 (R6)
unnamed: D4.1 (K), RN1.6 (R5)
unnamed: D5.1 (K), RN1.5 (R4)
unnamed: D6.1 (K), RN1.4 (R3)
unnamed: D7.1 (K), RN1.3 (R2)
unnamed: D8.1 (K), RN1.2 (R1)
unnamed: D9.1 (K), RN2.9 (R8)
unnamed: D10.1 (K), RN2.8 (R7)
unnamed: D11.1 (K), RN2.7 (R6)
unnamed: D12.1 (K), RN2.6 (R5)
unnamed: D13.1 (K), RN2.5 (R4)
unnamed: D14.1 (K), RN2.4 (R3)
unnamed: D15.1 (K), RN2.3 (R2)
unnamed: D16.1 (K), RN2.2 (R1)
unnamed: U1.4 (~Q0), U2.1 (1A)
unnamed: U1.5 (~Q1), U2.3 (2A)
unnamed: U1.6 (~Q2), U2.5 (3A)
unnamed: U1.7 (~Q3), U2.9 (4A)
unnamed: U1.12 (~Q0), U3.1 (1A)
unnamed: U1.11 (~Q1), U3.3 (2A)
unnamed: U1.10 (~Q2), U3.5 (3A)
unnamed: U1.9 (~Q3), U3.9 (4A)
RESET: J1.21, J2.21, J3.4, J4.4, J5.3, J6.3, J7.14, J8.14
SIG0: D3.2 (A), D7.2 (A), J1.13, J2.13, J3.12, J4.12, J5.7, J7.10
SIG1: D4.2 (A), D8.2 (A), J1.12, J2.12, J3.13, J4.13, J5.8, J7.9
SIG2: D11.2 (A), D15.2 (A), J1.11, J2.11, J3.14, J4.14, J6.7, J8.10
SIG3: D12.2 (A), D16.2 (A), J1.10, J2.10, J3.15, J4.15, J6.8, J8.9
SIG_IN_0: J1.19, J3.6, U1.1 (~EN), U2.11 (5A)
SIG_IN_1: J1.18, J2.18, J3.7, J4.7, U1.3 (A)
SIG_IN_2: J1.17, J2.17, J3.8, J4.8, U1.2 (B)
SIG_OUT_0: J1.16, J3.9, U1.15 (~EN), U3.11 (5A)
SIG_OUT_1: J1.15, J2.15, J3.10, J4.10, U1.13 (A)
SIG_OUT_2: J1.14, J2.14, J3.11, J4.11, U1.14 (B)
VCC: C1.1, C2.1, J1.22, J2.22, J3.3, J4.3, J5.2, J6.2, J7.15, J8.15, U1.16 (VCC), U2.14 (VCC), U3.14 (VCC)
~SIG_IN_0: J2.19, J4.6, U2.10 (5Y)
~SIG_OUT_0: J2.16, J4.9, U3.10 (5Y)

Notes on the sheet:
Module headers
Output headers (connecting to another bus board)
Input headers (connecting to control module)
Demuxer and inverters for in / out signal lines

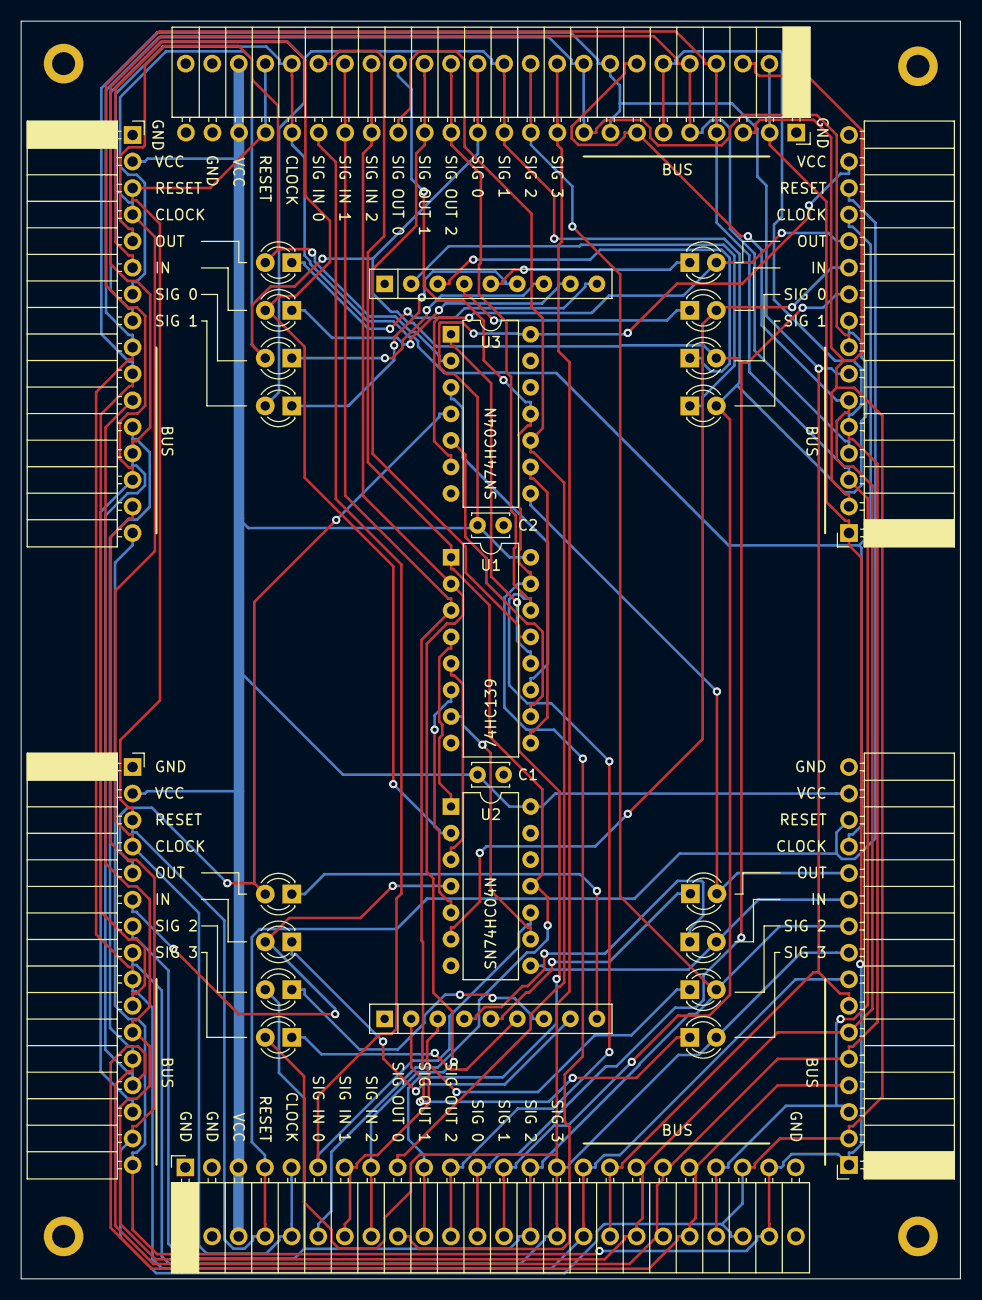
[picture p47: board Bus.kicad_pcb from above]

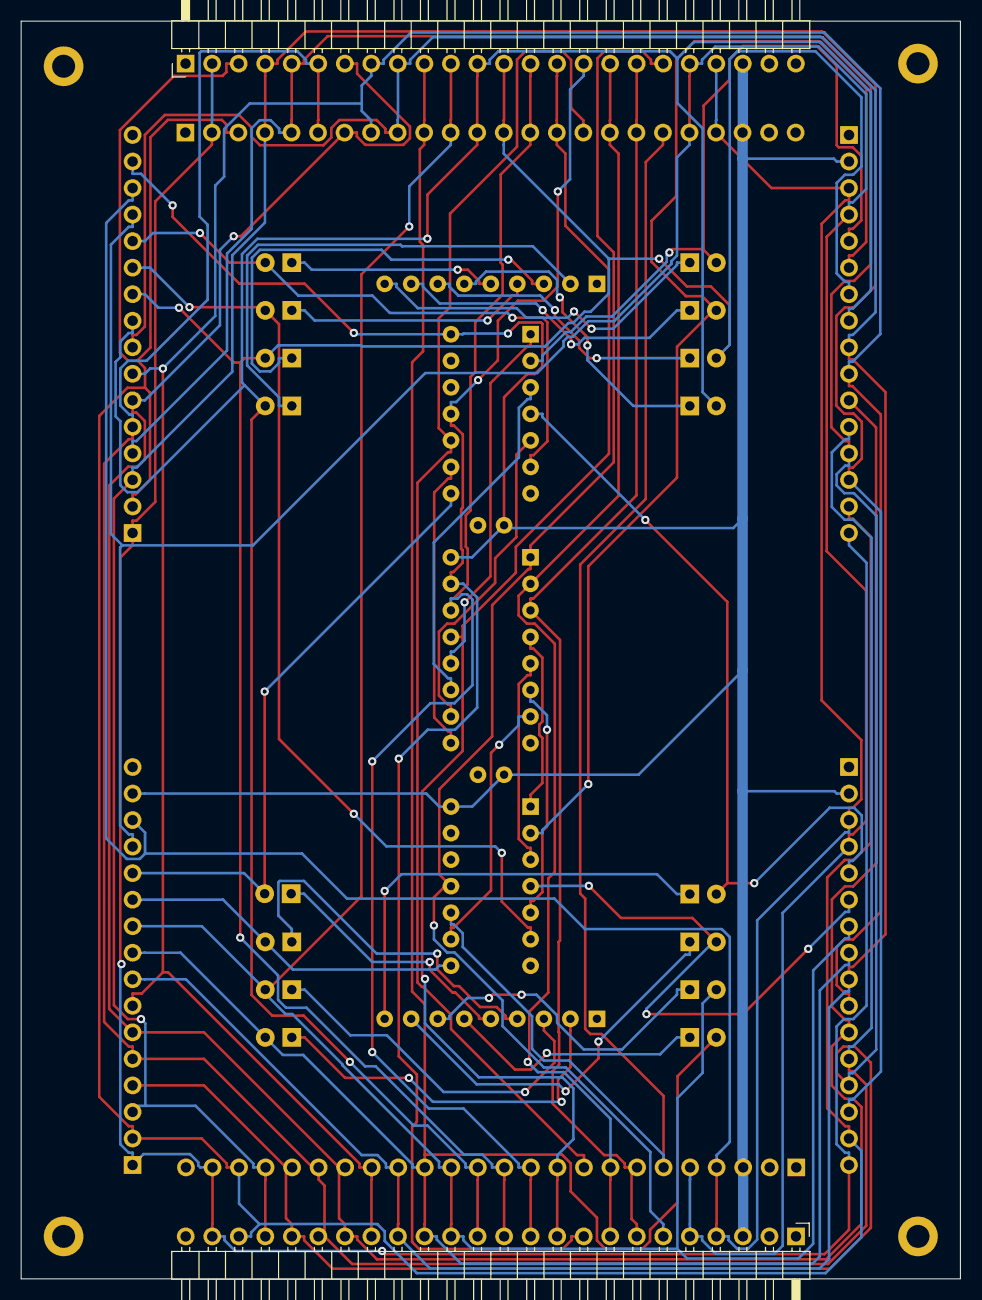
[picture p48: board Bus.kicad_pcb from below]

Board: 4 copper layers, 89.9 x 120.4 mm, 35 parts (2 on the bottom side), 56 nets.

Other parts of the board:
HOLE1, HOLE2, HOLE3, HOLE4: MountingHole_2.2mm_M2_DIN965_Pad

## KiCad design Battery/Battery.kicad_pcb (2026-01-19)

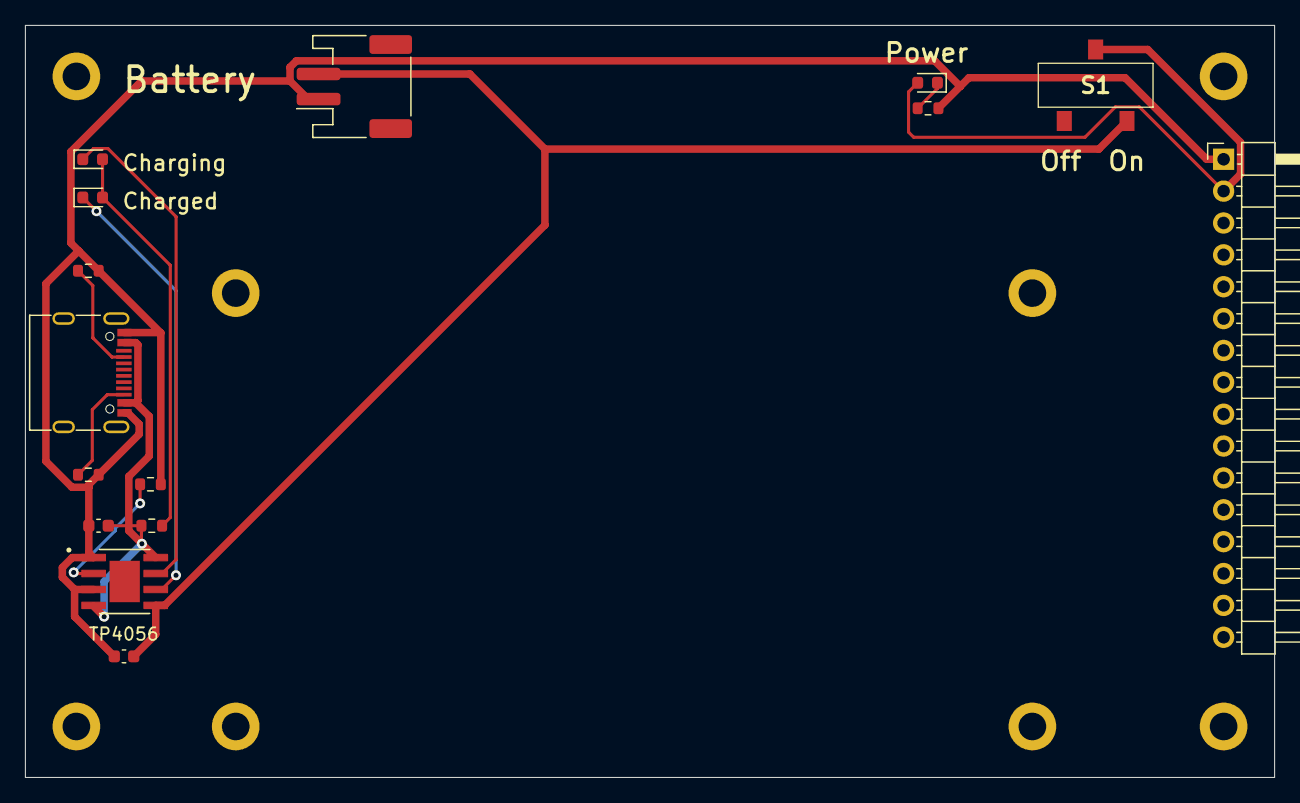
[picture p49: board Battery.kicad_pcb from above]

Board: 2 copper layers, 99.6 x 59.9 mm, 23 parts (0 on the bottom side), 11 nets.

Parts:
BT1: Battery; JST_PH_S2B-PH-SM4-TB_1x02-1MP_P2.00mm_Horizontal
C1, C2: 10uF; C_0603_1608Metric
D1: GREEN; LED_0603_1608Metric
D2: RED; LED_0603_1608Metric
D3: LED; LED_0603_1608Metric
HOLE1, HOLE2, HOLE3, HOLE4, HOLE5, HOLE6, HOLE7, HOLE8: MountingHole_2.2mm_M2_DIN965_Pad
J1: Conn_01x16; PinHeader_1x16_P2.54mm_Horizontal
J4: USB_C_Receptacle_PowerOnly_6P; USB_C_Receptacle_G-Switch_GT-USB-7010ASV
R1: 1.2k; R_0603_1608Metric
R2, R5: 10k; R_0603_1608Metric
R3, R4: 5.1k; R_0603_1608Metric
S1: SS-3235D-03-L2; SS3235D03L2
U1: TP4056; SOP127P600X175-9N

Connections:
GND: BT1.1, C1.2, C2.2, J1.1, J4.A12 (GND), J4.B12 (GND), R1.1, R3.1, R4.1, R5.1, U1.1 (TEMP), U1.3 (GND)
unnamed: BT1.2, C2.1, S1.3, U1.5 (BAT)
unnamed: D1.2 (A), D2.2 (A), R2.1
unnamed: D1.1 (K), U1.6 (~STDBY)
unnamed: D2.1 (K), U1.7 (~CHRG)
unnamed: D3.1 (K), R5.2
unnamed: J4.A5 (CC1), R4.2
unnamed: J4.B5 (CC2), R3.2
unnamed: C1.1, J4.A9 (VBUS), J4.B9 (VBUS), R2.2, U1.4 (VCC), U1.8 (CE)
unnamed: R1.2, U1.2 (PROG)
VCC: D3.2 (A), J1.2, S1.2

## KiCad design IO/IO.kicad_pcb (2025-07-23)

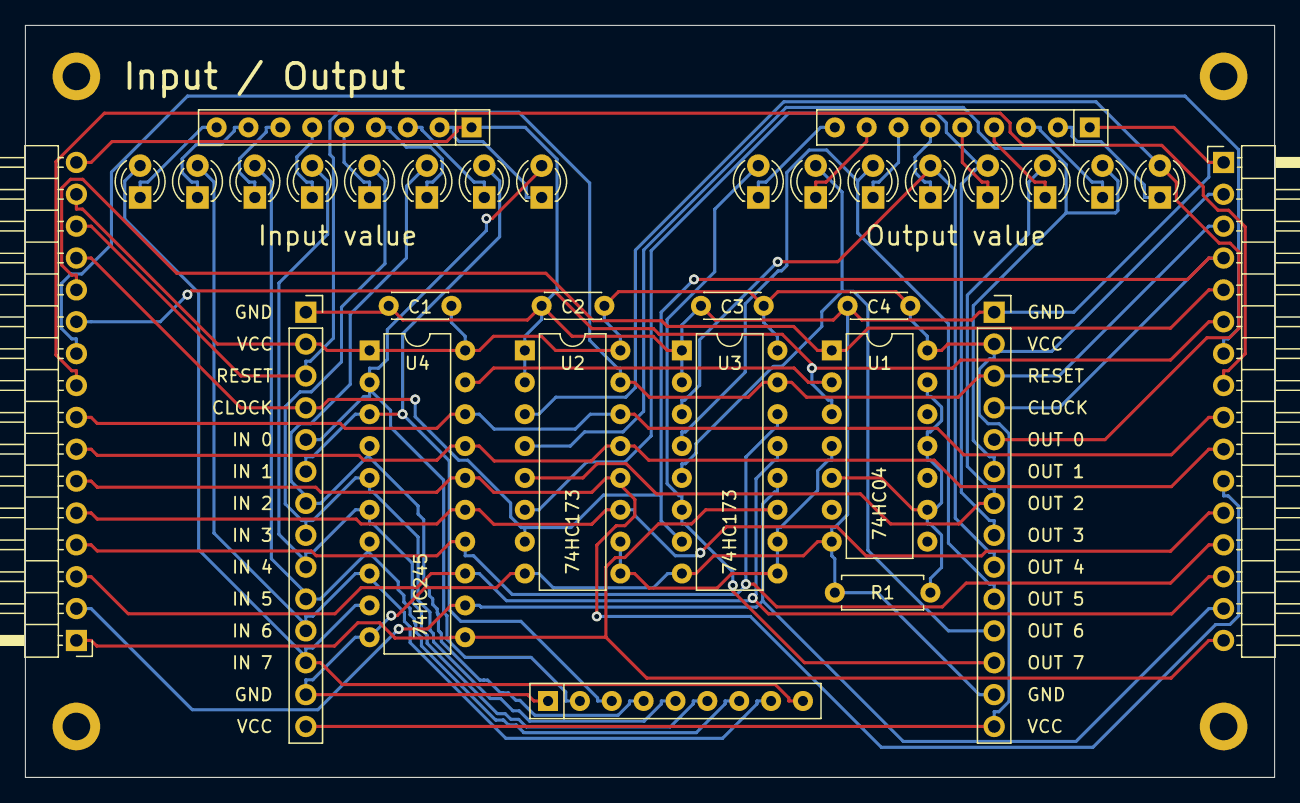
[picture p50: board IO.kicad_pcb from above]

Board: 2 copper layers, 99.6 x 59.9 mm, 36 parts (0 on the bottom side), 51 nets.

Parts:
C1, C2, C3, C4: 100nF; C_Disc_D4.3mm_W1.9mm_P5.00mm
D1, D2, D3, D4, D5, D6, D7, D8, D9, D10, D11, D12, D13, D14, D15, D16: LED; LED_D3.0mm_Clear
HOLE1, HOLE2, HOLE3, HOLE4: MountingHole_2.2mm_M2_DIN965_Pad
J1, J2: Conn_01x16; PinHeader_1x16_P2.54mm_Horizontal
J3, J4: Conn_01x14; PinSocket_1x14_P2.54mm_Vertical
R1: 10k; R_Axial_DIN0207_L6.3mm_D2.5mm_P7.62mm_Horizontal
RN1, RN2: 1k; R_Array_SIP9
RN3: 100k; R_Array_SIP9
U1: 74HC04; DIP-14_W7.62mm
U2, U3: 74HC173; DIP-16_W7.62mm
U4: 74HC245; DIP-20_W7.62mm

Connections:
BUS0: J1.9, J2.8, U2.14 (D0), U4.18 (B0)
BUS1: J1.10, J2.7, U2.13 (D1), U4.17 (B1)
BUS2: J1.11, J2.6, U2.12 (D2), U4.16 (B2)
BUS3: J1.12, J2.5, U2.11 (D3), U4.15 (B3)
BUS4: J1.13, J2.4, U3.14 (D0), U4.14 (B4)
BUS5: J1.14, J2.3, U3.13 (D1), U4.13 (B5)
BUS6: J1.15, J2.2, U3.12 (D2), U4.12 (B6)
BUS7: J1.16, J2.1, U3.11 (D3), U4.11 (B7)
CLOCK: J1.4, J2.13, J3.4, J4.4, U2.7 (Cp), U3.7 (Cp)
GND: C1.2, C2.2, C3.2, C4.2, J1.1, J2.16, J3.1, J3.13, J4.1, J4.13, R1.1, RN1.1 (common), RN2.1 (common), RN3.1 (common), U1.7 (GND), U2.1 (Oe1), U2.2 (Oe2), U2.8 (GND), U3.1 (Oe1), U3.2 (Oe2), U3.8 (GND), U4.10 (GND)
IN0: D16.2 (A), J4.5, RN3.2 (R1), U4.2 (A0)
IN1: D15.2 (A), J4.6, RN3.3 (R2), U4.3 (A1)
IN2: D14.2 (A), J4.7, RN3.4 (R3), U4.4 (A2)
IN3: D13.2 (A), J4.8, RN3.5 (R4), U4.5 (A3)
IN4: D12.2 (A), J4.9, RN3.6 (R5), U4.6 (A4)
IN5: D11.2 (A), J4.10, RN3.7 (R6), U4.7 (A5)
IN6: D10.2 (A), J4.11, RN3.8 (R7), U4.8 (A6)
IN7: D9.2 (A), J4.12, RN3.9 (R8), U4.9 (A7)
unnamed: D1.1 (K), RN1.9 (R8)
unnamed: D2.1 (K), RN1.8 (R7)
unnamed: D3.1 (K), RN1.7 (R6)
unnamed: D4.1 (K), RN1.6 (R5)
unnamed: D5.1 (K), RN1.5 (R4)
unnamed: D6.1 (K), RN1.4 (R3)
unnamed: D7.1 (K), RN1.3 (R2)
unnamed: D8.1 (K), RN1.2 (R1)
unnamed: D9.1 (K), RN2.9 (R8)
unnamed: D10.1 (K), RN2.8 (R7)
unnamed: D11.1 (K), RN2.7 (R6)
unnamed: D12.1 (K), RN2.6 (R5)
unnamed: D13.1 (K), RN2.5 (R4)
unnamed: D14.1 (K), RN2.4 (R3)
unnamed: D15.1 (K), RN2.3 (R2)
unnamed: D16.1 (K), RN2.2 (R1)
unnamed: R1.2, U1.5, U1.9, U1.11, U1.13
R0: D8.2 (A), J3.5, U2.3 (Q0)
R1: D7.2 (A), J3.6, U2.4 (Q1)
R2: D6.2 (A), J3.7, U2.5 (Q2)
R3: D5.2 (A), J3.8, U2.6 (Q3)
R4: D4.2 (A), J3.9, U3.3 (Q0)
R5: D3.2 (A), J3.10, U3.4 (Q1)
R6: D2.2 (A), J3.11, U3.5 (Q2)
R7: D1.2 (A), J3.12, U3.6 (Q3)
RESET: J1.3, J2.14, J3.3, J4.3, U2.15 (Mr), U3.15 (Mr)
SIG0: J1.7, J2.10
SIG1: J1.8, J2.9
SIG_IN: J1.6, J2.11, U1.3
SIG_OUT: J1.5, J2.12, U1.1
VCC: C1.1, C2.1, C3.1, C4.1, J1.2, J2.15, J3.2, J3.14, J4.2, J4.14, U1.14 (VCC), U2.16 (VCC), U3.16 (VCC), U4.1 (A->B), U4.20 (VCC)
~SIG_IN: U1.4, U2.9 (E1), U2.10 (E2), U3.9 (E1), U3.10 (E2)
~SIG_OUT: U1.2, U4.19 (CE)

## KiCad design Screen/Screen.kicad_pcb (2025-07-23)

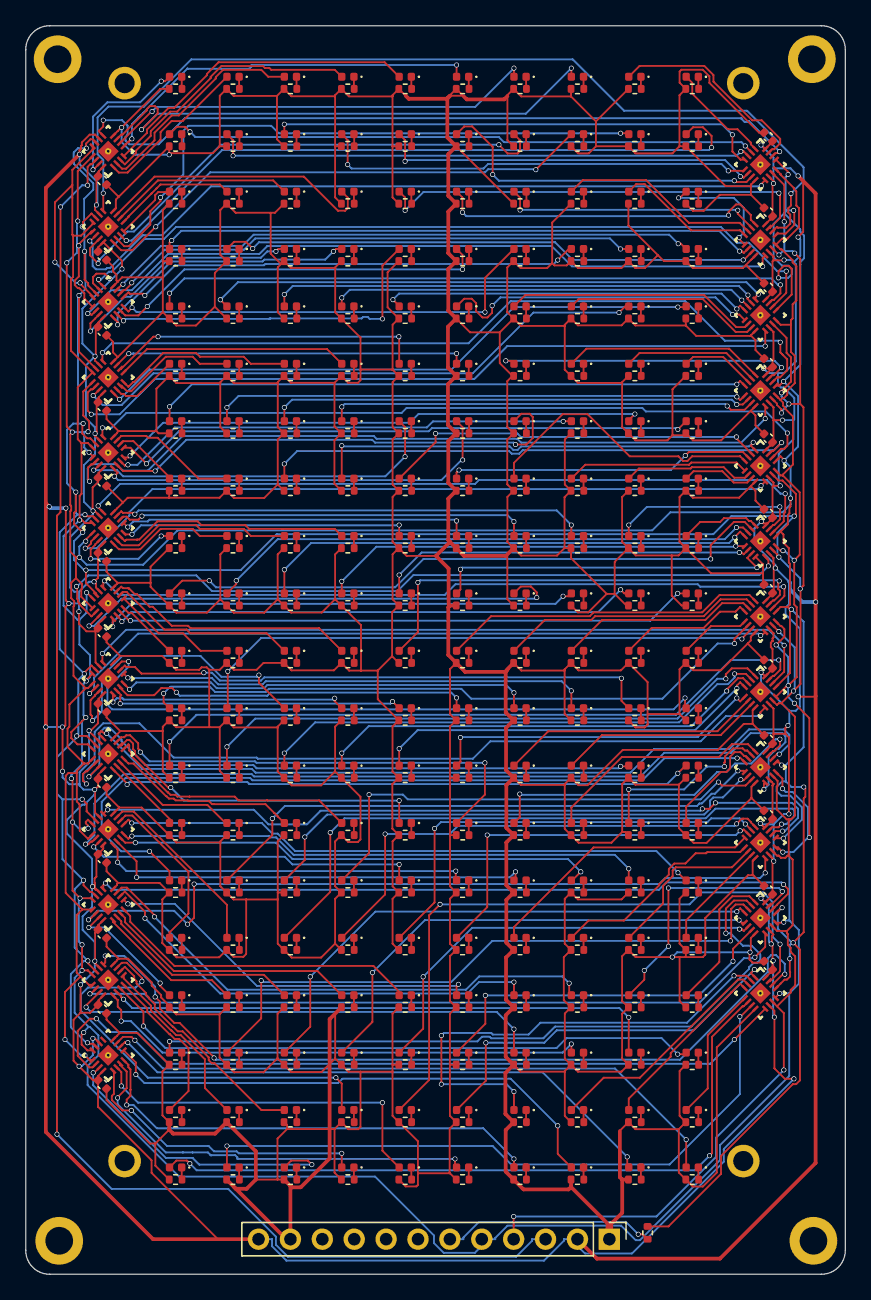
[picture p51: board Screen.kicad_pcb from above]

Board: 2 copper layers, 65.3 x 99.4 mm, 460 parts (0 on the bottom side), 431 nets.

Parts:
C1, C2, C3, C4, C5, C6, C7, C8, C9, C10, C11, C12, C13, C14, C15, C16, C17, C18, C19, C20, C21, C22, C23, C24, C25: 0.1uF; C_0402_1005Metric
D1, D2, D3, D4, D5, D6, D7, D8, D9, D10, D11, D12, D13, D14, D15, D16, D17, D18, D19, D20, D21, D22, D23, D24, D25, D26, D27, D28, D29, D30, D31, D32, D33, D34, D35, D36, D37, D38, D39, D40, D41, D42, D43, D44, D45, D46, D47, D48, D49, D50, D51, D52, D53, D54, D55, D56, D57, D58, D59, D60, D61, D62, D63, D64, D65, D66, D67, D68, D69, D70, D71, D72, D73, D74, D75, D76, D77, D78, D79, D80, D81, D82, D83, D84, D85, D86, D87, D88, D89, D90, D91, D92, D93, D94, D95, D96, D97, D98, D99, D100, D101, D102, D103, D104, D105, D106, D107, D108, D109, D110, D111, D112, D113, D114, D115, D116, D117, D118, D119, D120, D121, D122, D123, D124, D125, D126, D127, D128, D129, D130, D131, D132, D133, D134, D135, D136, D137, D138, D139, D140, D141, D142, D143, D144, D145, D146, D147, D148, D149, D150, D151, D152, D153, D154, D155, D156, D157, D158, D159, D160, D161, D162, D163, D164, D165, D166, D167, D168, D169, D170, D171, D172, D173, D174, D175, D176, D177, D178, D179, D180, D181, D182, D183, D184, D185, D186, D187, D188, D189, D190, D191, D192, D193, D194, D195, D196, D197, D198, D199, D200: LED; LED_0402_1005Metric
HOLE1, HOLE2, HOLE3, HOLE4: MountingHole_1.6mm_M1.4_Pad
HOLE5, HOLE6, HOLE7, HOLE8: MountingHole_2.2mm_M2_DIN965_Pad
J1: Conn_01x12; PinHeader_1x12_P2.54mm_Vertical
R1, R2, R3, R4, R5, R6, R7, R8, R9, R10, R11, R12, R13, R14, R15, R16, R17, R18, R19, R20, R21, R22, R23, R24, R25, R26, R27, R28, R29, R30, R31, R32, R33, R34, R35, R36, R37, R38, R39, R40, R41, R42, R43, R44, R45, R46, R47, R48, R49, R50, R51, R52, R53, R54, R55, R56, R57, R58, R59, R60, R61, R62, R63, R64, R65, R66, R67, R68, R69, R70, R71, R72, R73, R74, R75, R76, R77, R78, R79, R80, R81, R82, R83, R84, R85, R86, R87, R88, R89, R90, R91, R92, R93, R94, R95, R96, R97, R98, R99, R100, R101, R102, R103, R104, R105, R106, R107, R108, R109, R110, R111, R112, R113, R114, R115, R116, R117, R118, R119, R120, R121, R122, R123, R124, R125, R126, R127, R128, R129, R130, R131, R132, R133, R134, R135, R136, R137, R138, R139, R140, R141, R142, R143, R144, R145, R146, R147, R148, R149, R150, R151, R152, R153, R154, R155, R156, R157, R158, R159, R160, R161, R162, R163, R164, R165, R166, R167, R168, R169, R170, R171, R172, R173, R174, R175, R176, R177, R178, R179, R180, R181, R182, R183, R184, R185, R186, R187, R188, R189, R190, R191, R192, R193, R194, R195, R196, R197, R198, R199, R200, R201: 10k; R_0402_1005Metric
U1, U2, U3, U4, U5, U6, U7, U8, U9, U10, U11, U12, U13, U14, U15, U16, U17, U18, U19, U20, U21, U22, U23, U24, U25: 74HC595; RWN0016A

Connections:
/LED_Row1/QH': U2.9 (QH'), U3.14 (SER)
/LED_Row2/QH': U3.9 (QH'), U4.14 (SER)
/LED_Row3/QH': U4.9 (QH'), U5.14 (SER)
/LED_Row4/QH': U5.9 (QH'), U6.14 (SER)
/LED_Row5/QH': U6.9 (QH'), U7.14 (SER)
/LED_Row6/QH': U7.9 (QH'), U8.14 (SER)
/LED_Row7/QH': U8.9 (QH'), U9.14 (SER)
/LED_Row8/QH': U9.9 (QH'), U10.14 (SER)
/LED_Row10/QH': U13.9 (QH'), U14.14 (SER)
/LED_Row10/SER: U12.9 (QH'), U13.14 (SER)
/LED_Row11/QH': U14.9 (QH'), U15.14 (SER)
/LED_Row12/QH': U15.9 (QH'), U16.14 (SER)
/LED_Row13/SER: U11.9 (QH'), U12.14 (SER)
/LED_Row14/SER: U10.9 (QH'), U11.14 (SER)
/LED_Row15/QH': U18.9 (QH'), U19.14 (SER)
/LED_Row15/SER: U17.9 (QH'), U18.14 (SER)
/LED_Row16/QH': U20.9 (QH'), U21.14 (SER)
/LED_Row16/SER: U19.9 (QH'), U20.14 (SER)
/LED_Row18/SER: U16.9 (QH'), U17.14 (SER)
/LED_Row20/QH': U21.9 (QH'), U22.14 (SER)
/LED_Row21/QH': U22.9 (QH'), U23.14 (SER)
/LED_Row22/QH': U24.9 (QH'), U25.14 (SER)
/LED_Row22/SER: U23.9 (QH'), U24.14 (SER)
/LED_Row/QH': U1.9 (QH'), U2.14 (SER)
DisplayOE: R201.1, U1.13 (~OE), U2.13 (~OE), U3.13 (~OE), U4.13 (~OE), U5.13 (~OE), U6.13 (~OE), U7.13 (~OE), U8.13 (~OE), U9.13 (~OE), U10.13 (~OE), U11.13 (~OE), U12.13 (~OE), U13.13 (~OE), U14.13 (~OE), U15.13 (~OE), U16.13 (~OE), U17.13 (~OE), U18.13 (~OE), U19.13 (~OE), U20.13 (~OE), U21.13 (~OE), U22.13 (~OE), U23.13 (~OE), U24.13 (~OE), U25.13 (~OE)
DisplayRCLK: J1.5, U1.12 (RCLK), U2.12 (RCLK), U3.12 (RCLK), U4.12 (RCLK), U5.12 (RCLK), U6.12 (RCLK), U7.12 (RCLK), U8.12 (RCLK), U9.12 (RCLK), U10.12 (RCLK), U11.12 (RCLK), U12.12 (RCLK), U13.12 (RCLK), U14.12 (RCLK), U15.12 (RCLK), U16.12 (RCLK), U17.12 (RCLK), U18.12 (RCLK), U19.12 (RCLK), U20.12 (RCLK), U21.12 (RCLK), U22.12 (RCLK), U23.12 (RCLK), U24.12 (RCLK), U25.12 (RCLK)
DisplaySER: J1.3, U1.14 (SER)
DisplaySRCLK: J1.4, U1.11 (SRCLK), U2.11 (SRCLK), U3.11 (SRCLK), U4.11 (SRCLK), U5.11 (SRCLK), U6.11 (SRCLK), U7.11 (SRCLK), U8.11 (SRCLK), U9.11 (SRCLK), U10.11 (SRCLK), U11.11 (SRCLK), U12.11 (SRCLK), U13.11 (SRCLK), U14.11 (SRCLK), U15.11 (SRCLK), U16.11 (SRCLK), U17.11 (SRCLK), U18.11 (SRCLK), U19.11 (SRCLK), U20.11 (SRCLK), U21.11 (SRCLK), U22.11 (SRCLK), U23.11 (SRCLK), U24.11 (SRCLK), U25.11 (SRCLK)
GND: C1.2, C2.2, C3.2, C4.2, C5.2, C6.2, C7.2, C8.2, C9.2, C10.2, C11.2, C12.2, C13.2, C14.2, C15.2, C16.2, C17.2, C18.2, C19.2, C20.2, C21.2, C22.2, C23.2, C24.2, C25.2, J1.1, J1.11, R1.1, R2.1, R3.1, R4.1, R5.1, R6.1, R7.1, R8.1, R9.1, R10.1, R11.1, R12.1, R13.1, R14.1, R15.1, R16.1, R17.1, R18.1, R19.1, R20.1, R21.1, R22.1, R23.1, R24.1, R25.1, R26.1, R27.1, R28.1, R29.1, R30.1, R31.1, R32.1, R33.1, R34.1, R35.1, R36.1, R37.1, R38.1, R39.1, R40.1, R41.1, R42.1, R43.1, R44.1, R45.1, R46.1, R47.1, R48.1, R49.1, R50.1, R51.1, R52.1, R53.1, R54.1, R55.1, R56.1, R57.1, R58.1, R59.1, R60.1, R61.1, R62.1, R63.1, R64.1, R65.1, R66.1, R67.1, R68.1, R69.1, R70.1, R71.1, R72.1, R73.1, R74.1, R75.1, R76.1, R77.1, R78.1, R79.1, R80.1, R81.1, R82.1, R83.1, R84.1, R85.1, R86.1, R87.1, R88.1, R89.1, R90.1, R91.1, R92.1, R93.1, R94.1, R95.1, R96.1, R97.1, R98.1, R99.1, R100.1, R101.1, R102.1, R103.1, R104.1, R105.1, R106.1, R107.1, R108.1, R109.1, R110.1, R111.1, R112.1, R113.1, R114.1, R115.1, R116.1, R117.1, R118.1, R119.1, R120.1, R121.1, R122.1, R123.1, R124.1, R125.1, R126.1, R127.1, R128.1, R129.1, R130.1, R131.1, R132.1, R133.1, R134.1, R135.1, R136.1, R137.1, R138.1, R139.1, R140.1, R141.1, R142.1, R143.1, R144.1, R145.1, R146.1, R147.1, R148.1, R149.1, R150.1, R151.1, R152.1, R153.1, R154.1, R155.1, R156.1, R157.1, R158.1, R159.1, R160.1, R161.1, R162.1, R163.1, R164.1, R165.1, R166.1, R167.1, R168.1, R169.1, R170.1, R171.1, R172.1, R173.1, R174.1, R175.1, R176.1, R177.1, R178.1, R179.1, R180.1, R181.1, R182.1, R183.1, R184.1, R185.1, R186.1, R187.1, R188.1, R189.1, R190.1, R191.1, R192.1, R193.1, R194.1, R195.1, R196.1, R197.1, R198.1, R199.1, R200.1, U1.8 (GND), U2.8 (GND), U3.8 (GND), U4.8 (GND), U5.8 (GND), U6.8 (GND), U7.8 (GND), U8.8 (GND), U9.8 (GND), U10.8 (GND), U11.8 (GND), U12.8 (GND), U13.8 (GND), U14.8 (GND), U15.8 (GND), U16.8 (GND), U17.8 (GND), U18.8 (GND), U19.8 (GND), U20.8 (GND), U21.8 (GND), U22.8 (GND), U23.8 (GND), U24.8 (GND), U25.8 (GND)
unnamed: D1.2 (A), U1.15 (QA)
unnamed: D1.1 (K), R1.2
unnamed: D2.2 (A), U1.1 (QB)
unnamed: D2.1 (K), R2.2
unnamed: D3.2 (A), U1.2 (QC)
unnamed: D3.1 (K), R3.2
unnamed: D4.2 (A), U1.3 (QD)
unnamed: D4.1 (K), R4.2
unnamed: D5.2 (A), U1.4 (QE)
unnamed: D5.1 (K), R5.2
unnamed: D6.2 (A), U1.5 (QF)
unnamed: D6.1 (K), R6.2
unnamed: D7.2 (A), U1.6 (QG)
unnamed: D7.1 (K), R7.2
unnamed: D8.2 (A), U1.7 (QH)
unnamed: D8.1 (K), R8.2
unnamed: D9.2 (A), U2.15 (QA)
unnamed: D9.1 (K), R9.2
unnamed: D10.2 (A), U2.1 (QB)
unnamed: D10.1 (K), R10.2
unnamed: D11.2 (A), U2.2 (QC)
unnamed: D11.1 (K), R11.2
unnamed: D12.2 (A), U2.3 (QD)
unnamed: D12.1 (K), R12.2
unnamed: D13.2 (A), U2.4 (QE)
unnamed: D13.1 (K), R13.2
unnamed: D14.2 (A), U2.5 (QF)
unnamed: D14.1 (K), R14.2
unnamed: D15.2 (A), U2.6 (QG)
unnamed: D15.1 (K), R15.2
unnamed: D16.2 (A), U2.7 (QH)
unnamed: D16.1 (K), R16.2
unnamed: D17.2 (A), U3.15 (QA)
unnamed: D17.1 (K), R17.2
unnamed: D18.2 (A), U3.1 (QB)
unnamed: D18.1 (K), R18.2
unnamed: D19.2 (A), U3.2 (QC)
unnamed: D19.1 (K), R19.2
unnamed: D20.2 (A), U3.3 (QD)
unnamed: D20.1 (K), R20.2
unnamed: D21.2 (A), U3.4 (QE)
unnamed: D21.1 (K), R21.2
unnamed: D22.2 (A), U3.5 (QF)
unnamed: D22.1 (K), R22.2
unnamed: D23.2 (A), U3.6 (QG)
unnamed: D23.1 (K), R23.2
unnamed: D24.2 (A), U3.7 (QH)
unnamed: D24.1 (K), R24.2
unnamed: D25.2 (A), U4.15 (QA)
unnamed: D25.1 (K), R25.2
unnamed: D26.2 (A), U4.1 (QB)
unnamed: D26.1 (K), R26.2
unnamed: D27.2 (A), U4.2 (QC)
unnamed: D27.1 (K), R27.2
unnamed: D28.2 (A), U4.3 (QD)
unnamed: D28.1 (K), R28.2
unnamed: D29.2 (A), U4.4 (QE)
unnamed: D29.1 (K), R29.2
unnamed: D30.2 (A), U4.5 (QF)
unnamed: D30.1 (K), R30.2
unnamed: D31.2 (A), U4.6 (QG)
unnamed: D31.1 (K), R31.2
unnamed: D32.2 (A), U4.7 (QH)
unnamed: D32.1 (K), R32.2
unnamed: D33.2 (A), U5.15 (QA)
unnamed: D33.1 (K), R33.2
unnamed: D34.2 (A), U5.1 (QB)
unnamed: D34.1 (K), R34.2
unnamed: D35.2 (A), U5.2 (QC)
unnamed: D35.1 (K), R35.2
unnamed: D36.2 (A), U5.3 (QD)
unnamed: D36.1 (K), R36.2
unnamed: D37.2 (A), U5.4 (QE)
unnamed: D37.1 (K), R37.2
unnamed: D38.2 (A), U5.5 (QF)
unnamed: D38.1 (K), R38.2
unnamed: D39.2 (A), U5.6 (QG)
unnamed: D39.1 (K), R39.2
unnamed: D40.2 (A), U5.7 (QH)
unnamed: D40.1 (K), R40.2
unnamed: D41.2 (A), U6.15 (QA)
unnamed: D41.1 (K), R41.2
unnamed: D42.2 (A), U6.1 (QB)
unnamed: D42.1 (K), R42.2
unnamed: D43.2 (A), U6.2 (QC)
unnamed: D43.1 (K), R43.2
unnamed: D44.2 (A), U6.3 (QD)
unnamed: D44.1 (K), R44.2
unnamed: D45.2 (A), U6.4 (QE)
unnamed: D45.1 (K), R45.2
unnamed: D46.2 (A), U6.5 (QF)
unnamed: D46.1 (K), R46.2
unnamed: D47.2 (A), U6.6 (QG)
unnamed: D47.1 (K), R47.2
unnamed: D48.2 (A), U6.7 (QH)
unnamed: D48.1 (K), R48.2
unnamed: D49.2 (A), U7.15 (QA)
unnamed: D49.1 (K), R49.2
unnamed: D50.2 (A), U7.1 (QB)
unnamed: D50.1 (K), R50.2
unnamed: D51.2 (A), U7.2 (QC)
unnamed: D51.1 (K), R51.2
unnamed: D52.2 (A), U7.3 (QD)
unnamed: D52.1 (K), R52.2
unnamed: D53.2 (A), U7.4 (QE)
unnamed: D53.1 (K), R53.2
unnamed: D54.2 (A), U7.5 (QF)
unnamed: D54.1 (K), R54.2
unnamed: D55.2 (A), U7.6 (QG)
unnamed: D55.1 (K), R55.2
unnamed: D56.2 (A), U7.7 (QH)
unnamed: D56.1 (K), R56.2
unnamed: D57.2 (A), U8.15 (QA)
unnamed: D57.1 (K), R57.2
unnamed: D58.2 (A), U8.1 (QB)
unnamed: D58.1 (K), R58.2
unnamed: D59.2 (A), U8.2 (QC)
unnamed: D59.1 (K), R59.2
unnamed: D60.2 (A), U8.3 (QD)
unnamed: D60.1 (K), R60.2
unnamed: D61.2 (A), U8.4 (QE)
unnamed: D61.1 (K), R61.2
unnamed: D62.2 (A), U8.5 (QF)
unnamed: D62.1 (K), R62.2
unnamed: D63.2 (A), U8.6 (QG)
unnamed: D63.1 (K), R63.2
unnamed: D64.2 (A), U8.7 (QH)
unnamed: D64.1 (K), R64.2
unnamed: D65.2 (A), U9.15 (QA)
unnamed: D65.1 (K), R65.2
unnamed: D66.2 (A), U9.1 (QB)
unnamed: D66.1 (K), R66.2
unnamed: D67.2 (A), U9.2 (QC)
unnamed: D67.1 (K), R67.2
unnamed: D68.2 (A), U9.3 (QD)
unnamed: D68.1 (K), R68.2
unnamed: D69.2 (A), U9.4 (QE)
unnamed: D69.1 (K), R69.2
unnamed: D70.2 (A), U9.5 (QF)
unnamed: D70.1 (K), R70.2
unnamed: D71.2 (A), U9.6 (QG)
unnamed: D71.1 (K), R71.2
unnamed: D72.2 (A), U9.7 (QH)
unnamed: D72.1 (K), R72.2
unnamed: D73.2 (A), U10.15 (QA)
unnamed: D73.1 (K), R73.2
unnamed: D74.2 (A), U10.1 (QB)
unnamed: D74.1 (K), R74.2
unnamed: D75.2 (A), U10.2 (QC)
unnamed: D75.1 (K), R75.2
unnamed: D76.2 (A), U10.3 (QD)
unnamed: D76.1 (K), R76.2
unnamed: D77.2 (A), U10.4 (QE)
unnamed: D77.1 (K), R77.2
unnamed: D78.2 (A), U10.5 (QF)
unnamed: D78.1 (K), R78.2
unnamed: D79.2 (A), U10.6 (QG)
unnamed: D79.1 (K), R79.2
unnamed: D80.2 (A), U10.7 (QH)
unnamed: D80.1 (K), R80.2
unnamed: D81.2 (A), U11.15 (QA)
unnamed: D81.1 (K), R81.2
unnamed: D82.2 (A), U11.1 (QB)
unnamed: D82.1 (K), R82.2
unnamed: D83.2 (A), U11.2 (QC)
unnamed: D83.1 (K), R83.2
unnamed: D84.2 (A), U11.3 (QD)
unnamed: D84.1 (K), R84.2
unnamed: D85.2 (A), U11.4 (QE)
unnamed: D85.1 (K), R85.2
unnamed: D86.2 (A), U11.5 (QF)
unnamed: D86.1 (K), R86.2
unnamed: D87.2 (A), U11.6 (QG)
unnamed: D87.1 (K), R87.2
unnamed: D88.2 (A), U11.7 (QH)
unnamed: D88.1 (K), R88.2
unnamed: D89.2 (A), U12.15 (QA)
unnamed: D89.1 (K), R89.2
unnamed: D90.2 (A), U12.1 (QB)
unnamed: D90.1 (K), R90.2
unnamed: D91.2 (A), U12.2 (QC)
unnamed: D91.1 (K), R91.2
unnamed: D92.2 (A), U12.3 (QD)
unnamed: D92.1 (K), R92.2
unnamed: D93.2 (A), U12.4 (QE)
unnamed: D93.1 (K), R93.2
unnamed: D94.2 (A), U12.5 (QF)
unnamed: D94.1 (K), R94.2
unnamed: D95.2 (A), U12.6 (QG)
unnamed: D95.1 (K), R95.2
unnamed: D96.2 (A), U12.7 (QH)
unnamed: D96.1 (K), R96.2
unnamed: D97.2 (A), U13.15 (QA)
unnamed: D97.1 (K), R97.2
unnamed: D98.2 (A), U13.1 (QB)
unnamed: D98.1 (K), R98.2
unnamed: D99.2 (A), U13.2 (QC)
unnamed: D99.1 (K), R99.2
unnamed: D100.2 (A), U13.3 (QD)
unnamed: D100.1 (K), R100.2
unnamed: D101.2 (A), U13.4 (QE)
unnamed: D101.1 (K), R101.2
unnamed: D102.2 (A), U13.5 (QF)
unnamed: D102.1 (K), R102.2
unnamed: D103.2 (A), U13.6 (QG)
unnamed: D103.1 (K), R103.2
unnamed: D104.2 (A), U13.7 (QH)
unnamed: D104.1 (K), R104.2
unnamed: D105.2 (A), U14.15 (QA)
unnamed: D105.1 (K), R105.2
unnamed: D106.2 (A), U14.1 (QB)
unnamed: D106.1 (K), R106.2
unnamed: D107.2 (A), U14.2 (QC)
unnamed: D107.1 (K), R107.2
unnamed: D108.2 (A), U14.3 (QD)
unnamed: D108.1 (K), R108.2
unnamed: D109.2 (A), U14.4 (QE)
unnamed: D109.1 (K), R109.2
unnamed: D110.2 (A), U14.5 (QF)
unnamed: D110.1 (K), R110.2
unnamed: D111.2 (A), U14.6 (QG)
unnamed: D111.1 (K), R111.2
unnamed: D112.2 (A), U14.7 (QH)
unnamed: D112.1 (K), R112.2
unnamed: D113.2 (A), U15.15 (QA)
unnamed: D113.1 (K), R113.2
unnamed: D114.2 (A), U15.1 (QB)
unnamed: D114.1 (K), R114.2
unnamed: D115.2 (A), U15.2 (QC)
unnamed: D115.1 (K), R115.2
unnamed: D116.2 (A), U15.3 (QD)
unnamed: D116.1 (K), R116.2
unnamed: D117.2 (A), U15.4 (QE)
unnamed: D117.1 (K), R117.2
unnamed: D118.2 (A), U15.5 (QF)
unnamed: D118.1 (K), R118.2
unnamed: D119.2 (A), U15.6 (QG)
unnamed: D119.1 (K), R119.2
unnamed: D120.2 (A), U15.7 (QH)
unnamed: D120.1 (K), R120.2
unnamed: D121.2 (A), U16.15 (QA)
unnamed: D121.1 (K), R121.2
unnamed: D122.2 (A), U16.1 (QB)
unnamed: D122.1 (K), R122.2
unnamed: D123.2 (A), U16.2 (QC)
unnamed: D123.1 (K), R123.2
unnamed: D124.2 (A), U16.3 (QD)
unnamed: D124.1 (K), R124.2
unnamed: D125.2 (A), U16.4 (QE)
unnamed: D125.1 (K), R125.2
unnamed: D126.2 (A), U16.5 (QF)
unnamed: D126.1 (K), R126.2
unnamed: D127.2 (A), U16.6 (QG)
unnamed: D127.1 (K), R127.2
unnamed: D128.2 (A), U16.7 (QH)
unnamed: D128.1 (K), R128.2
unnamed: D129.2 (A), U17.15 (QA)
unnamed: D129.1 (K), R129.2
unnamed: D130.2 (A), U17.1 (QB)
unnamed: D130.1 (K), R130.2
unnamed: D131.2 (A), U17.2 (QC)
unnamed: D131.1 (K), R131.2
unnamed: D132.2 (A), U17.3 (QD)
unnamed: D132.1 (K), R132.2
unnamed: D133.2 (A), U17.4 (QE)
unnamed: D133.1 (K), R133.2
unnamed: D134.2 (A), U17.5 (QF)
unnamed: D134.1 (K), R134.2
unnamed: D135.2 (A), U17.6 (QG)
unnamed: D135.1 (K), R135.2
unnamed: D136.2 (A), U17.7 (QH)
unnamed: D136.1 (K), R136.2
unnamed: D137.2 (A), U18.15 (QA)
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

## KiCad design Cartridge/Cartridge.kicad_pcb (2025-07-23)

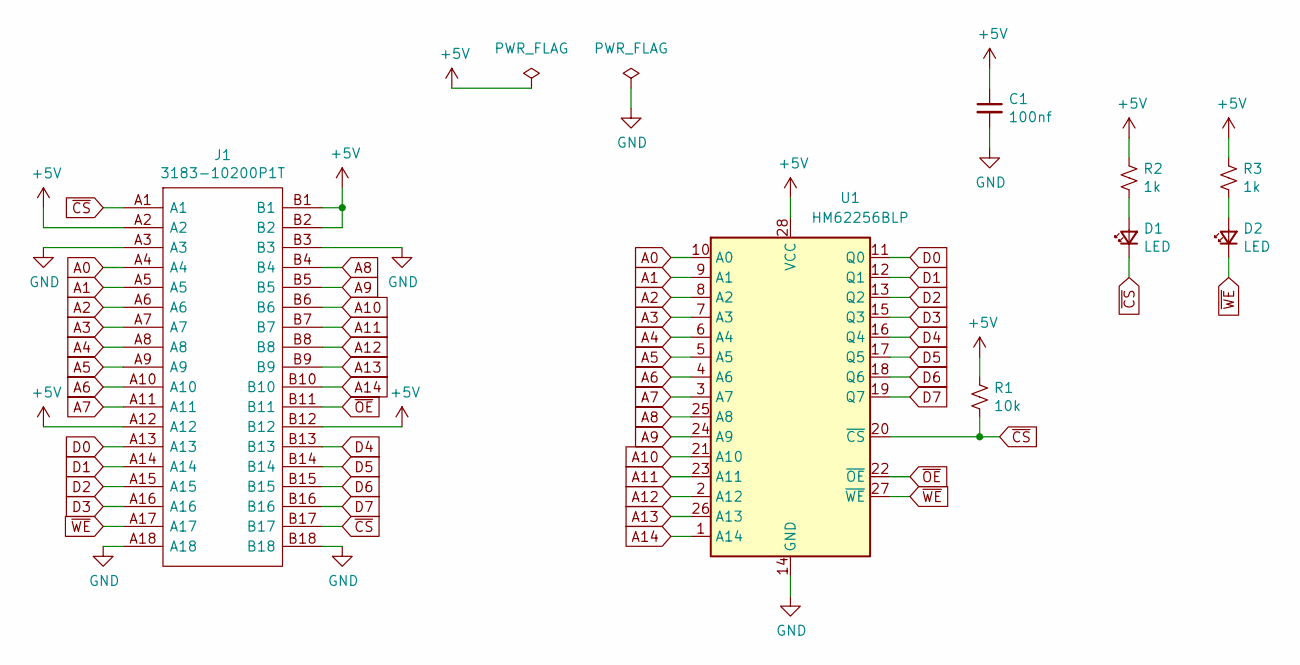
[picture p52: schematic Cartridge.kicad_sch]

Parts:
C1: 100nf; C_0603_1608Metric
D1, D2: LED; LED_0603_1608Metric
J1: 3183-10200P1T; BUS_PCIexpress_x1; Manufacturer_Part_Number 3183-10200P1T
R1: 10k; R_0603_1608Metric
R2, R3: 1k; R_0603_1608Metric
U1: HM62256BLP; SOIC-28W_7.5x17.9mm_P1.27mm

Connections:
+5V: C1.1, J1.A2, J1.A12, J1.B1, J1.B2, J1.B12, R1.1, R2.1, R3.1, U1.28 (VCC)
A0: J1.A4, U1.10 (A0)
A1: J1.A5, U1.9 (A1)
A2: J1.A6, U1.8 (A2)
A3: J1.A7, U1.7 (A3)
A4: J1.A8, U1.6 (A4)
A5: J1.A9, U1.5 (A5)
A6: J1.A10, U1.4 (A6)
A7: J1.A11, U1.3 (A7)
A8: J1.B4, U1.25 (A8)
A9: J1.B5, U1.24 (A9)
A10: J1.B6, U1.21 (A10)
A11: J1.B7, U1.23 (A11)
A12: J1.B8, U1.2 (A12)
A13: J1.B9, U1.26 (A13)
A14: J1.B10, U1.1 (A14)
D0: J1.A13, U1.11 (Q0)
D1: J1.A14, U1.12 (Q1)
D2: J1.A15, U1.13 (Q2)
D3: J1.A16, U1.15 (Q3)
D4: J1.B13, U1.16 (Q4)
D5: J1.B14, U1.17 (Q5)
D6: J1.B15, U1.18 (Q6)
D7: J1.B16, U1.19 (Q7)
GND: C1.2, J1.A3, J1.A18, J1.B3, J1.B18, U1.14 (GND)
unnamed: D1.2 (A), R2.2
unnamed: D2.2 (A), R3.2
~CS: D1.1 (K), J1.A1, J1.B17, R1.2, U1.20 (~CS)
~OE: J1.B11, U1.22 (~OE)
~WE: D2.1 (K), J1.A17, U1.27 (~WE)


Board: 2 copper layers, 27.2 x 30.9 mm, 8 parts (0 on the bottom side), 30 nets.

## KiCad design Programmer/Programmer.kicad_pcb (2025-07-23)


Board: 2 copper layers, 99.6 x 59.9 mm, 110 parts (0 on the bottom side), 82 nets.

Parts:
16MHz1: Resonator; OSC_CSTCE16M0V53-R0
C1, C2, C3, C4, C6: 4.7uF; C_0402_1005Metric
C5, C7: 0.1uF; C_0402_1005Metric
C8, C9, C10, C11, C12, C13: 0.1uF; C_0603_1608Metric
D1, D4: GREEN; LED_0603_1608Metric
D2: SP0503BAHT; SOT-143
D3: RED; LED_0603_1608Metric
D5, D6, D7, D8, D9, D10, D11, D12, D13, D14, D15, D16, D17, D18, D19, D20, D21, D22, D23, D24, D25, D26, D27, D28, D29: LED; LED_0603_1608Metric
HOLE1, HOLE2, HOLE3, HOLE4: MountingHole_2.2mm_M2_DIN965_Pad
J1: USB_C_Receptacle_USB2.0; USB_C_Receptacle_G-Switch_GT-USB-7010ASV
J2, J3: Conn_01x22; PinSocket_1x22_P2.54mm_Horizontal
J4: Conn_01x16; PinHeader_1x16_P2.54mm_Horizontal
J5: 3183-10200P1T; 318310200P1T
J6: Conn_02x04_Odd_Even; PinHeader_2x04_P2.54mm_Vertical
R1, R9: 47k; R_0603_1608Metric
R2, R8, R10, R11, R12, R13, R14, R15, R16, R17, R18, R19, R20, R21, R22, R23, R24, R25, R26, R27, R28, R29, R30, R31, R32, R33, R34: 10k; R_0603_1608Metric
R3, R4: 5.1k; R_0603_1608Metric
R5: 22.1k; R_0402_1005Metric
R6: 47.5k; R_0402_1005Metric
R7: 1k; R_0402_1005Metric
R35, R36, R37, R38, R39, R40, R41, R42, R43, R44, R45, R46: 10k; R_0402_1005Metric
SW1: RESET; SW_TS-1088-AR02016
SW2: PAUSE; SW_TS-1088-AR02016
SW3: STEP; SW_TS-1088-AR02016
SW4: CONTINUE; SW_TS-1088-AR02016
U1: ATMEGA328-AU; TQFP-32_7x7mm_P0.8mm
U2: CP2102N-Axx-xQFN24; QFN-24-1EP_4x4mm_P0.5mm_EP2.6x2.6mm
U3: HM62256BLP; DIP-28_W15.24mm_Socket
U4, U5, U6, U7: 74HC161; SOIC-16_3.9x9.9mm_P1.27mm

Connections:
A0: D5.2 (A), J2.5, J3.18, J5.A4, U3.10 (A0), U4.14 (Q0)
A1: D6.2 (A), J2.6, J3.17, J5.A5, U3.9 (A1), U4.13 (Q1)
A2: D7.2 (A), J2.7, J3.16, J5.A6, U3.8 (A2), U4.12 (Q2)
A3: D8.2 (A), J2.8, J3.15, J5.A7, U3.7 (A3), U4.11 (Q3)
A4: D9.2 (A), J2.9, J3.14, J5.A8, U3.6 (A4), U5.14 (Q0)
A5: D10.2 (A), J2.10, J3.13, J5.A9, U3.5 (A5), U5.13 (Q1)
A6: D11.2 (A), J2.11, J3.12, J5.A10, U3.4 (A6), U5.12 (Q2)
A7: D12.2 (A), J2.12, J3.11, J5.A11, U3.3 (A7), U5.11 (Q3)
A8: D13.2 (A), J2.13, J3.10, J5.B4, U3.25 (A8), U6.14 (Q0)
A9: D14.2 (A), J2.14, J3.9, J5.B5, U3.24 (A9), U6.13 (Q1)
A10: D15.2 (A), J5.B6, U3.21 (A10), U6.12 (Q2)
A11: D16.2 (A), J5.B7, U3.23 (A11), U6.11 (Q3)
A12: D17.2 (A), J5.B8, U3.2 (A12), U7.14 (Q0)
A13: D18.2 (A), J5.B9, U3.26 (A13), U7.13 (Q1)
A14: D19.2 (A), J5.B10, U3.1 (A14), U7.12 (Q2)
A15: D20.2 (A), U7.11 (Q3)
ADDR_CLOCK: R45.2, U1.23 (PC0), U4.2 (CP), U5.2 (CP), U6.2 (CP), U7.2 (CP)
ADDR_COUNT: R46.2, U1.24 (PC1), U4.7 (CEP), U4.10 (CET)
BUS0: D21.2 (A), J2.15, J3.8, J4.9, J5.A13, R35.2, U1.32 (PD2), U3.11 (Q0), U4.3 (D0), U6.3 (D0)
BUS1: D22.2 (A), J2.16, J3.7, J4.10, J5.A14, R36.2, U1.1 (PD3), U3.12 (Q1), U4.4 (D1), U6.4 (D1)
BUS2: D23.2 (A), J2.17, J3.6, J4.11, J5.A15, R37.2, U1.2 (PD4), U3.13 (Q2), U4.5 (D2), U6.5 (D2)
BUS3: D24.2 (A), J2.18, J3.5, J4.12, J5.A16, R38.2, U1.9 (PD5), U3.15 (Q3), U4.6 (D3), U6.6 (D3)
BUS4: D25.2 (A), J2.19, J3.4, J4.13, J5.B13, R39.2, U1.10 (PD6), U3.16 (Q4), U5.3 (D0), U7.3 (D0)
BUS5: D26.2 (A), J2.20, J3.3, J4.14, J5.B14, R40.2, U1.11 (PD7), U3.17 (Q5), U5.4 (D1), U7.4 (D1)
BUS6: D27.2 (A), J2.21, J3.2, J4.15, J5.B15, R41.2, U1.12 (PB0), U3.18 (Q6), U5.5 (D2), U7.5 (D2)
BUS7: D28.2 (A), J2.22, J3.1, J4.16, J5.B16, R42.2, U1.13 (PB1), U3.19 (Q7), U5.6 (D3), U7.6 (D3)
GND: 16MHz1.2, C1.1, C2.1, C3.1, C4.1, C5.1, C6.1, C7.1, C9.2, C10.2, C11.2, C12.2, C13.2, D2.1 (A), J1.A12 (GND), J1.B12 (GND), J2.1, J3.22, J4.1, J5.A3, J5.A18, J5.B3, J5.B18, J6.6, R1.1, R3.1, R4.1, R6.2, R10.2, R11.2, R12.2, R13.2, R14.2, R15.2, R16.2, R17.2, R18.2, R19.2, R20.2, R21.2, R22.2, R23.2, R24.2, R25.2, R26.2, R27.2, R28.2, R29.2, R30.2, R31.2, R32.2, R33.2, R34.2, R35.1, R36.1, R37.1, R38.1, R39.1, R40.1, R41.1, R42.1, R45.1, R46.1, SW1.1, SW2.1, SW3.1, SW4.1, U1.3 (GND), U1.5 (GND), U1.21 (GND), U2.2 (GND), U2.25 (GND), U3.14 (GND), U4.8 (GND), U5.8 (GND), U6.8 (GND), U7.8 (GND)
GPIO10: J4.5, J5.A17, U1.14 (PB2), U3.27 (~WE)
GPIO11: J4.6, J6.4, SW2.2, U1.15 (PB3)
GPIO12: J4.7, J6.1, SW3.2, U1.16 (PB4)
GPIO13: J4.8, J6.3, SW4.2, U1.17 (PB5)
GPIO18: D29.2 (A), J2.4, J3.19, J4.4, J5.A1, J5.B17, U1.27 (PC4), U3.20 (~CS)
GPIO19: J2.3, J3.20, J4.3, J5.B11, U1.28 (PC5), U3.22 (~OE)
unnamed: D1.1 (K), R1.2
unnamed: C6.2, C7.2, D3.2 (A), D4.2 (A), R7.1, U2.5 (VIO), U2.6 (VDD)
unnamed: D3.1 (K), R8.1
unnamed: D4.1 (K), R9.1
unnamed: D5.1 (K), R10.1
unnamed: D6.1 (K), R11.1
unnamed: D7.1 (K), R12.1
unnamed: D8.1 (K), R13.1
unnamed: D9.1 (K), R14.1
unnamed: D10.1 (K), R15.1
unnamed: D11.1 (K), R16.1
unnamed: D12.1 (K), R17.1
unnamed: D13.1 (K), R18.1
unnamed: D14.1 (K), R19.1
unnamed: D15.1 (K), R20.1
unnamed: D16.1 (K), R21.1
unnamed: D17.1 (K), R22.1
unnamed: D18.1 (K), R23.1
unnamed: D19.1 (K), R24.1
unnamed: D20.1 (K), R25.1
unnamed: D21.1 (K), R26.1
unnamed: D22.1 (K), R27.1
unnamed: D23.1 (K), R28.1
unnamed: D24.1 (K), R29.1
unnamed: D25.1 (K), R30.1
unnamed: D26.1 (K), R31.1
unnamed: D27.1 (K), R32.1
unnamed: D28.1 (K), R33.1
unnamed: D29.1 (K), R34.1
unnamed: J1.A5 (CC1), R4.2
unnamed: J1.B5 (CC2), R3.2
unnamed: D2.2 (K), J1.A6 (D+), J1.B6 (D+), U2.3 (D+)
unnamed: D2.3 (K), J1.A7 (D-), J1.B7 (D-), U2.4 (D-)
unnamed: R5.2, R6.1, U2.8 (VBUS)
unnamed: C8.1, U2.23 (~DTR)
unnamed: R7.2, U2.9 (~RST)
unnamed: R9.2, U2.13 (~RXT/GPIO.1)
unnamed: R8.2, U2.14 (~TXT/GPIO.0)
unnamed: U4.15 (TC), U5.7 (CEP), U5.10 (CET)
unnamed: U5.15 (TC), U6.7 (CEP), U6.10 (CET)
unnamed: U6.15 (TC), U7.7 (CEP), U7.10 (CET)
RXD: J6.8, U1.31 (PD1), U2.20 (RXD)
TXD: J6.7, U1.30 (PD0), U2.21 (TXD)
VCC: C1.2, C2.2, C3.2, C4.2, C5.2, C9.1, C10.1, C11.1, C12.1, C13.1, D1.2 (A), D2.4 (K), J1.A9 (VBUS), J1.B9 (VBUS), J2.2, J3.21, J4.2, J5.A2, J5.A12, J5.B1, J5.B2, J5.B12, J6.2, R2.2, R5.1, R43.2, R44.2, U1.4 (VCC), U1.6 (VCC), U1.18 (AVCC), U2.7 (VREGIN), U3.28 (VCC), U4.16 (VCC), U5.16 (VCC), U6.16 (VCC), U7.16 (VCC)
XTAL1: 16MHz1.1, U1.7 (PB6)
XTAL2: 16MHz1.3, U1.8 (PB7)
~ADDR_PE_0: R43.1, U1.26 (PC3), U4.9 (~PE), U5.9 (~PE)
~ADDR_PE_1: R44.1, U1.25 (PC2), U6.9 (~PE), U7.9 (~PE)
~RESET: C8.2, J6.5, R2.1, SW1.2, U1.29 (PC6), U4.1 (~MR), U5.1 (~MR), U6.1 (~MR), U7.1 (~MR)

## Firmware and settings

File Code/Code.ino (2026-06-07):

#include "signals.h"
#include "instruction_set.h"
#include "programs.h"
#include "spork_8.h"
#include "spork_8_state.h"
#include "programmer.h"
#include "instructions.h"

Spork8::WriteCallback verifyCallback = NULL;

bool writeSuccessful = true;

void setup() {
  Serial.begin(57600);
//  read256();
//  writeMicrocode(false);
//  writeMicrocode(true);
//  disableSDP();
  writeProgram();
//  testBus();
//  emulate();
}

void loop() {
  // put your main code here, to run repeatedly:
}

Spork8 getNewSpork8() {
  Spork8Config conf = {
    .memoryIndex = 1,
    .counterIndex = 0,
    .selfIndex = 2,

    .resetPin = 2,
    .clockPin = 3,
    .inIndexPins = {4, 5, 6},
    .outIndexPins = {7, 8, 9},
    .sharedSignalPins = {10, 11, 255, 255},
    .busPins = {12, 13, A0, A1, A2, A3, A4, A5}
  };

  Spork8 spork8 = Spork8(conf);
  spork8.setPinModes();
  return spork8;
}

Programmer getNewProgrammer(bool cpuMode = false) {
  ProgrammerConfig conf = {
    .busPins = {2, 3, 4, 5, 6, 7, 8, 9},
    .weClockPin = 10,
    .pauseButtonPin = 11,
    .stepButtonPin = 12,
    .continueButtonPin = 13,
    .addrClockPin = 14,
    .addrCountPin = 15,
    .addrPE0Pin = 17,
    .addrPE1Pin = 16,
    .eepromCEPin = 18,
    .eepromOEPin = 19,
  };

  Programmer programmer = Programmer(conf);
  programmer.setPinModes(cpuMode);
  return programmer;
}

void testBus() {
  Programmer programmer = getNewProgrammer();
  programmer.setBusMode(OUTPUT);
  programmer.setBus(0b00000001);
  delay(1000);
  programmer.setBus(0b00000010);
  delay(1000);
  programmer.setBus(0b00000100);
  delay(1000);
  programmer.setBus(0b00001000);
  delay(1000);
  programmer.setBus(0b00010000);
  delay(1000);
  programmer.setBus(0b00100000);
  delay(1000);
  programmer.setBus(0b01000000);
  delay(1000);
  programmer.setBus(0b10000000);
  delay(1000);
}

uint8_t emulatorGetProgmemByte(uint16_t address) {
  uint8_t value = (address & 0x8000) ? getMovingDotByte(address ^ 0x8000) : getJumpToCartridgeByte(address);
  return value;
}

uint8_t *emulator_memory = nullptr;
uint16_t emulator_memory_size = 0;
uint8_t emulator_ram_pages = 0;
uint8_t emulator_ram_page_size = 0;
uint8_t emulatorGetRamByte(uint16_t address) {
  uint8_t page = address >> 8;
  uint8_t addr = address & 0xFF;
  if (page < emulator_ram_pages && addr < emulator_ram_page_size) {
    return emulator_memory[page * emulator_ram_page_size];
  } else {
    return 0;
  }
}
void emulatorSetRamByte(uint16_t address, uint8_t value) {
  uint8_t page = address >> 8;
  uint8_t addr = address & 0xFF;
  if (page < emulator_ram_pages && addr < emulator_ram_page_size) {
    emulator_memory[page * emulator_ram_page_size] = value;
  }
}

void emulate() {
  Programmer programmer = getNewProgrammer(true);
  Serial.println("Emulator");

  const uint8_t pages = 2;
  const uint8_t page_size = 32;
  uint8_t ram_buffer[pages * page_size];
  emulator_memory = ram_buffer;
  emulator_memory_size = sizeof(ram_buffer) / sizeof(*ram_buffer);
  uint8_t emulator_ram_pages = pages;
  uint8_t emulator_ram_page_size = page_size;

  Spork8State state = Spork8State();
  spork8_state_reset(&state);
  state.get_progmem_byte = emulatorGetProgmemByte;
  state.get_ram_byte = emulatorGetRamByte;
  state.set_ram_byte = emulatorSetRamByte;
  spork8_state_cycle(&state);

  programmer.resetCPU();

  while (true) {
    // Get signal values.
    bool sig_out = programmer.getCPUSigOut();

    // TODO: Verify signal values are as expected.

    // Set bus mode and value if output is enabled.
    if (sig_out) {
      programmer.setBusMode(OUTPUT);
      programmer.setBus(state.bus);
      Serial.print("Bus: ");
      Serial.print(state.bus, HEX);
      Serial.print(" (output)\n");

    // Verify bus is as expected if not outputting to it.
    } else {
      programmer.setBusMode(INPUT);
      uint8_t bus = programmer.readBus(false);
      Serial.print("Bus: virtual ");
      Serial.print(state.bus, HEX);
      Serial.print(" real ");
      Serial.print(bus, HEX);
      Serial.print("\n");
      // if (state.bus != bus) {
      //   break;
      // }
    }

    // Set clock to high to "do" the cycle, and cycle the state.
    delay(500);
    programmer.setCPUClock(HIGH);
    delay(500);
    spork8_state_cycle(&state);

    // Set clock to low again. Don't delay here, because we want to change bus output
    // mode ASAP after reading SIG_OUT, since this is when signals update.
    programmer.setCPUClock(LOW);
  }
  Serial.println("Found difference");
  // Just in case, set bus mode to INPUT.
  programmer.setBusMode(INPUT);
  while (true) {}
}

void read256() {
  Programmer programmer = getNewProgrammer();
  programmer.readRange(0, 1 << 8, printMemoryByte);
}

void disableSDP() {
  Programmer programmer = getNewProgrammer();
  programmer.writeAddress(0x5555, 0xAA, false);
  programmer.writeAddress(0x2AAA, 0x55, false);
  programmer.writeAddress(0x5555, 0x80, false);
  programmer.writeAddress(0x5555, 0xAA, false);
  programmer.writeAddress(0x2AAA, 0x55, false);
  programmer.writeAddress(0x5555, 0x20, false);
}

void writeProgram() {
  Programmer programmer = getNewProgrammer();

  Serial.println("Writing program");
  verifyCallback = getSnakeByte;
  programmer.writeRange(0, 1 << 10, verifyCallback, false);
  Serial.println("Reading");
  programmer.readRange(0, 1 << 10, printAndVerifyByte, false);
  digitalWrite(programmer.conf.eepromCEPin, writeSuccessful);
}

void writeMicrocode(bool highBytes) {
  Serial.println("Writing microcode");
  Programmer programmer = getNewProgrammer();
  Programmer::WriteCallback callback = highBytes ? getMicrocodeHighByte : getMicrocodeLowByte;
  uint16_t start = 0; // 0x1780;
  uint16_t end = 1 << 15; // 0x1A40;
  programmer.writeRange(start, end - start, callback);
  Serial.println("Reading");
  verifyCallback = callback;
  programmer.readRange(start, end - start, printAndVerifyByte);
  digitalWrite(programmer.conf.eepromCEPin, writeSuccessful);
}

void printMicrocode() {  
  for (int i = 0; i < 1 << 13; i++) {
    printMemoryByte(i, getMicrocodeLowByte(i));
  }
  Serial.print("\n\n");
  for (int i = 0; i < 1 << 13; i++) {
    printMemoryByte(i, getMicrocodeHighByte(i));
  }
}

void printMemoryByte(uint16_t address, byte value) {
  if (address != 0 && address % 64 == 0) {
    Serial.print('\n');
  }
  if (address % 64 == 0) {
    Serial.print(address, HEX);
    Serial.print(": ");
  }
  if (value < 16) {
    Serial.print('0'); // leading zero
  }
  Serial.print(value, HEX);
}

void printAndVerifyByte(uint16_t address, byte value) {
  // printMemoryByte(address, verifyCallback(address));
  byte expectedValue = verifyCallback(address);
  printMemoryByte(address, value);
  if (expectedValue != value) {
    writeSuccessful = false;
    Serial.print("(");
    if (expectedValue < 16) {
      Serial.print('0'); // leading zero
    }
    Serial.print(expectedValue, HEX);
    Serial.print(")");
  }
}

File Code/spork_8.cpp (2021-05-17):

#include "spork_8.h"

// Delay in microseconds when cycling reset, or allowing for setup time.
// 1 is equivalent to a 1MHz clock.
static const int standardDelayTime = 1;

static void standardDelay() {
  delayMicroseconds(standardDelayTime);
}

static const int pageWriteDelay = 11; // ms
static const uint16_t pageMask = 0b1111111000000;
static const int pageSize = 64;

void Spork8::setPinModes() {
  pinMode(conf.resetPin, OUTPUT);
  pinMode(conf.clockPin, OUTPUT);
  for (int i = 0; i < 3; i++) {
    pinMode(conf.inIndexPins[i], OUTPUT);
    pinMode(conf.outIndexPins[i], OUTPUT);
  }
  for (int i = 0; i < 4; i++) {
    pinMode(conf.sharedSignalPins[i], OUTPUT);
  }
  setBusMode(INPUT);
}

void Spork8::writeRange(uint16_t start, uint16_t len, WriteCallback callback, bool reverseBits) {
  setCounterValue(start);
  setInIndex(conf.memoryIndex);
  setOutIndex(conf.selfIndex);
  setCounterModes(false, false);
  standardDelay(); // Setup time
  setBusMode(OUTPUT);
  
  uint8_t page_cache[64];
  for (uint16_t i = 0; i < len; i++) {
    uint16_t addr = start + i;

    // At the beginning of a page, pre-calculate the whole page to make writes fast enough
    if (i == 0 || addr % pageSize == 0) {
      for (int p = addr; (p & pageMask) == (addr & pageMask); p++) {
        page_cache[p % pageSize] = callback(p);
      }
    }
    
    byte value = page_cache[addr % pageSize];
    setBus(value, reverseBits);
    cycleClock(); // Write current address

    if (((addr + 1) & pageMask) != (addr & pageMask)) {
      delay(pageWriteDelay);
    }

    if (i != len - 1) { // Don't count on final address
      setCounterModes(true, false);
      setInIndex(conf.selfIndex);
      cycleClock(); // Go to next address
      setInIndex(conf.memoryIndex);
      setCounterModes(false, false);
    }
  }
  setBusMode(INPUT);
}

void Spork8::readRange(uint16_t start, uint16_t len, ReadCallback callback, bool reverseBits) {
  setCounterValue(start);
  setInIndex(conf.selfIndex);
  setOutIndex(conf.memoryIndex);
  setCounterModes(true, false);
  setBusMode(INPUT);
  for (uint16_t i = 0; i < len; i++) {
    standardDelay(); // Setup time
    byte value = readBus(reverseBits);
    callback(start + i, value);
    if (i != len - 1) { // Don't count on final address
      cycleClock();
    }
  }
}

void Spork8::writeAddress(uint16_t address, byte value, bool reverseBits) {
  setCounterValue(address);
  setOutIndex(conf.selfIndex);
  setInIndex(conf.memoryIndex);
  setBusMode(OUTPUT);
  setBus(value, reverseBits);
  standardDelay(); // Setup time
  cycleClock();
  setBusMode(INPUT);
}

byte Spork8::readAddress(uint16_t address, bool reverseBits) {
  setCounterValue(address);
  setInIndex(conf.selfIndex);
  setOutIndex(conf.memoryIndex);
  setBusMode(INPUT);
  return readBus(reverseBits);
}

void Spork8::cycleClock() {
  digitalWrite(conf.clockPin, HIGH);
  digitalWrite(conf.clockPin, LOW);
}

void Spork8::reset() {
  digitalWrite(conf.resetPin, HIGH);
  standardDelay();
  digitalWrite(conf.resetPin, LOW);
}

void Spork8::setInIndex(byte index) {
  for (int i = 0; i < 3; i++) {
    digitalWrite(conf.inIndexPins[i], index & (0b100 >> i));
  }
}

void Spork8::setOutIndex(byte index) {
  for (int i = 0; i < 3; i++) {
    digitalWrite(conf.outIndexPins[i], index & (0b100 >> i));
  }
}

void Spork8::setCounterValue(uint16_t value) {
  setOutIndex(conf.selfIndex);
  setInIndex(conf.counterIndex);
  setBusMode(OUTPUT);
  setCounterModes(false, false);
  setBus(value & 0xFF, true);
  cycleClock();
  setCounterModes(false, true);
  setBus((value >> 8) & 0xFF, true);
  cycleClock();
  setBusMode(INPUT);
}

void Spork8::setBus(byte value, bool reverseBits) {
  for (int i = 0; i < 8; i++) {
    bool b = reverseBits ? (value & 1 << i) : (value & (0b10000000 >> i));
    digitalWrite(conf.busPins[i], b);
  }
}

byte Spork8::readBus(bool reverseBits) {
  byte value = 0;
  for (int i = 0; i < 8; i++) {
    byte b = reverseBits ? digitalRead(conf.busPins[i]) << i : digitalRead(conf.busPins[i]) << (7 - i);
    value |= b;
  }
  return value;
}

void Spork8::setBusMode(int mode) {
  for (int i = 0; i < 8; i++) {
    pinMode(conf.busPins[i], mode);
  }
}

void Spork8::setCounterModes(bool countEnable, bool byteSelect) {
  // If the index of the counter is odd, then it's in a bottom slot
  bool onBottom = conf.counterIndex & 1;
  byte countEnablePin = conf.sharedSignalPins[onBottom ? 2 : 0];
  byte byteSelectPin = conf.sharedSignalPins[onBottom ? 3 : 1];
  digitalWrite(countEnablePin, countEnable);
  digitalWrite(byteSelectPin, byteSelect);
}

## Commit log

2021-02-09 Add design images
    [ALU.dsn, ALU.kicad_pcb, ALU.sch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]
2021-02-09 Fix case of image URLs in readme
2021-02-09 Add text about empty module slots to readme
2021-03-09 Fixed floating inputs; improved power; added parts list; replaced JK latches
    [ALU.kicad_pcb, ALU.sch, Bus.dsn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]
2021-03-09 Update annotation of new chips on clock module
    [Clock.kicad_pcb]
2021-04-14 Revise control and RAM modules
    - Change control signals on low going clock
    - Pull down control signals with 1k resistors
    - AND the write signal with clock on RAM / ROM module
    [Control Module.dsn, Control Module.kicad_pcb, Control Module.sch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]
2021-04-24 Untested code to write to EEPROMs using Spork8 modules and Arduino
2021-04-25 Fix reversed headers on ALU, and counting issues on counter (CET / CEP connections)
    [ALU.dsn, ALU.kicad_pcb, ALU.sch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]
2021-04-25 Working Arduino / Spork8 memory test code
2021-05-16 Some refactors and fixes to instruction set and main code
    [Code.ino]
2021-05-17 Fixes to microcode and program; optimize RAM use and speed for EEPROM writing
    [Code.ino, spork_8.cpp]
2025-06-30 Control module sch: remove auto-MI reset; remove control line pull-downs; instruction register, 273 -> 2x173
    [Control Module.sch]
2025-06-30 Update all boards to r3, and update revision log and gitignore
    [ALU.dsn, ALU.kicad_pcb, ALU.kicad_sch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]
2025-07-23 Add 7 new board designs
    [Battery r3 BOM.csv, Battery.kicad_pcb, Battery.kicad_sch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]
2025-12-08 Update code for 74HC-based CPU and programmer board
2026-01-19 Random file PCB updates
    [Battery.kicad_pcb]
2026-01-19 Add assembly programs
2026-01-31 Use clock LED to signify write success on programmer
2026-01-31 Update programs and function signature in Arduino code
2026-04-21 Update programs.cpp with current asm content
2026-05-02 Make bus board 4L with ground planes and extra GND connectors
    [Bus.kicad_pcb, Bus.kicad_sch]
2026-06-07 Fix some bugs with the instruction set update; use Call / Return in Snake
    [Code.ino]
2026-08-04 Add support for two 8-bit arguments in assembly
2026-08-15 Update clock module to new KiCAD version; delete old files
    [Clock.dsn, Clock.kicad_pcb, Clock.kicad_sch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]
2026-08-15 Make Control Module 4 layers, and add 2 GND pins per side
    [Bus Interface.kicad_sch, Control Module.kicad_pcb, Control Module.kicad_sch]
2026-08-15 Update revision log and readme to reflect current status
2026-09-06 Add minimal Zig program, and ultrasonic sensor program
